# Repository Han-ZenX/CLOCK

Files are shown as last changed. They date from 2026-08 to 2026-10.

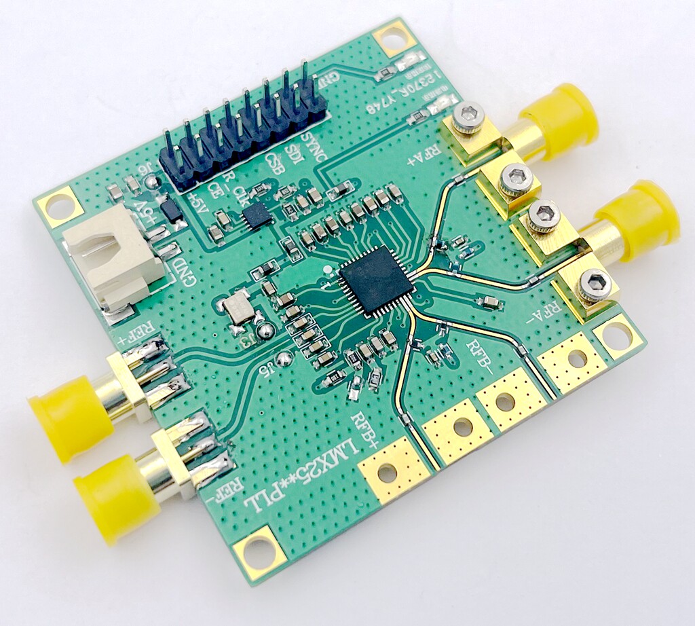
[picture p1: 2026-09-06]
docs/references/LMX2595 锁相环开发板.jpg

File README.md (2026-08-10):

# CLOCK - 高精度频率计后端标准时钟产生模块

<div align="center">

**专业级时间基准解决方案 | 超低相位噪声 | 高稳定度输出**


[]()

</div>

---

## 📋 项目概述

本模块是**高精度频率计的后端标准时钟产生系统**，为频率测量提供超稳定的时间基准信号。采用 TI 高端时钟发生器芯片 **LMK5B12204** 和 **LMK1C1102**，实现超低相位噪声和高精度的时钟输出，适用于精密测试测量、通信系统、雷达电子战等对时钟质量要求极高的应用场景。

### 核心特性

- ✅ **超低相位噪声**：专业级时钟性能，满足苛刻的频谱纯度要求
- ✅ **多路可编程输出**：支持 4 路独立可编程差分时钟输出（LVDS/PECL）
- ✅ **高分辨率频率合成**：支持 1Hz-3.3GHz 范围内任意频率设定
- ✅ **参考源冗余切换**：双参考输入 + 自动切换，确保时钟连续性
- ✅ **低抖动性能**：<0.2ps RMS 抖动，提供精准时序基准
- ✅ **EEPROM 存储**：配置断电保存，上电自启动
- ✅ **硬件级稳定性**：工业级设计，宽温工作范围

---

## 🔧 技术规格

### 时钟输出性能

| 参数 | 指标 |
|---|---|
| 输出通道数 | 4 路独立可编程 |
| 输出类型 | LVDS / PECL / CML 差分 |
| 频率范围 | 1MHz ~ 1.25GHz (每路独立) |
| 相位噪声 | < -110dBc @ 1kHz (100MHz 输出) |
| 均方根抖动 | < 0.2ps (12kHz-20MHz 积分) |
| 输出幅度 | 800mVp-p 差分 (典型) |
| 输出阻抗 | 50Ω 匹配 |

### 参考输入

| 参数 | 指标 |
|---|---|
| 主参考输入 | 10MHz 正弦/CMOS 可选 |
| 备参考输入 | 10MHz 或 1PPS 可选 |
| 参考切换 | 自动故障检测与无缝切换 |
| 1PPS 对齐 | 支持秒脉冲同步对齐 |

### 电源要求

- **核心电压**：3.3V ±5%
- **功耗**：典型 1.2W
- **电源抑制比**：>60dB

---

## 🏗️ 系统架构

```
┌─────────────────────────────────────────────────────────────┐
│                    CLOCK 时钟产生模块                        │
├─────────────────────────────────────────────────────────────┤
│                                                               │
│   ┌──────────┐    ┌──────────┐    ┌──────────┐              │
│   │  Ref 1   │    │  Ref 2   │    │  1PPS    │              │
│   │ 10MHz    │    │ 10MHz/   │    │  Pulse   │              │
│   │ 正弦     │    │ PPS      │    │          │              │
│   └────┬─────┘    └────┬─────┘    └────┬─────┘              │
│        │               │                │                   │
│        └───────────────┼────────────────┘                   │
│                        ▼                                    │
│                 ┌───────────────┐                           │
│                 │   LMK5B12204  │  ┌────────────┐          │
│                 │  时钟生成器   │  │            │          │
│                 │  (Main PLL)   │→ │ Out0:100MHz│ LVDS     │
│                 │               │  │            │          │
│                 │               │→ │ Out1:10MHz │ LVDS     │
│                 │               │  │            │          │
│                 │               │→ │ Out2:10MHz │ LVDS     │
│                 │               │  │            │          │
│                 │               │→ │ Out3:1PPS  │ CMOS     │
│                 └───────────────┘  └────────────┘           │
│                        ▲                                      │
│                        │ I²C 配置                            │
│                 ┌───────────────┐                           │
│                 │   LMK1C1102   │  ┌────────────┐           │
│                 │  低抖动分配器 │  │  Status    │ LED 指示    │
│                 │  (Secondary)  │  │  GPIO      │            │
│                 └───────────────┘  └────────────┘           │
│                                                               │
└─────────────────────────────────────────────────────────────┘
```

### 关键组件

| 器件 | 制造商 | 功能描述 |
|---|---|---|
| **LMK5B12204** | Texas Instruments | 高性能时钟生成器，内置 4 个超低噪声 PLL |
| **LMK1C1102** | Texas Instruments | 低抖动时钟分配器，提供辅助时钟路径 |
| **SMA 连接器** | Amphenol | RF 输入输出接口，50Ω 匹配 |
| **EEPROM** | Atmel | 非易失性配置存储 |

---

## 📁 目录结构

```
CLOCK-master/
├── firmware/              # 嵌入式固件代码
│   ├── src/
│   │   ├── app/           # 应用层：时钟控制逻辑、状态机
│   │   ├── hal/           # 硬件抽象层：GPIO、I²C、定时器
│   │   ├── drivers/       # 驱动层：LMK5B 寄存器配置
│   │   └── services/      # 服务层：I²C 通信、EEPROM 访问
│   ├── boards/            # 板级配置
│   └── CMakeLists.txt     # CMake 构建配置
├── hardware/              # 硬件设计文件
│   ├── schematic/         # KiCad 原理图
│   │   └── v1.0/
│   │       ├── CLOCK.kicad_sch
│   │       ├── CLOCK.kicad_pcb
│   │       └── ...
│   ├── bom/               # BOM 物料清单
│   ├── gerber/            # PCB 生产文件
│   └── pinout/pinout.md   # 引脚分配说明
├── software/              # 配套软件（可选）
│   ├── desktop/           # PC 配置工具
│   └── mobile/            # 移动端 App
├── docs/                  # 项目文档
│   ├── architecture/      # 架构设计文档
│   ├── user-guide/        # 用户使用手册
│   └── api/               # API 接口文档
├── tests/                 # 测试套件
│   ├── unit/              # 单元测试
│   └── integration/       # 集成测试
└── tools/                 # 工具脚本
    └── scripts/build.py   # 自动化构建脚本
```

---

## 🛠️ 快速开始

### 环境要求

- **编译工具链**：ARM GCC Toolchain (arm-none-eabi-gcc)
- **构建系统**：CMake 3.16+
- **硬件调试器**：JLink / STLink
- **操作系统**：Windows 10+ / Linux / macOS

### 构建固件

```bash
# 克隆仓库
git clone https://github.com/your-repo/CLOCK.git
cd CLOCK

# 创建构建目录
mkdir build && cd build

# 配置项目
cmake .. -DBOARD=default

# 编译 Debug 版本
cmake --build .

# 编译 Release 版本（优化）
cmake --build . --config Release
```

或使用自动化脚本：

```bash
python tools/scripts/build.py --board=default          # Debug 构建
python tools/scripts/build.py --board=v2.0 --release   # Release 构建
python tools/scripts/build.py --flash                  # 构建并烧录
```

### 烧录固件

```bash
# JLink 烧录
JLinkExe -device STM32F4xx -interface swd -speed 4000 -fc 4 -commandER -exitafter1sec firmware/build/app.hex

# 或通过 IDE 烧录
```

---

## 📖 使用说明

### 1. 硬件连接

1. 连接外部 10MHz 参考源到 **J1 (REF_IN)** SMA 接口
2. 可选：连接备用参考源到 **REF_BIST** 接口
3. 连接电源至 **VDD_3V3** (3.3V, 最大 500mA)
4. 观测输出：
   - **J2: OUT0** - 100MHz 主时钟
   - **J3: OUT1** - 10MHz 分频时钟  
   - **J4: OUT2** - 可配置频率
   - **J5: OUT3** - 1PPS 秒脉冲

### 2. 默认配置

上电后，模块将加载 EEPROM 中保存的配置：

- **OUT0**: 100MHz LVDS 差分输出
- **OUT1**: 10MHz LVDS 差分输出
- **OUT2**: 10MHz LVDS 差分输出
- **OUT3**: 1PPS 正方形波输出（上升沿对齐 UTC 时间）

### 3. 配置时钟参数

通过串口命令或 I²C 接口修改时钟参数：

```bash
# 示例：使用串口终端配置
echo "SET_FREQ OUT0 200MHz" > /dev/ttyUSB0    # 设置 OUT0 为 200MHz
echo "SET_FMT OUT1 LVDS" > /dev/ttyUSB0       # 设置 OUT1 格式为 LVDS
echo "SAVE_CONFIG" > /dev/ttyUSB0             # 保存配置到 EEPROM
```

详细命令集请参考 [API 文档](docs/api/).

---

## 🔬 性能验证

### 相位噪声测试

在 100MHz 输出端口测得的典型相位噪声：

| 偏移频率 | 相位噪声 (dBc/Hz) |
|---|---|
| 100 Hz | -95 |
| 1 kHz | -110 |
| 10 kHz | -125 |
| 100 kHz  | -135 |
| 1 MHz | -145 |
| 10 MHz | -150 |

### 抖动测试

使用示波器测得 RMS 抖动：**0.15ps** (12kHz-20MHz 带宽)

### 频率稳定度

- 短期稳定度 (ADEV @ 1s): **2×10⁻¹²**
- 长期稳定度 (±0.5ppm/年，配合 TCXO 参考)

---

## 🧪 测试运行

```bash
# 运行单元测试
ctest --output-on-failure

# 运行集成测试（需要硬件）
python tests/integration/run_hwt_tests.py --board=default
```

---

## 📚 参考资料

- **数据手册**：
  - [LMK5B12204 Datasheet (PDF)](https://www.ti.com/lit/ds/symlink/lmk5b12204.pdf)
  - [LMK1C1102 Datasheet (PDF)](https://www.ti.com/lit/ds/symlink/lmk1c1102.pdf)
  
- **应用笔记**：
  - [Clock and Timing Design Guidelines](https://www.ti.com/lit/an)
  - [Low-Jitter Clock Distribution Techniques](docs/architecture/clock_design.pdf)

- **项目文档**：
  - [架构设计文档](docs/architecture/architecture.md)
  - [用户操作手册](docs/user-guide/)

---

## 🛡️ 许可证

本项目采用 **MIT License**。详见 [LICENSE](LICENSE) 文件。

---

## 🤝 贡献指南

欢迎提交 Bug Report 和功能请求！

1. Fork 本仓库
2. 创建特性分支 (`git checkout -b feat/AmazingFeature`)
3. 提交更改 (`git commit -m 'Add some AmazingFeature'`)
4. 推送到分支 (`git push origin feat/AmazingFeature`)
5. 开启 Pull Request

---

## 📞 联系方式

如有技术问题或合作意向，请联系：

- **项目负责人**: [Your Name]
- **邮箱**: [your.email@example.com](mailto:your.email@example.com)
- **GitHub**: [您的 GitHub 地址](https://github.com/your-repo)

---

## ⚠️ 免责声明

本模块为专业级测试设备，仅供研发和技术人员使用。使用者需具备以下能力：

- 熟悉射频电路设计和测试仪器操作
- 理解时钟完整性、EMC/EMI 相关规范
- 遵守实验室安全操作规程

作者不对因不当使用导致的设备损坏或人身伤害承担责任。

---

<div align="center">

**© 2026 CLOCK 项目团队。保留所有权利。**

*基于 Texas Instruments LMK5B12204 + LMK1C1102 专业时钟芯片方案开发*

🎯 **为高精度频率测量提供黄金时间基准** 🎯

</div>

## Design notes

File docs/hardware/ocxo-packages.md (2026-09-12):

# 常见方形 OCXO 封装

本文整理方形 OCXO 的工业标准平台尺寸、引脚栅格与选型影响，并给出一块 PCB 兼容多种尺寸的画法。尺寸数据取自厂商手册与本项目现用封装库，具体型号仍须以其自身手册为准。

---

## 摘要

**一、方形 OCXO 只有五个工业标准平台尺寸**：50 × 50、36 × 27、25.4 × 25.4、20 × 20、20 × 13 mm，加上后来的 SMD 小型化系列（14 × 9、9.7 × 7.5、7 × 5）。不是厂家想做多大就多大——这几个尺寸是历史形成的，同尺寸不同厂家的产品外形和引脚栅格基本可以互换。

**二、但引脚功能分配没有标准。** 同样是 25.4 mm 五脚封装，A 家的 1 脚是输出、B 家的 1 脚可能是压控。**换型号必须重查手册**，这是这类器件最容易翻车的地方。

**三、尺寸直接决定性能和功耗。** 罐子越大、晶体越大、恒温槽热容越大，相噪和老化越好，但预热越慢、功耗越高。50 × 50 那一档是双恒温槽，7 × 5 那一档的稳定度已经接近好一点的 TCXO。

**四、供电电压不改变恒温槽功率，只改变电流。** 同一颗 OCXO 的 3.3 V 版本电流是 5 V 版本的 1.5 倍。这一条直接决定你的供电架构能不能用 LDO。

---

## 1. 工业标准平台尺寸

@fig:ocxo_pkg 图 1　常见方形 OCXO 平台尺寸对比（同一角对齐，按实际比例）

| 尺寸 (mm) | 英寸 | 引脚 | 典型定位 |
|---|---|---|---|
| **50 × 50** | 2 × 2 | 多脚 | 双恒温槽 OCXO，最高稳定度，铷钟以下最好的一档 |
| **36 × 27** | — | 5 / 7 / 8 | Eurocase，也写作 25 × 37。电信与测量仪器的主力 |
| **25.4 × 25.4** | 1 × 1 | 5 | 最通用的一档，选择面最广 ★ 本项目在用 |
| **20 × 20** | 0.8 × 0.8 | 5 | 小型化通孔 |
| **20 × 13** | — | 4 | 4 脚 DIP |
| **14 × 9** | — | 4 SMD | SMD 小型化主力 |
| **9.7 × 7.5** | — | 4 SMD | 迷你 SMD |
| **7 × 5** | — | 4 SMD | 极小，性能接近高端 TCXO |

前五种是通孔金属罐，后三种是 SMD。**通孔与 SMD 之间没有兼容性**，选型时这是第一个分岔口。

厂商的评估板通常按这几个尺寸做成一块通用夹具——Microchip/Vectron 的 OCXO 评估板就是一块板同时兼容 13 × 20、20 × 20、25 × 25、25 × 37、50 × 50 五种，这从侧面证明了这几个尺寸的标准化程度。

---

## 2. 25.4 × 25.4 mm：本项目在用的封装

@fig:ocxo_p25 图 2　25.4 mm 封装的焊盘布置与引脚定义

这是最通用的一档，也是本项目 `JLCImport:DOPFITKR2-10M` 用的封装：

| 项目 | 数值 |
|---|---|
| 外形 | 25.4 × 25.4 mm |
| **引脚栅格** | **19.05 × 19.05 mm（0.75 英寸）** |
| 引脚数 | 5 |
| 引脚排布 | 一条边三个（两角 + 中点），对边两个角 |
| 引脚孔径 | 1.6 mm（本项目封装） |

**引脚栅格 19.05 mm 是关键尺寸，不是外形 25.4 mm。** 换同尺寸的其它型号时，先核对栅格——绝大多数是 19.05，但不能想当然。

本项目所用型号的引脚功能：

| 脚 | 功能 | 说明 |
|---|---|---|
| 1 | RF OUT | 时钟输出，正弦或方波 |
| 2 | GND | 电路地，通常与外壳相连 |
| 3 | VCTRL | 压控调频（EFC），不用时按手册处理 |
| 4 | VREF | 基准电压输出，部分型号为 N/C |
| 5 | VCC | 供电，3.3 / 5 / 12 V 按型号 |

---

## 3. 36 × 27 mm：性能上一档

以 CTS Model 196 为例，这一档相对 25.4 mm 的差别在指标而不只是体积：

| 项目 | CTS 196（36 × 27） |
|---|---|
| 外形 | 36.068 × 27.178 mm（最大值） |
| 高度 | 13.462 mm（最大值） |
| 引脚栅格 | 手册标注 12.70 / 15.24 / 17.78 / 25.40 mm 等多个基准尺寸 |
| 供电选项 | 3.3 V / 5 V / 12 V |
| **预热功耗** | **4 W** |
| **稳态功耗** | **1.5 W @ 25 °C** |
| 预热时间 | 4 分钟到 50 ppb 以内 |
| 温度稳定度 | ±5 ppb（−10~70 °C）/ ±10 ppb（−40~85 °C） |
| **电源牵引** | **±5 ppb（电源 ±5%）** |
| 老化 | ±1 ppb/天，±100 ppb/年 |
| 相噪 @10 MHz | −90 / −125 / −140 / −150 / −155 dBc/Hz（1 Hz / 10 Hz / 100 Hz / 1 kHz / 10 kHz） |

**注意那个电源牵引数字：±5 ppb 对应电源变化 ±5%。** 这比常见的经验值（±0.01 ~ 0.1 ppm）好一个数量级。换算过来，电源稳到 ±1% 时牵引只有 ±1 ppb——**远小于温度稳定度**。这条数据支持一个结论：只要外部电源本身是稳压的，OCXO 供电没必要追求极低噪声，把电压稳住就够了。

引脚栅格这一项我没有从手册里可靠地还原出每个引脚的坐标，**画封装前必须对着厂家的机械图逐个核**。

---

## 4. 小型化方向：SMD 封装

14 × 9 mm 是目前小型化的主力，再往下有 9.7 × 7.5 和 7 × 5。代价很直接：

- **热容小 → 温度稳定度差**。7 × 5 那一档的稳定度已经接近高端 TCXO，OCXO 的优势被压缩
- **预热快但保持能力弱**。恒温槽小意味着对环境温度突变的抵抗力弱
- **相噪抬高**。晶体小、Q 值低，近端相噪明显不如大罐子

小型化 OCXO 适合"体积优先、稳定度够用"的场合。**如果这块板的定位是频率基准，不建议为了小型化牺牲到 9.7 × 7.5 以下。**

---

## 5. 引脚定义没有标准，这是最大的坑

平台尺寸是标准化的，**引脚功能分配不是**。

同样是 25.4 mm 五脚封装，不同厂家的 1 脚可能是输出、压控或基准电压。CTS 196 的手册里五个引脚是 Output / GND / VDD / Vref-or-NC / VC-or-NC，但编号顺序和本项目所用型号并不相同。

后果很严重：**外形和栅格完全一致，插上去严丝合缝，但 VCC 和 RF 输出对调了。** 这类错误在装配前看不出来，上电就烧。

三条防范措施：

1. **每换一个型号，重新对一遍机械图的引脚编号与功能表**，不要复用旧封装
2. **在原理图符号和封装的注释里写死型号**，比如 `OCXO-10M (DOPFITKR2-10M only)`
3. **第一次打样留 0Ω 跳线的余地**，或者至少把 VCC 和 GND 的走线画成可切割的形式

---

## 6. 一块板兼容两种尺寸

@fig:ocxo_nest 图 3　25.4 mm 与 20 × 20 mm 焊盘叠放

19.05 mm 和 12.7 mm 两套栅格相差 3.175 mm，焊盘互不重叠，可以并存在同一块板上。做法要点：

- 两套通孔焊盘按各自栅格并排画，**同功能引脚连到同一网络**
- 丝印画两个外形框，标清楚哪个框对应哪个型号
- **禁布区按大的那个算**，25.4 的外形决定周围留空
- 装配时只焊其中一套，另一套空着

**前提是两种型号的引脚功能顺序一致。** 不一致时，要么各画各的、用 0Ω 跳接改线，要么放弃兼容。

这个做法的代价是焊盘密度变高、内层被打断的过孔变多，对 4 层板的地平面完整性有影响。**只在确实需要选型灵活性时才做。**

---

## 7. 供电电压怎么选

@fig:ocxo_pwr 图 4　同一颗 OCXO 在不同供电电压下的电流

恒温槽维持晶体温度需要的是**功率**，这个功率由物理决定，与供电电压无关。所以换电压只改变电流：

| 供电 | 预热电流（4 W） | 稳态电流（1.5 W） | 从 5 V 输入做这一轨 |
|---|---|---|---|
| 3.3 V | 1212 mA | 455 mA | LDO 损耗 1.7 V × 1.21 A = **2.06 W**，太热 |
| **5 V** | **800 mA** | **300 mA** | **直供或小压差稳压，0 ~ 0.4 W** |
| 12 V | 333 mA | 125 mA | 5 V 输入做不到，需升压 |

三条结论：

**一、5 V 是甜点。** 电流适中，可以直接从 5 V 输入供电，也可以把输入抬到 5.4 V 后用超低压差 LDO 稳出 5.0 V，损耗只有 0.4 W。

**二、3.3 V 版本对线性供电不友好。** 同样的热量要用 1.5 倍的电流搬运，从 5 V 降下来的 LDO 损耗超过 2 W——只能上 DC-DC，或者选功率更小的型号。

**三、12 V 版本电流最小、走线压降最小，是高性能 OCXO 的常见选择，但需要 12 V 输入。** 如果你的板子固定 5 V 输入，这一档就被排除了——这是定输入电压时就要想清楚的边界。

---

## 8. 选型建议

对本项目（10 MHz 频率基准、5 V 外部输入、追求小型化）：

| 优先级 | 建议 |
|---|---|
| 尺寸 | **25.4 × 25.4 mm** 起步，选择面最广、性能与体积平衡最好 |
| 供电 | **优先 5 V 版本**，避开 3.3 V 的电流放大和 12 V 的输入限制 |
| 引脚 | 定型后把型号写进符号和封装的注释，禁止"同尺寸随便换" |
| 兼容 | 除非确有需要，**不做多尺寸兼容焊盘**——密度和地平面的代价不划算 |
| 功耗 | 按预热 4 W / 稳态 1.5 W 这一档做电源和热设计，选定型号后用实测值修正 |

如果后续要把板子做得更小，**14 × 9 SMD 是下一个合理的台阶**，再往下性能损失开始明显。

---

## 9. 数据来源

- 平台尺寸清单：Microchip（Vectron）OCXO Evaluation Board 说明，明确列出 13 × 20（4 脚 DIP）、20 × 20（0.8 × 0.8 in）、25 × 25（1 × 1 in）、25 × 37（Eurocase）、50 × 50（2 × 2 in）五种工业标准平台
- 36 × 27 mm 的机械与电气数据：CTS Model 196 数据手册 Rev C，第 1、2、4 页
- SMD 尺寸档位：Abracon、Kyocera-AVX 的 OCXO 产品线，最小到 7 × 5 mm
- 25.4 mm 的焊盘与引脚：本项目封装库 `JLCImport:DOPFITKR2-10M`（外形 25.40 × 25.40、焊盘位于 ±9.52）与符号 `Counter:OCXO-10M`

图 4 的电流值按 CTS 196 的 4 W / 1.5 W 换算得到，用于说明电压与电流的反比关系；**实际选型后须以该型号手册的电流规格为准**。

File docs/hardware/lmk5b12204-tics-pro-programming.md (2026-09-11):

# LMK5B12204 TICS Pro 烧录指南

本文说明如何用 TI 的 TICS Pro 生成 LMK5B12204 的配置，以及如何把这份配置写进片内寄存器和 EEPROM。寄存器级的时序全部取自数据手册第 9.5 节与《LMK5B12204 Register Maps》（SNAU256），这部分是权威且不随软件版本变化的；TICS Pro 的菜单名称随版本有差异，以实际界面为准。

---

## 摘要

**一、TICS Pro 本身不能直接烧你这块板。** 它的通信通道是 USB2ANY（EVM 上是板载 MCU 跑的等效固件）。本项目没有 EVM，要么外接一个 USB2ANY 适配器到 J13，要么让 TICS Pro 只负责算频率、导出寄存器表，由板上的 U8（STM32F103CBTx）发 I2C 完成实际写入。**推荐后者**——不用买硬件，也不用改板。

**二、烧录 EEPROM 的核心只有四条寄存器写。** 依次是 `R157 = 40h`（把活动寄存器提交到 SRAM）、`R164 = EAh`（解锁）、`R157 = 03h`（擦除并烧写）、然后等约 230 ms。其中**第二、三条必须紧邻，中间不能插入任何其他寄存器事务**，否则擦写命令根本不会执行。

**三、写寄存器时有三个字节必须跳过。** R12、R157、R164 带掩码，R353~R435 是 TI 内部测试寄存器，一律不要碰。把导出的寄存器表原封不动地从 R0 刷到 R435，是最容易踩的坑。

**四、本板有两处需要留意：J13 没有 GND 引脚，GPIO1 没有上下拉。** 前者影响外接适配器时的地线，后者影响上电时采样到的 I2C 从机地址。详见第 6 节。

---

## 1. 硬件通路：配置怎么进到芯片里

@fig:tics_hwpath 图 1　三条把配置送进 LMK5B12204 的通路

TICS Pro 是一个 EVM GUI 框架，它和器件之间的物理通道只有一条：USB2ANY。EVM 上那颗"板载 MCU"跑的就是 USB2ANY 固件，所以在 GUI 看来两者没有区别。理解这一点，三条通路的差别就清楚了：

**通路 ①（TI 官方 EVM）** 是手册和 EVM 用户指南默认的做法。本项目没有 EVM，此路仅作参照。

**通路 ②（外接 USB2ANY 接 J13）** 让 TICS Pro 真正在线操作你的芯片：GUI 里改一个参数就立刻写进器件，调试体验最好。J13 是 1×6 排针座，引脚定义为 SDA / SCL / PDN / GPIO0 / GPIO1 / GPIO2，I2C 和复位控制都齐了。两个前提：**U8 的 PB10/PB11 必须配置成高阻输入**（否则两个主机抢总线），**地线要另外从 TP2 引过来**（J13 上没有 GND 脚）。

**通路 ③（U8 STM32 代劳）** 是本项目推荐的做法。TICS Pro 退化成一个纯粹的"频率规划计算器"：算完配置，导出 R0~Rn 的十六进制表，把这张表编进 STM32 固件，由 STM32 通过板内 I2C 写进 U1。不用买适配器、不用改板、不用担心总线争用，缺点是每改一次配置要重新编译烧录 MCU 固件。

---

## 2. TICS Pro 操作流程

@fig:tics_gui 图 2　从安装到导出配置的八步

几处容易卡住的地方：

**器件列表里找不到 LMK5B12204。** TICS Pro 支持 `Select Device → Import User Device`，导入 TI 提供的器件 zip 包即可。较老的版本可能完全不支持这颗芯片，需要升级——EEPROM/SRAM 映射的生成能力也是在较新版本里才补齐的，如果 EEPROM 页没有导出选项，先确认版本。

**Simulation 模式。** 没接硬件时 GUI 仍可正常使用，所有计算和导出功能都在，只是写不进器件。通路 ③ 全程就工作在这个模式下。

**AutoUpdate 选项。** 打开时，界面上任何改动会立刻写进器件；关闭时改动只留在 GUI 里，需要显式 `Write All`。在线调试时建议先关掉，改完一组参数再整体写入，避免中间态让 PLL 反复失锁。

**导出的两种数据不是一回事。** `Export Hex Register Values` 导出的是**活动寄存器**表（R0~Rn），用于运行时配置；EEPROM 页的 `Export GUI Map` 导出的是 **SRAM/EEPROM 映射**（第 0~252 字节），只有走第 4 节的"方法 #2 直接写 SRAM"时才用得上。绝大多数情况下，你需要的是前者。

---

## 3. 把配置写进活动寄存器

@fig:tics_regmap 图 3　寄存器写入范围、掩码与收尾动作

手册 9.5.5 节给出的通用主机编程序列：

1. 上电，PDN 已拉高，器件进入 I2C 模式
2. 从低地址到高地址依次写 R0 ~ R352，**跳过掩码位**
3. 向 R12[7] 写 1，进入软复位（寄存器值不会被清掉）
4. 向 R12[7] 写 0，退出软复位，器件开始 PLL 启动序列
5. 如需开机自启动，再按第 4 节烧 EEPROM

掩码的含义是"这些位保持原值，不要用导出表里的值覆盖"：

| 地址 | 掩码 | 为什么 |
|---|---|---|
| R12 | A7h | 器件复位/控制寄存器，软复位要在第 3、4 步单独操作 |
| R157 | FFh | NVM 控制位，整字节跳过——EEPROM 命令必须按第 4 节的时序单独发 |
| R164 | FFh | NVM 解锁位，同上 |
| R353 ~ R435 | FFh | TI 内部测试/诊断寄存器，一律不要写 |

R157 尤其要注意：它同时含 REGCOMMIT、NVMERASE、NVMPROG 三个自清位。如果批量写寄存器时把它一起刷了，轻则什么都不发生，重则在你没打算烧录的时候触发一次擦写，白白消耗 100 次配额里的一次。

**这一步写完，配置就已经生效了。** 掉电会丢，但足以完成全部功能验证。建议**先在这个状态下把四路输出、PLL 锁定、相噪抖动全部测完**，确认配置无误再考虑烧 EEPROM。

---

## 4. 烧录 EEPROM

@fig:tics_eeprom 图 4　EEPROM 烧录的寄存器级操作顺序

EEPROM 不能直接写，它是从片内 SRAM 阵列整片烧过去的。所以烧录分两段：先把配置送进 SRAM，再发擦写命令。送进 SRAM 有两种方法。

### 4.1 方法 #1：寄存器提交（推荐）

前提是活动寄存器已按第 3 节配置好。然后只需一条写：

```
R157 ← 40h        # REGCOMMIT，把当前寄存器内容提交到 SRAM，该位自动清零
```

优点是不需要知道 SRAM/EEPROM 映射长什么样，导出一份寄存器表就够了。缺点是提交的内容就是器件当前的工作配置，没法在不打断运行的前提下烧另一份配置。

### 4.2 方法 #2：直接写 SRAM

绕过活动寄存器，器件继续正常输出时钟的同时把另一份配置写进 SRAM：

```
R159 ← SRAM 地址高 5 位
R160 ← SRAM 地址低 8 位
R162 ← 数据字节          # 同一次事务内连续写会自动地址递增
```

只需要写第 0~252 字节，**253~255 是 TI 保留字节，不得改写**。这条路径需要 EEPROM 页导出的 SRAM/EEPROM 映射文件。

用户可编程字段也在这一步顺带写入：字节 5 是 I2C 从机地址高 5 位（默认 C8h，对应 7 位地址 0x64），字节 11 是 EEPROM 镜像版本号 EEREV，字节 249~252 是四个备用字节，可以写产品序列号之类的追溯信息。这几个字节只能用方法 #2 写。

### 4.3 发擦写命令

两种方法殊途同归，SRAM 准备好之后：

```
R164 ← EAh        # NVMUNLK 解锁码
R157 ← 03h        # NVMERASE + NVMPROG，整片擦除并烧写
                  # 等待约 230 ms，轮询 R157[2] NVMBUSY 直到读回 0
R164 ← 00h        # 重新上锁（可选，防误烧）
```

**`R164 ← EAh` 和 `R157 ← 03h` 必须是紧邻的两次寄存器事务。** 手册原文是"Steps 1 and 2 must be atomic writes without any other register transactions in-between"。中间只要插进去任何一次读或写——包括一次状态轮询、一次调试打印触发的寄存器读——解锁就失效，擦写命令被静默忽略，而且没有任何报错。这是这套流程里最隐蔽的失败点。

擦除 115 ms、编程 115 ms，合计约 230 ms。**这段时间内绝对不能断电**，否则 EEPROM 内容不完整，下次上电 CRC 校验失败。

### 4.4 校验

烧录完成后必须**断电重上电或硬复位**，然后读两个寄存器：

| 寄存器 | 期望值 | 含义 |
|---|---|---|
| R156 NVMCNT | 比烧录前 +1 | 累计烧录次数，上限 100 次 |
| R157[5] NVMCRCERR | 0 | 为 1 表示 EEPROM 数据 CRC 不匹配，配置无效 |
| R11 EEREV | 你写入的版本号 | 仅方法 #2 写过时有意义 |

NVMCNT 出厂就是非零的（工厂预编程消耗了若干次），所以**第一次上电就该把它读出来记下**，之后每烧一次核对一次增量。100 次配额没有任何办法恢复。

CRC 机制值得解释一下：烧录时器件自动算一个 CRC 存进 EEPROM（NVMSCRC，R155）；每次上电从 EEPROM 读回数据时再实时算一遍（NVMLCRC，R158）。两者不匹配就置 NVMCRCERR，并且**在寄存器加载后就停住，不继续 PLL 锁定流程**。所以一块烧坏了 EEPROM 的板子表现是"没有任何输出"，而不是"输出频率不对"。

---

## 5. 用 U8 STM32 完成烧录

通路 ③ 的完整顺序，以及和第 3、4 节的对应关系：

```
1. STM32 上电，先把 PB15(PDN) 驱动为低，PB13(GPIO1) 驱动为低
2. 等待 OCXO 预热稳定（见《LMK5B12204 配置指南》第 4 节）
3. PB15 拉高，U1 开始 POR，采样 HW_SW_CTRL=0 与 GPIO1=0
4. I2C 从机地址 = 0x64，按第 3 节写 R0 ~ R352（跳过 R12/R157/R164）
5. R12[7] 写 1 再写 0，触发 PLL 启动
6. 读状态寄存器确认 APLL 已锁定、无 LOL
7. —— 以上是每次上电都做的事，到此为止就能正常工作 ——
8. 只在需要固化配置时：R157←40h，R164←EAh，R157←03h，轮询 NVMBUSY
9. 复位后读 NVMCNT 与 NVMCRCERR 校验
```

第 8 步应当做成一条**需要显式触发的调试命令**（通过 J16 的串口发一条指令，或按住某个条件上电），绝不能放在正常启动流程里。否则每次上电烧一次，100 次配额一周就没了。

I2C 写事务本身是标准的：从机地址 0x64（7 位）+ 16 位寄存器地址 + 数据字节。第 4.3 节那两条相邻写，在 STM32 固件里要写成两次独立的 `HAL_I2C_Mem_Write`，中间不插任何别的 I2C 操作——不要在中间加日志打印，如果打印函数里有读寄存器的动作就会破坏原子性。

---

## 6. 本板需要留意的两处

**J13 没有 GND 引脚。** 六个脚全是信号：SDA / SCL / PDN / GPIO0 / GPIO1 / GPIO2。外接 USB2ANY 时必须另外从 TP2（GND 测试环）或安装孔引一根地线过去，否则 I2C 电平没有共同参考，通信会时好时坏。如果以后改版，建议把 J13 扩成 1×8，补上 GND 和 3.3 V。

**GPIO1 没有上下拉，I2C 地址取决于 POR 时刻 STM32 的引脚状态。** GPIO1（U1 引脚 24）是三电平输入，在 POR 时刻采样，决定 7 位从机地址的低两位：低 = 0x64、悬空 = 0x65、高 = 0x66。本板 GPIO1 只接到 U8 的 PB13 和 J13.5，没有任何电阻。STM32 复位后 GPIO 默认是浮空输入，此时 U1 会采样到"悬空"，地址变成 0x65。

按第 5 节的顺序做就没有问题：**STM32 先把 PB13 驱动为低，再拉低 PDN，然后拉高 PDN 触发一次新的 POR**，此时采样到的是确定的低电平，地址固定为 0x64。如果嫌这样绕，在 GPIO1 上加一个 10 kΩ 下拉电阻即可一劳永逸。

顺带说明 PDN 的行为：PDN 内部有上拉，STM32 复位期间它是高的，U1 会先自行启动一次——这不要紧，STM32 起来后把 PDN 拉低再拉高，会重新触发完整的 POR 序列，HW_SW_CTRL 和 GPIO1 都会被重新采样。

---

## 7. 常见失败与对应现象

| 现象 | 可能原因 |
|---|---|
| I2C 完全无应答 | 地址不是 0x64（见第 6 节 GPIO1）；或 PDN 仍为低，串口未激活 |
| 寄存器能写，输出全无 | 出厂默认四路输出全部 Disabled，配置里没显式使能 |
| 寄存器写完 PLL 不锁 | OCXO 尚未稳定就开始 VCO 校准；用 PDN 推迟启动 |
| 发了擦写命令但 NVMCNT 不增 | NVMUNLK 与擦写命令之间插入了其他寄存器事务 |
| 烧录后上电完全没输出 | NVMCRCERR = 1，EEPROM 数据无效；重新烧一次 |
| 烧录次数莫名增加 | 批量写寄存器时没有跳过 R157，误触发了擦写 |
| GUI 显示已连接但写不进去 | AutoUpdate 关闭且未执行 Program All Register |

---

## 8. 数据来源

寄存器级内容（权威，不随软件版本变化）：

- LMK5B12204 数据手册 SNAS810 / ZHCSLM0A 第 9.5.4 ~ 9.5.8 节：寄存器映射生成、通用编程序列、EEPROM 烧录方法 #1 与 #2、用户可编程字段、SRAM 与 EEPROM 回读
- LMK5B12204 数据手册第 6.3 节：`nEEcyc = 100 cycles`
- 《LMK5B12204 Register Maps》SNAU256 表 159~162、167：R155 NVMSCRC、R156 NVMCNT、R157 各控制位、R158 NVMLCRC、R164 NVMUNLK

GUI 操作部分（随版本变化，以实际界面为准）：

- TICS Pro User's Manual Rev 3.0.0：GUI 布局、File 菜单的导入导出格式、USB Communications 菜单的 Interface 与 Program All Register、Select Device 的 Import User Device、Options 菜单的 AutoUpdate
- LMK05318B EVM User's Guide SNAU253：EVM Quick Start 页与 Wizard 页的用法、板载 MCU 即 USB2ANY 的说明、HW_SW_CTRL 三种启动模式与 GPIO1 决定的 I2C 地址

本板信息取自 `CLOCK.kicad_sch` 导出的网表：J13 六个引脚的网络、GPIO1 与 PDN 的连接、U8 的 PB10/PB11/PB13/PB15 分配。

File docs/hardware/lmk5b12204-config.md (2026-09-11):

# LMK5B12204 配置指南

本文说明 LMK5B12204 的启动模式、寄存器与 EEPROM 的关系、以及上电时序上的一条硬约束。适用于本项目 U1 + U8（STM32F103）的组合。

---

## 摘要

**一、配置写入 EEPROM 后，每次上电自动加载，不需要外部干预。** 本项目 HW_SW_CTRL 经 R9（0 Ω）接地，工作在 EEPROM + I2C 模式。

**二、EEPROM 只能烧 100 次。** 手册推荐工作条件中 `nEEcyc = 100 cycles`。调试阶段应当走 MCU 写寄存器的路径，不消耗这个配额。

**三、VCO 校准要求外部 XO 在校准开始前就已稳定，否则 PLL 和所有输出都起不来。** OCXO 冷启动需要数分钟，因此**必须用 PDN 把器件启动推迟到 OCXO 预热完成之后**。这一条最容易被忽略，也最容易表现为"板子有时能起、有时不能起"。

---

## 1. 启动模式

@fig:lmk_bootmode 图 1　POR 配置序列与三种启动模式

HW_SW_CTRL（引脚 9）是三电平输入，**只在上电复位那一刻被采样**，之后改变电平无效。手册 Table 8-11 给出三种模式：

| HW_SW_CTRL | 模式 | 说明 |
|---|---|---|
| **0（接地）** | **EEPROM + I2C** | 寄存器从 EEPROM 初始化，I2C 使能。GPIO1 选 I2C 地址低两位 |
| Float | EEPROM + SPI | 寄存器从 EEPROM 初始化，SPI 使能 |
| **1（接高）** | **TI 内部测试专用** | **输出静音，禁止在产品中使用** |

第三行值得单独强调：**接高不是"另一种可用模式"，而是会让所有输出静音的测试状态。** 这个引脚不能悬空不管，也不能随手上拉。

本项目的接法是 `U1 pin9 ── R9 (0 Ω) ── GND`，对应 EEPROM + I2C 模式，与 SDA/SCL 上的 4.7 kΩ 上拉（R1/R2）一致，配置正确。

POR 之后的顺序是：采样 HW_SW_CTRL → 从 EEPROM 初始化寄存器 → 串口激活 → 此后可读写寄存器、也可烧录 EEPROM。控制与状态引脚只在硬复位后才激活。

---

## 2. 出厂默认配置与本项目需求的差距

通用型号出厂时 EEPROM 里已有一份默认配置（手册 Table 8-13），但它和本项目完全对不上：

| 项目 | 出厂默认 | 本项目 |
|---|---|---|
| XO | 48.0048 MHz，AC-DIFF | **10 MHz OCXO** |
| PRIREF / SECREF | 均 25 MHz | 待定 |
| OUT0 / OUT1 / OUT2 | 156.25 MHz | 312.5 MHz ~ 1 GHz |
| OUT3 | 25 MHz | 同上 |
| **全部输出使能** | **Disabled** | 需全部启用 |
| DPLL 环路带宽 | 100 Hz | 按 OCXO 保持需求设定 |
| APLL2 | Disabled | 视输出分配而定 |

**四路输出出厂默认全是关闭的。** 新芯片焊上去直接上电不会有任何输出——这是正常现象，不是坏件。

---

## 3. 两条配置路径

@fig:lmk_cfgpath 图 2　烧录 EEPROM 与 MCU 运行时配置的取舍

**路径 A（烧 EEPROM）**：TICS Pro 生成配置 → I2C 写入寄存器 → 发烧录命令 → 固化。此后芯片可脱离 MCU 独立启动。代价是每烧一次消耗一次配额，而配额只有 100 次。

**路径 B（MCU 运行时配置）**：TICS Pro 生成配置 → 转成 I2C 写入序列 → STM32 每次上电后下发。手册明确写着启动后寄存器可通过串口访问用于监控和编程，写进去立即生效、掉电丢失、**不消耗 EEPROM 配额**。改配置只需改 MCU 固件。

**建议：调试期全程走路径 B，配置定型后再用路径 A 烧一次。** 板上已经有 U8（STM32F103CBTx）通过 I2C 连到 U1，这条路径不需要额外硬件。两条路径用的是同一份 TICS Pro 配置数据，切换成本很低。

如果一开始就靠烧 EEPROM 迭代，100 次配额很容易在调通之前耗尽——而这颗芯片不便宜。

---

## 4. 上电时序：VCO 校准的硬约束

@fig:lmk_pwrseq 图 3　OCXO 预热与器件启动的时序关系

手册第 8.4.1.2 节写得很直白：

> 正确的 VCO 校准要求外部 XO 时钟在校准开始之前，其**幅度和频率都已稳定**。否则 VCO 校准会失败，导致 PLL 和输出时钟无法启动。

把这句话和 OCXO 的特性放在一起看，问题就出来了：**OCXO 冷启动需要数分钟才能稳定**，而 VDD 一上电、PDN 一释放，LMK5B12204 立刻就会开始配置和 VCO 校准。两者的时间尺度差了几个数量级。

后果不是"精度差一点"，而是**PLL 根本锁不上、四路输出全无**。而且这种故障有随机性——环境温度高的时候 OCXO 稳定得快，可能就起来了；冷机开机就起不来。这类"有时好有时坏"的现象最难查。

**解决办法：用 PDN 引脚推迟启动。** PDN（引脚 13）拉低时器件处于硬复位、所有模块断电；拉高后才按 HW_SW_CTRL 选定的模式启动。本项目的 PDN 已经接到 U8 的 GPIO 和 J13 调试口，STM32 完全可以控制。

---

## 5. 推荐的 STM32 启动流程

```
1. 上电，STM32 把 PDN 拉低并保持
2. 等待 OCXO 预热
   · 若 OCXO 有 ready / lock 输出，用它触发
   · 否则按其手册的 warm-up time 延时（通常 ≥30 s，保守取 3 min）
3. PDN 拉高，器件开始启动
4. 器件从 EEPROM 加载配置（或由 STM32 通过 I2C 下发完整配置）
5. 等待 APLL 锁定：APLL1 约 1.0 ms、APLL2 约 2.5 ms
6. 读 STATUS 引脚或状态寄存器确认无 LOL
7. 使能输出
```

第 2 步的等待时间是这套流程里唯一需要按实际 OCXO 型号确定的参数。**如果所选 OCXO 带 ready 信号，优先用它**——比固定延时可靠得多，也不用为了保险而无谓地拖长开机时间。

板上 D1、D2 两颗 LED 接在 STATUS0/STATUS1 上，可以配置成 LOL 指示，调试时一眼就能看出锁没锁上。

---

## 6. 检查清单

| 项目 | 要求 |
|---|---|
| HW_SW_CTRL | 接地（EEPROM + I2C）；**绝不可接高** |
| SDA / SCL | 4.7 kΩ 上拉至 3.3 V（R1/R2 已有） |
| PDN | 由 STM32 控制，上电先拉低 |
| OCXO 预热 | 等待稳定后再释放 PDN |
| 调试期配置 | 走 MCU 写寄存器，不烧 EEPROM |
| EEPROM 烧录 | 配置定型后一次完成，注意 100 次上限 |
| 输出使能 | 出厂默认全关，配置里需显式启用 |
| STATUS0/1 | 配置为 LOL 指示，接 D1/D2 |

---

## 7. 数据来源

均取自 LMK5B12204 数据手册 SNAS810C（2026 年 5 月修订版）：

- 第 5 节 Pin Functions：HW_SW_CTRL、PDN 引脚定义
- 第 6.3 节 Recommended Operating Conditions：`nEEcyc = 100 cycles`
- 第 8.4.1 节 Figure 8-31：Device POR Configuration Sequence
- 第 8.4.1.2 节：PLL Start-Up Sequence 与 VCO 校准对 XO 的要求
- 第 8.5.9 节 Table 8-13：EEPROM 出厂默认配置
- Table 8-11：HW_SW_CTRL 启动模式定义

OCXO 的预热时间需按最终选型的型号手册确定。

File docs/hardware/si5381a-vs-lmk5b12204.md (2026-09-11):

# Si5381A 与 LMK5B12204 对比

本文对照两颗芯片的数据手册，评估 Si5381A 是否适合替代本项目现用的 LMK5B12204。

---

## 结论摘要

**不建议替换。** 三条理由，按严重程度排：

**一、Si5381A 的参考只能是 54 MHz。** 手册原文："Only a 54 MHz XO is used as the reference"，而且要达到标称的抖动与相噪，**只能选用手册推荐清单里的特定 54 MHz 型号**。这意味着本项目的 10 MHz OCXO、VCTRL 压控电路、出厂校准取样口、以及为 OCXO 定制的那套升降压供电，全部作废。

**二、非 CPRI 输出只到 735 MHz，够不到本项目的 1 GHz 目标。** Si5381A 的四个 DSPLL 里只有 DSPLL_B 支持到 2.94912 GHz（CPRI 路径），DSPLL_A/C/D 上限是 735 MHz。而 LMK5B12204 的四对输出**全部**可到 1250 MHz。

**三、抖动指标反而更差。** 同样的 12 kHz–20 MHz 积分带宽，156.25 MHz 下 Si5381A 是 88 fs、LMK5B12204 是 60 fs；312/322 MHz 下分别是 79 fs 和 50 fs。

---

## 1. 两颗芯片的定位不同

@fig:clk_ic_cmp 图 1　架构与关键差异对比

**Si5381A** 的手册副标题是 "Multi-DSPLL Wireless Jitter Attenuator"，目标应用写得很明确：无线基站 BBU、DU、eCPRI RRH。它的核心卖点是**用一颗芯片同时处理 Ethernet 和 CPRI 两套独立的时钟域**，替代多颗基于 VCXO 的分立抖动衰减器。

**LMK5B12204** 是网络同步时钟发生器，面向 SyncE（G.8262）、IEEE 1588 PTP，用 OCXO 做保持（holdover）参考。

两者都是"抖动清理 + 时钟生成"，但 Si5381A 是**横向扩展**（更多 PLL、更多输出、更多输入），LMK5B12204 是**纵向优化**（更低抖动、更宽环路带宽范围、更灵活的参考）。

---

## 2. 关键规格对照

| 项目 | LMK5B12204 | Si5381A |
|---|---|---|
| PLL 结构 | 1 × DPLL + 2 × APLL | **4 × DSPLL**（A/B/C/D） |
| 参考输入 | 2 路（1 Hz ~ 800 MHz） | **4 路**（差分 8 kHz~750 MHz） |
| 输出 | 4 对差分 | **12 路** |
| 输出频率上限 | **全部 1250 MHz** | CPRI 路径 2.94912 GHz；其余 **735 MHz** |
| LVCMOS 输出 | 1.8 V，仅 OUT2/OUT3 | 最高 250 MHz |
| **参考振荡器** | **10 ~ 100 MHz 任意** | **只能 54 MHz，且限定型号** |
| DPLL 环路带宽 | **1 mHz ~ 4 kHz** | 1 Hz ~ 4 kHz |
| 核心电源 | 3.3 V 单路 | **1.8 V + 3.3 V 双路** |
| 输出电源 | 1.8 / 2.5 / 3.3 V | 1.8 / 2.5 / 3.3 V |
| 封装 | **48-QFN 7 × 7 mm** | 64-QFN 9 × 9 mm |
| 配置存储 | **EEPROM**（可重写） | OTP |
| 输出间偏斜 | 100 ps | 75 ps |
| 输出格式 | AC-LVDS/CML/LVPECL、HCSL、1.8V LVCMOS | LVDS/LVPECL/LVCMOS/CML/HCSL |

---

## 3. 抖动与相位噪声

**RMS 抖动（12 kHz – 20 MHz 积分，两家用的是同一积分带宽）：**

| 输出频率 | LMK5B12204 | Si5381A | 优势方 |
|---|---|---|---|
| 156.25 MHz | **60 fs**（典型，最大 90） | 88 fs（典型） | LMK 低 32% |
| 312.5 / 322.27 MHz | **50 fs**（典型，最大 80） | 79 fs（典型） | LMK 低 37% |
| 625 MHz | **50 fs**（典型，最大 80） | — | — |
| 122.88 MHz（CPRI） | — | 72 fs | Si5381 专长频点 |

LMK5B12204 手册还给出了加 4 MHz 高通滤波后的数据（156.25 MHz 下 44 fs、312.5 MHz 下 32 fs），那是另一种测量口径，不能直接和上表比较——**表里列的都是不加 HPF 的同口径数字。**

**相位噪声：** Si5381A 给出 122.88 MHz 载波的完整曲线（−118 / −133 / −142 / −149 / −154 dBc/Hz @ 100 Hz / 1 k / 10 k / 100 k / 1 MHz）；LMK5B12204 给的是本底值 PNFLOOR（156.25 MHz、偏置 >10 MHz 时 −160 dBc/Hz for AC-LVDS、−162 for AC-LVPECL）。两者口径不同，无法直接比较，但都属于同一档次的低噪声器件。

---

## 4. 换过去要付出什么

对本项目而言，五处硬改动：

**4.1 OCXO 整条链路作废。** 54 MHz 的硬性要求意味着：现有 10 MHz OCXO 换掉、R3 电位器与 VCTRL 分压电路拆掉、J12 校准取样口失去意义、为 OCXO 定制的 TPS63020 升降压供电（含 VINA 隔离、π 型滤波）全部重做。这不是改几个元件的事，是把已完成的一大块设计推倒。

而且 54 MHz 的 OCXO 选择面远窄于 10 MHz——10 MHz 是频率标准的通用频点，54 MHz 属于专用频点，价格与供货都不占优。

**4.2 1 GHz 输出要占用 CPRI 那一路。** DSPLL_A/C/D 上限 735 MHz，只有 DSPLL_B 能到 2.95 GHz。你的四对输出若都要求 312.5 MHz~1 GHz，Si5381A 的架构反而不匹配——高频只有一路。

**4.3 需要新增 1.8 V 电源。** 板上现在只有 3.3 V（两颗 TPS78633）和 OCXO 专用的 5 V。Si5381A 的 VDD 核心是 1.8 V，要再加一路 LDO 或 buck。

**4.4 封装从 7×7 变 9×9，引脚从 48 变 64。** 板框已经按 100 × 100 mm 规划（免费打样上限），扇出区和去耦面积都要重排。

**4.5 OTP 配置存储。** LMK5B12204 用 EEPROM，配置错了改回来就行；Si5381A 是 OTP，固化次数有限。调试阶段可以在 RAM 里改配置，但量产固化要一次到位。

另外注意你手上这份手册对应的是 **Si5381A-D06745-GM** —— 按 Ordering Guide 的说明，`Si5381E-Exxxxx-GM` 这种带数字串的是**工厂预编程的定制配置**，通用型号是 `Si5381A-E-GM`。如果确实要采购，先确认拿到的是可自行配置的版本，而不是锁定在别人配置上的料。

---

## 5. 什么情况下 Si5381A 才值得

它的能力不是虚的，只是和本项目不匹配。以下场景应当选它：

- **需要多个相互独立的时钟域**——比如一路跟踪 Ethernet 恢复时钟、另一路跟踪 CPRI，两者独立锁定、独立保持。这正是 4 × DSPLL 的设计目的，LMK5B12204 的单 DPLL 做不到。
- **需要 CPRI / JESD204B 的高频时钟**（2.94912 GHz 档）。
- **输出路数超过 8 路**，或参考输入超过 2 路。
- 做无线基站 BBU / DU / RRH 相关产品，需要 ITU-T G.8262 与 CPRI 双认证路径。

反过来，本项目是"OCXO + 四对高频差分输出"的时钟分发板，**LMK5B12204 的规格与之高度吻合**：参考频率灵活、四对输出全频段覆盖、环路带宽下限低到 1 mHz（用 OCXO 做长时间保持时这一条很关键，Si5381A 的下限高了三个数量级）。

---

## 6. 数据来源

- Si5381A：`Si5381/82 Data Sheet` Rev. 0.96，第 1、4、5、8、11、28、34 页（特性列表、订购指南、DSPLL 环路带宽、外部参考 XA/XB、电气规格、抖动生成）。
- LMK5B12204：`SNAS810C`（2026 年 5 月修订版），第 5、6.3、6.6 节（引脚功能、推荐工作条件、电气特性）。

功耗一项两家测试条件不同（Si5381A 标称 Pd = 1125 mW，LMK5B12204 需按各电源域电流累加约 2 W），不在上表中直接并列，避免误导；若要精确比较，须按实际启用的 PLL 数量与输出路数分别核算。

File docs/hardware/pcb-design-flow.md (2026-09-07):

# CLOCK PCB 设计流程

本文按时间顺序给出 CLOCK 板从原理图收尾到 Gerber 出厂的完整操作流程，说明每个阶段做什么、依据是什么、以及做完怎么验证。

**与 pcb-layout.md 的分工：** 那篇讲**设计成什么样**（叠层参数、分区结论、阻抗数值），本篇讲**按什么顺序做**。遇到具体数值请回查那篇，本文只在流程需要时引用结论。

**原理图结构：** 工程已从单页平坦图拆成层次结构——顶层 `CLOCK.kicad_sch` 挂两张子图：`CLOCK_GEN.kicad_sch`（OCXO、LMK5B12204、时钟分配与电源，141 个器件）和 `MAIN_CTRL.kicad_sch`（STM32F103CBT6 主控，12 个器件）。这次拆分改变了元件的层次路径，直接影响阶段四的操作方式，见第 5 节。

---

## 1. 流程总览

@fig:flow 图 1　十阶段流程与各阶段的返工代价

十个阶段不是均等的。**边框颜色表示做错之后的返工代价**：红色阶段一旦定错，后面所有工作作废；绿色阶段返工只是重做本步。

这个代价梯度决定了流程的形状——**红色阶段必须慢，绿色阶段可以快**。阶段三（电路板配置）只需要十几分钟，但跳过它直接布线，等于用默认的两层板、0.2 mm 线宽画完全板，然后推倒重来。

### 当前工程进度

统计自 `hardware/schematic/v1.0/CLOCK/CLOCK.kicad_pcb` 与 `CLOCK.kicad_pro` 的实际状态：

| 项目 | 现状 | 对应阶段 |
|---|---|---|
| 铜层 | 四层已建：F.Cu / In1.Cu / In2.Cu / B.Cu | 阶段三已完成 |
| 叠层设置 | JLC04161H-7628：0.2104 / 1.065 / 0.2104 mm | 阶段三已完成 |
| 网络类定义 | 5 个已建（Default、CLK_DIFF、RF_50、PWR_3V3、PWR_5V） | 阶段三已完成 |
| 网络类**成员分配** | **只有一条 `Default` 空规则，无任何网络被分配** | **阶段三未完成** |
| 封装数量 | 153 个（C 71、R 37、J 15、FB 10、U 8、H 5、D 2、TP 2、L 1、X 1、USB 1） | 阶段四已完成 |
| 板框 | 已画，90 × 90 mm（X 95.75–185.75，Y 52.85–142.85） | 阶段五已完成 |
| MAIN_CTRL 布局 | **12 个器件全在 F.Cu，且位于板框外**（X 196–225） | **阶段六未完成** |
| LMK1C1102 散热焊盘 | **符号仍为 8 脚，U2/U3 的焊盘 9 无网络** | **阶段二未完成** |
| 走线 / 过孔 | 0 / 0 | 阶段七未开始 |
| 铺铜 | **一个 zone 都没有** | 阶段八未开始 |

**结论：下一步有三件事，都不是布线。** 按代价从高到低：补上 LMK1C1102 的 EP 引脚（阶段二，改原理图会回流到 PCB）、给网络类分配成员网络（阶段三，不做则 DRC 形同虚设）、把 MAIN_CTRL 的 12 个器件摆进板框（阶段六）。

**网络类"建了但没分配"是个隐蔽陷阱。** 五个类的线宽都填对了，看起来阶段三已完成，但 `netclass_patterns` 里只有一条空规则，意味着全部网络仍归 Default。布线时 VBUS 会按 0.2 mm 放行，DRC 不会有任何提示——因为按 Default 规则它确实合规。

---

## 2. 阶段一　开工前决策

三个决定一旦做出就贯穿全程，改动意味着整板重来。CLOCK 的三个决定及依据：

| 决策 | 选择 | 依据 |
|---|---|---|
| 层数 | 四层 | 312.5 MHz 下贴片电容阵列的 PDN 阻抗 0.082 Ω 对 0.13 Ω 目标仍有 1.6 倍余量；频率不上探则四层够用 |
| 板厂与工艺 | 嘉立创，常规工艺，JLC04161H-7628 | 免费打样每月两款，四层 10 × 10 cm 内 5 片；阻抗按 ±20% 管控 |
| 板框 | 90 × 90 mm | 压在 100 mm 免费线内，且留 10 mm 余量应对布局微调 |
| 主控 | STM32F103CBT6（LQFP48） | 职责只有三项：I2C 配置 LMK5B12204、四路 GPIO（GPIO0/1/2、PDN）、9600 波特率串口。不用 USB，不跑 RTC |
| 主控时钟 | 外接 8 MHz HSE，**不装 32.768 kHz LSE** | 见下 |

**四层是有条件的。** 到 500 MHz 时 PDN 余量只剩刚好，到 1 GHz 必须上六层。若日后输出频率上探，这个决定要重做——所以它排在流程第一位。

**主控的两个晶振决定分别由不同理由支撑，不要一起推翻。**

*不装 32.768 kHz LSE：* LSE 的唯一用途是给内部 RTC 提供走时基准。本板的"时钟"是频率意义上的（OCXO + PLL 分配），STM32 不跑日历 RTC，装了只是白占 PC14/PC15 两个脚和四个元件。

*要装 8 MHz HSE：* 这一条是被串口逼出来的。I2C 是同步总线、GPIO 是静态电平，两者都不在乎时钟精度，单看它们内部 HSI 完全够用。但 UART 是异步的，接收端要在一帧 10 位内守住采样点，工程上单边容差按 ±2 % 卡。F103 的 HSI 出厂只在 25 ℃ 校准到 ±1 %，全温区是 −1.9 % / +4.5 %——高温端直接越界。

**波特率高低不改变这个结论。** 9600 与 115200 的相对误差完全相同，都等于时钟源的相对偏差；低波特率只是让 BRR 的量化误差更小（HSI 8 MHz 下 9600 的量化误差仅 0.04 %），而量化误差本来就不是瓶颈。选 9600 并不能省掉晶振。

**验证：** 五个决定写进版本记录，与 BOM、封装选型一致。

---

## 3. 阶段二　原理图收尾

PCB 是原理图的投影，原理图里的错误会原样长进铜箔里。进入 PCB 前必须清账：

- **ERC 无未处理错误。** 电源网络必须有 PWR_FLAG 或电源输出引脚驱动，否则报"电源未驱动"。
- **每个器件都有确定的封装。** 尤其是从立创导入的 `JLCImport:` 系列（TPS63020DSJR、TYPE-C_16PIN_2MD_073、DOPFITKR2-10M 等），要逐个核对焊盘尺寸与实物规格书。
- **补齐已知缺口。** pcb-layout.md 第 6 节指出两处：VDDDIG 缺 10 µF、VDDXO 缺 100 nF。**在导入 PCB 之前补，不要等布局完再加**——布局完再塞电容，位置只能将就。

- **符号引脚数必须覆盖封装焊盘数。** 见下节，当前工程有两处未闭环。

### 3.1 散热焊盘（EP）必须在符号里有对应引脚

更新 PCB 时若出现这类警告，说明封装的焊盘在符号里找不到落脚点：

```
警告: 找不到元件 U3 的焊盘 9 的网络（引脚 9 不存在于符号中）。
警告: 找不到元件 U2 的焊盘 9 的网络（引脚 9 不存在于符号中）。
```

`U2`、`U3` 是 LMK1C1102，封装 `WSON-8-1EP_2x2mm`——8 个引脚外加中心散热焊盘（焊盘 9）。而符号 `Counter:LMK1C1102` 只定义了 8 脚（CLKIN、1G、Y0、GND、NC、VDD、NC、Y1），于是那块中心大焊盘**分配不到网络，处于浮空状态**。

后果不止是散热：EP 是芯片内部地的一部分，浮空会劣化接地完整性。U2/U3 就在时钟分配链路上，这一项直接影响输出相噪与抖动。而且 DRC 不会报错——它并不知道那个焊盘本该接地。

**修法：** 编辑符号，添加引脚 9，名称 `EP`，**电气类型选「无源」（Passive）**。不要选「电源输入」——语义上虽然说得通，但会让 ERC 要求该脚必须被一个"电源输出"驱动，凭空多出一道检查；更不要选「未连接」，那个类型的含义是"故意不接"，你把它连到 GND 时 ERC 反而报错。

**改完符号有一步极易漏掉：** 原理图里已放置的 U2、U3 用的是旧符号缓存，不会自动长出第 9 脚。必须右键 → 「从库更新符号」，或 `Tools → Update Symbols from Library` 批量更新，然后把 EP 连到 GND。

同类检查要覆盖全部带 EP 的器件：`U1`（LMK5B12204，VQFN-48-1EP，焊盘 49）和 `U7`（TPS63020，SON-14 带 EP）。U7 是开关电源，EP 接地不良会直接变成噪声源。

### 3.2 MAIN_CTRL 的最小外围

主控外围刻意压到最简，但有几项省不掉，且都属于"漏了就上不了电"的类型：

| 项目 | 要求 | 漏掉的后果 |
|---|---|---|
| BOOT0 | 10 kΩ **下拉**到 GND | F103 的 BOOT0 无内部下拉，悬空则上电随机进 System Memory，程序不运行 |
| NRST | 对地 100 nF | 内部有弱上拉，电容用于抗干扰复位 |
| VBAT | 接 3.3 V（不用电池就并到 VDD） | 不能悬空 |
| VDDA | 磁珠/10 Ω + 1 µF 滤波 | 即使不用 ADC，VDDA 也给内部模拟部分和 PLL 供电 |
| 每路 VDD | 各 100 nF，另加整组 10 µF | — |

**一处尚未闭环：晶振负载电容。** `C70`/`C71` 当前是 20 pF，这个值是从模板带来的默认值，必须按晶振实际的 C_L 反算：

```
C70 = C71 = 2 × (C_L − C_stray)，  C_stray 取 3~5 pF
```

`X32258MOB4SI` 的 C_L 要查规格书确认。若 C_L = 20 pF，正确值是 **33 pF 而非 20 pF**（用 20 pF 会让实际振荡频率偏高）；若 C_L = 8 pF 则应取 8 pF。**加 HSE 的全部目的就是要精度，容值配错等于白加这颗晶振**，所以这一步不能跳过。

**验证：** ERC 通过；封装库中无缺失引用；两处去耦缺口已补；带 EP 的器件（U1/U2/U3/U7）焊盘数与符号引脚数一致且 EP 已接地；BOOT0 实测为下拉而非上拉；C70/C71 已按规格书 C_L 复核。

---

## 4. 阶段三　电路板配置（当前工程的缺口）

这是本流程里最被低估的一步。它只改设置、不画一根线，却决定后面所有走线的物理属性。

### 4.1 叠层

@fig:stackup 图 2　四层板 1.6 mm 叠层剖面（JLC04161H-7628）

**本阶段的叠层部分已完成**，工程实测为 F.Cu 0.035 / prepreg 0.2104 / In1.Cu 0.0152 / core 1.065 / In2.Cu 0.0152 / prepreg 0.2104 / B.Cu 0.035，与 JLC04161H-7628 一致。**关键是 L1–L2 间距 0.2104 mm**——这个数字既决定 50 Ω 微带的线宽，也决定回流路径的紧密程度。

四层的用途分配：

| 层 | 用途 | 硬性要求 |
|----|---|---|
| L1 (F.Cu) | 8 路差分输出、XO_P、PRIREF，CLOCK_GEN 全部器件 | 参考 L2，控 50 Ω / 100 Ω |
| L2 (In1.Cu) | **完整 GND** | **绝对不分割** |
| L3 (In2.Cu) | +3.3V 主铜皮、VBUS、七路磁珠分支 | 可分割，但 **MAIN_CTRL 与晶振正下方须保持整片** |
| L4 (B.Cu) | **MAIN_CTRL 全部器件**，及 I2C、GPIO、SWD 等低速信号 | **不走高速信号** |

**L3 保留为电源平面，没有改成第二块地。** 把 MAIN_CTRL 放到 L4 后，它的走线以 L3 为参考，很自然会想到"L3 也铺成 GND 才安全"。但对本板不必：MAIN_CTRL 的信号全是低速（I2C 100 kHz、GPIO 静态电平、SWD 几 MHz），跨电源分割的影响很小；而 L3 一旦让出，3.3 V 就只能靠表层铜皮分配，压降和布线难度都要付代价。

代价换来的约束是：**MAIN_CTRL 器件群与 8 MHz 晶振的垂直投影范围内，L3 必须是连续的一片 +3.3 V，不得有分割缝穿过**。晶振是这块区域里唯一的宽带噪声源，也是唯一对参考面连续性敏感的部分。

**MCU 放 L4 这个安排本身是分区手段，不只是省地方。** 数字主控与 OCXO/LMK 射频链路分居板子两面，中间隔着 L2、L3 两层完整铜箔，隔离效果远好于同层拉开距离。但这个效果**完全依赖内层真的铺满**——当前工程一个 zone 都没有（见第 1 节进度表），在铺铜完成之前，"MCU 放背面"没有任何隔离作用。

### 4.2 网络类

@fig:pcb_netclass 图 3　网络类划分与线宽 / 间距 / 过孔规则

**五个网络类已经建好，但一个成员网络都没分配。** 工程实测的 `netclass_patterns` 里只有一条 `{netclass: Default, pattern: ""}`，四个自定义类（CLK_DIFF 0.2 mm、RF_50 0.36 mm、PWR_3V3 0.5 mm、PWR_5V 1.0 mm）全是空壳。

这比"只有 Default 一个类"更危险，因为板设置界面看上去已经配好了。实际布线时每根线仍按 Default 的 0.2 mm 走，而 DRC **不会有任何提示**——按 Default 规则它确实合规。VBUS 会被画成 0.2 mm 而没人发现。

补法是在 「板设置 → 网络类」 的分配表里为每个类写 pattern（如 `/CLK_*`、`VBUS`、`+3V3`），或逐网络指定。分配完回到网络列表逐条确认归属，不要只看类定义。

电流依据来自 ocxo-5v-buckboost.md 第 4 节：OCXO 冷启动时 VBUS 侧输入电流可达 784 mA，加上 +3.3V 侧 0.65 A，总计约 1.43 A。按 pcb-current-capacity.md 的外层 1 oz 对照表，1.0 mm 在 ΔT = 20 ℃ 下可过 3.23 A，余量充足。

### 4.3 DRC 规则

工程现有的规则（min_track_width 0.2、min_via_diameter 0.5、min_hole_to_hole 0.25、min_copper_edge_clearance 0.5）与嘉立创常规工艺一致，可以保留。需要补充的是**差分对与阻抗线的自定义规则**：对间距 ≥ 0.6 mm（3W 规则）无法用网络类表达，要写成自定义 DRC 规则或在布线时人工守住。

**验证：** 层数 = 4（已达成）；叠层介质厚度与板厂型号一致（已达成）；四个自定义网络类**不仅建齐、且每一类都有成员网络实际归属**（未达成）；DRC 规则跑通无报错。

---

## 5. 阶段四　更新 PCB

从原理图导入封装与连接关系（KiCad 的 「从原理图更新 PCB」）。正常情况下这一步返工代价最低——改了原理图重新导入即可，已有的布局布线会保留。

**注意导入时机：** 阶段三的设置要在导入**之前**完成。如果先导入再改层数，已放置的器件不受影响，但已画的线可能落在被删除的层上。

### 5.1 原理图拆成层次图之后，第一次更新必须改用位号匹配

这是本工程实际踩过的坑，代价是整板布局差点全部作废。

KiCad 靠**完整层次路径**（sheet path + 符号 UUID）把 PCB 的封装和原理图的符号对应起来。工程从单页平坦图拆成层次结构后，CLOCK_GEN 里每个器件的路径前面多出了图纸 UUID：

| | path 形态 |
|--|---|
| PCB 中已有的 141 个封装 | `/6d9c3a1a-…` —— 单段，平坦图时代写入的 |
| 层次化后原理图侧算出的 | `/e8d80103-…/ad7e8003-…/6d9c3a1a-…` |

两者对不上，于是 F8 时 KiCad 判定：141 个封装"在原理图中已不存在"，141 个符号"是新元件"。**结果就是所有器件被堆到原点，已完成的布局全部作废。**

**解法：在「从原理图更新 PCB」对话框里勾选「根据参考位号将封装重新链接到原理图符号」。** 勾上后 KiCad 放弃 path 匹配、改用位号匹配，把已摆好的封装正确认领回去，并把新的层次路径写回 PCB。位置、走线、丝印调整全部保留，只有真正新增的器件出现在板外。

这是一次性操作——路径修好后，以后 F8 恢复正常，不必再勾。

对话框其余选项建议：

| 选项 | 设置 | 理由 |
|---|---|---|
| 根据参考位号将封装重新链接到原理图符号 | **勾** | 核心项 |
| 根据符号分组对封装进行分组 | 不勾 | 会新建分组对象，改变既有布局的组织结构 |
| 用符号指定的封装替换原有封装 | 不勾 | 封装名已逐个比对一致时没必要动，可杜绝封装被静默替换 |
| 删除没有对应符号的封装 | **不勾** | 保守做法，万一 re-link 有遗漏也不会误删已摆好的器件 |
| 忽略锁定设置 | 不勾 | 锁定的连接器不会被移动 |
| 从符号更新封装字段 | 勾 | 同步 Value 等字段 |

**点更新之前，把底部「显示」的「所有」勾上。** 默认只显示错误级别，错误数为 0 时变更列表是空的，你看不到 KiCad 打算做什么。勾上后应当看到的是少量新增条目；**若列出上百条针对既有器件的新增或删除，立即停手**，说明 re-link 没生效。

### 5.2 位号必须先与 PCB 对齐，否则 re-link 会静默错配

re-link 靠位号匹配，这就把位号一致性变成了硬前提。

拆分图纸时如果顺手跑了一次标注、且对话框里选的是「重置现有标注」而不是「保留现有标注」，KiCad 会按器件坐标从头编号。本工程发生过一次：141 个器件 UUID 全部不变，**但其中 129 个位号被重排**（C1→C58、C17→C1、C56→C3 这类看似无规律的洗牌），而 PCB 上仍是旧位号。

此时若直接 re-link，141 个器件会**按位号全部错配**——PCB 上的 C1 被认领成原理图里另一处的 C1，网络和封装全错，而且极难发现。

**处理顺序不能颠倒：先把位号恢复成与 PCB 一致，再 re-link。** 因为 UUID 是不变的，新旧位号之间存在确定的一一映射，恢复是无损的。恢复后应满足两项校验：

- PCB 与原理图按位号比对，封装名 100 % 一致；
- 差集恰好等于本次真正新增的器件。

本工程恢复后实测：141/141 位号一致、141/141 封装名一致，差集正好是 MAIN_CTRL 的 12 个器件（`U8`、`X1`、`C64`~`C71`、`J15`、`R39`），确认无误后才执行的更新。

**验证：** 封装数量与 BOM 一致（当前 153 个）；无未匹配封装警告；既有器件位置未发生位移；EP 类警告已在阶段二清零。

---

## 6. 阶段五　板框与结构

板框已画好：90 × 90 mm 矩形，在 Edge.Cuts 层。还需确认：

- **Edge.Cuts 闭合。** 断口会让板厂无法识别外形。
- **安装孔位置。** 若外壳已定，孔位在这一步定死并锁定。
- **连接器伸出方向。** 11 个 SMA 是 `SMA_Amphenol_132289_EdgeMount` 边缘安装型，本体必须压在板边上，不能内缩——否则电缆装不上。

**SMA 排布的余量核算：** SMA 本体宽 6.35 mm，按 12.7 mm 间距计算，每边 4 个占用 (4−1) × 12.7 + 6.35 = 44.5 mm，90 mm 的边还剩一半空间。

**验证：** Edge.Cuts 闭合且尺寸 = 90 × 90 mm；SMA 焊盘贴齐板边；3D 视图中连接器无干涉。

---

## 7. 阶段六　布局

@fig:clk_layout 图 4　板框内的分区、连接器排布与输出走线方向

（图中标注的 100 × 100 mm 是嘉立创免费打样的上限，本板实际取 90 × 90 mm，四周各留 5 mm 余量。）

布局的第一决定项是 **U1 的引脚方向**，不是美观。LMK5B12204 的四对差分输出分居 QFN 相对两侧（OUT0/1 在 pin 16-21 一侧，OUT2/3 在 pin 41-45 对侧），所以 **U1 居中、8 个输出 SMA 排上下两边**，差分对垂直出线，天然不绕行、不交叉、等长。

摆放顺序：

1. **先锁死连接器。** 11 个 SMA、USB-C、J14 定位后锁定（KiCad 里右键 「锁定」），防止后续误拖。
2. **摆主要器件。** U1 居中，OCXO（U6/H1/TP1）右上，DC-DC（U7/L1）左下，参考缓冲（U2/U3）左上，LDO（U4/U5）右下。
3. **摆去耦电容——在画任何一根线之前。** 七个电源域各自的磁珠与电容跟着本域引脚走，不要把 10 颗磁珠排成一排放角落。100 nF 用 0402 紧贴引脚，10 µF 用 0603 可稍远。
4. **把 MAIN_CTRL 整组翻到 B.Cu。** 见下节。

**DC-DC 与 OCXO 对角布置是刻意的。** 开关噪声主要靠空间辐射和地平面耦合传播，物理距离比任何滤波都有效。+5V_OCXO 走线因此变长，但经 π 型滤波后噪声已低，走线够宽即可。

### 7.1 MAIN_CTRL 分区

**当前状态：12 个器件全在 F.Cu，且位于板框外**（X 196–225，板框右边界 185.75）。它们是阶段四刚导入的，还没摆过。

摆放要求按重要性排：

1. **整组翻到 B.Cu。** `U8`、`X1`、`C64`~`C71`、`R39`、`J15` 全部放背面，与正面的 OCXO/LMK 链路分居两面。这是分区手段（见 4.1 节），不是省空间。
2. **晶振三件抱团，且必须与 MCU 同面。** `X1` 紧贴 `U8` 的 pin5/pin6，OSC_IN/OSC_OUT 走线 < 10 mm，**绝对不打过孔穿层**——过孔的寄生参数直接影响起振裕度和频偏。`C70`/`C71` 的接地端就近汇到同一块地铜再接 U8 的 VSS，走星形接地，不要各自打过孔去大地平面。
3. **远离 U7 和 U6。** `U7`（TPS63020 开关电源）位于 (105.5, 118.2)，`U6`（OCXO）位于 (171.6, 88.0)。MAIN_CTRL 整组要避开这两处的垂直投影。晶振紧挨开关电源是最不该出现的组合。
4. **去耦电容跟着 MCU 一起放背面。** `C64`~`C68` 紧贴各 VDD 脚，不能留在正面。

**这块区域是双向隔离，不是单向防护。** 常见的想法是"怕 MCU 被 OCXO 干扰"，实际反过来才是重点：8 MHz 晶振及其谐波若耦合进低相噪时钟链路，会在 10 MHz 输出上产生固定间隔的杂散。对一块 OCXO 板来说这是实打实的指标损失，比 MCU 偶尔取样出错严重得多。

**验证：** 3D 视图检查干涉；每个电源域的 100 nF 到引脚距离 < 2 mm；DC-DC 与 OCXO 位于对角；比率线（ratsnest）无明显跨板长线；MAIN_CTRL 12 个器件均在 B.Cu 且落在板框内；X1 到 U8 的 pin5/pin6 距离 < 10 mm；OCXO 与 U7 的垂直投影范围内无 MAIN_CTRL 器件。

---

## 8. 阶段七　布线

### 8.1 顺序

@fig:priority 图 5　布线优先级：越敏感、越难改的越先走

优先级的逻辑是**腾挪余地**：阻抗线线宽固定、差分对必须成对等距，它们没有绕行空间；LED 和按键的线多晚布都能绕过去。先布灵活的线，等于把不灵活的线逼进死角。

CLOCK 的具体顺序：

1. 去耦电容到电源/地引脚（环路面积最小）
2. **L4：晶振回路**（X1 ↔ U8 的 OSC_IN/OSC_OUT，C70/C71 星形接地）——与阻抗线同属"没有腾挪余地"的一类，必须早走
3. XO_P（OCXO 到 U1，最短最直）
4. 8 对差分输出（U1 垂直出线到上下 SMA）
5. PRIREF 参考输入
6. DC-DC 的 Cin—U7—L1—Cout 功率环路
7. 其余电源分配
8. L4 上的 I2C、GPIO、SWD

### 8.2 阻抗控制

@fig:microstrip 图 6　微带线截面与阻抗计算参数的对应关系

L1 上所有高速线以 L2 为参考平面，构成标准微带线。按 L1–L2 间距 0.2104 mm、Dk 4.4、1 oz 铜：**50 Ω 单端约 0.36 mm，100 Ω 差分约 0.2 mm 线宽 / 0.2 mm 间距**。

**最常见的错误是计算时 H 填板厚 1.6 mm。** H 是信号层到参考平面的距离，即 0.2104 mm。最终线宽以嘉立创阻抗计算器按实际批次板材复核为准。

### 8.3 三条硬规则

- **差分对全程走 L1**，不换层。换层会打断参考平面的连续性。
- **对与对之间 ≥ 0.6 mm**（3W）。芯片手册的邻道串扰已是 −75 dBc，PCB 串扰直接叠加上去。
- **对内等长。** 上升沿 85 ps 对应有效带宽 4.1 GHz，失配直接转成共模噪声。

### 8.4 MAIN_CTRL 的低速信号

这部分信号本身不难走，难在它要穿过整块敏感的板子。

**I2C 上拉的位置：惯例靠近主机，但本板不必改。** 上拉电阻当前是 `R1`（SCL）和 `R2`（SDA），4.7 kΩ，位于 CLOCK_GEN 图纸内即**从机侧**。靠近主机是通用惯例，理由有三条：上拉接的 VCC 决定总线高电平，放主机侧归属最清晰；从机掉电时总线不会失去上拉；多从机时不会出现"每个从机各带一组、并联后阻值过小"。

但这三条都是可靠性与可维护性层面的。I2C 是开漏加上拉的集总参数电路，板内几厘米的总线长度远小于信号波长，**上拉挂在总线哪一点对上升时间和电平几乎没有区别**。是否要挪，只取决于一个问题：LMK5B12204 的 I2C 电源域与 STM32 的 3.3 V 是否同一路。同一路则保持现状；若 LMK 那路是单独 LDO 且后上电，则在 MCU 已运行而 LMK 未上电的窗口里总线没有上拉，此时应把 R1/R2 挪到 MCU 的 3.3 V 上。

**阻值比位置重要得多，而且方向与直觉相反——要慢，不要快。** 建议保持 4.7 kΩ 或加大到 10 kΩ，并让 I2C 只跑 100 kHz 标准模式：

| 阻值 | 上升时间（C_b 按 50 pF 估） | 100 kHz（≤1000 ns） | 400 kHz（≤300 ns） |
|---|---|-----|-----|
| 4.7 kΩ | 199 ns | 满足 | 满足 |
| 10 kΩ | 424 ns | 满足 | 不满足 |

下限 R_p(min) = (3.3 − 0.4) / 3 mA ≈ 970 Ω，两个值都远在其上。上拉越弱、边沿越缓、高频谐波越少——**这条 I2C 要从背面的 MCU 跨层走到正面的 U1，穿过整块板**，快边沿在这里就是杂散源。而 MCU 配置 LMK 只在上电时做一次，几百 kHz 与一百 kHz 对功能毫无差别，没有任何理由追速度。

**固件侧配套：配置完成后把 I2C 引脚置为高阻，让总线静默，不要做周期性轮询。** 成本为零，对相噪是实打实的好处。

**穿层的三条规则：**

- 每个信号过孔旁**加伴地过孔**，给回流电流就近通路；
- 换层点不落在 `U6`（OCXO）或 `U7`（DC-DC）的正下方；
- **OCXO 的垂直投影区域内，B.Cu 保持纯铺地，不走任何数字线**——它是全板最敏感的器件。

**验证：** 差分对无 L1 以外的走线段；对间距实测 ≥ 0.6 mm；阻抗线宽与网络类设定一致；DC-DC 功率环路目视面积最小；OSC_IN/OSC_OUT 全程在 B.Cu 且无过孔；OCXO 投影范围内 B.Cu 无信号走线。

---

## 9. 阶段八　铺铜与回流

@fig:refplane 图 7　参考平面完整性对回流路径的影响

**当前工程一个 zone 都没有建。** 在此之前，四层叠层只是设置里的数字——内层没有铜，L1/L4 的走线就没有参考平面，"MCU 放背面"的隔离也不存在。这一步不是收尾工作，它是前面所有决策成立的物理前提。

- **L2 铺满 GND，不做任何分割。** 这是全板信号的回流参考，也是四层方案成立的前提。
- **L3 铺 +3.3V，绕开 U1 正下方。** U1 的散热焊盘要 5×5 或 6×6 过孔阵列，这些过孔在 L3 上挖出约 6 × 6 mm 的禁布区。过孔本身接地，穿过 L2 反而加强地平面。
- **L3 在 MAIN_CTRL 与晶振投影下保持整片。** L3 允许分割（它是电源层），但 B.Cu 上的 MCU 走线以它为参考。分割缝若穿过晶振或 MCU 区域，那里的回流路径就要绕行。其余区域的分割不受此限。
- **SMA 焊盘下方挖 antipad。** 中心焊盘对地的寄生电容会把该点阻抗拉低，11 个 SMA 不补偿就是 11 个阻抗不连续点。
- **补地过孔（缝合过孔）。** 沿板边和高速走线两侧补，间距按最高频率波长的 1/20 估算。

**验证：** In1/In2 上确实存在 zone 且已填充（不能停在"设了四层"）；L2 目视无缝无洞；L3 电源路径未从 U1 底下穿过；L3 在 MAIN_CTRL 与 X1 投影范围内连续无缝；SMA 下方 antipad 已挖；铺铜后重新填充并跑 DRC。

---

## 10. 阶段九　检查

三层检查缺一不可，它们发现的是不同类型的错误：

| 检查 | 发现什么 | 怎么做 |
|---|---|---|
| **DRC** | 间距违规、未连接网络、线宽越界 | 必须零错误；警告逐条确认而非批量忽略 |
| **目视** | 丝印被焊盘盖住、极性标记丢失、位号重叠 | 逐层单独显示检查 |
| **3D 视图** | 连接器干涉、元件超出板框、高度冲突 | 重点看 11 个 SMA 与 USB-C |

**DRC 中最容易被误忽略的是"未连接项"。** 铺铜后有些网络看似连上了，实际是被禁布区隔断的孤岛。

**验证：** DRC 零错误；未连接项为 0；3D 视图无干涉。

---

## 11. 阶段十　制造输出

@fig:pcb_output 图 8　制造输出文件与投板前的核对闭环

导出四类文件、打包归入 `hardware/gerber/`，下单前逐条核对图中五项。

**四层板必须在下单页面手动指定叠层型号（JLC04161H-7628）。** 板厂默认叠层的介质厚度与本设计的阻抗计算依据不一致——用默认叠层，0.2104 mm 的假设不成立，50 Ω 就不是 50 Ω。

**阻抗要求写进制造说明。** 免费打样只含 ±20% 管控（50 Ω 最坏做成 60 Ω，回损约 −21 dB，几厘米走线的时钟信号可接受）。验证通过转小批量时再上 ±10% 精密阻抗。

**验证：** ZIP 内含 9 层 Gerber + 钻孔 + 坐标 + BOM；用在线 Gerber 查看器复核一遍层序与板框；五项核对清单逐条打勾。

---

## 12. 出板前总检查清单

☐ 表示当前工程尚未达成的项。

| 阶段 | 项目 | 判据 | 现状 |
|---|---|---|:----:|
| 二 | 去耦缺口 | VDDDIG 补 10 µF、VDDXO 补 100 nF | ☐ |
| 二 | EP 接地 | U1/U2/U3/U7 焊盘数 = 符号引脚数，EP 已连 GND | ☐ |
| 二 | BOOT0 | 10 kΩ **下拉**到 GND（非上拉） | ✓ |
| 二 | 晶振负载电容 | C70/C71 已按规格书 C_L 反算，非模板默认值 | ☐ |
| 三 | 铜层数 | 4（F.Cu / In1.Cu / In2.Cu / B.Cu） | ✓ |
| 三 | 叠层 | JLC04161H-7628，L1–L2 = 0.2104 mm | ✓ |
| 三 | 网络类 | 四类已建齐，**且每一类都有成员网络实际归属** | ☐ |
| 四 | 层次路径 | 拆分图纸后首次更新已用「按位号重新链接」，既有布局未位移 | ✓ |
| 四 | 位号一致 | PCB 与原理图位号、封装名 100 % 对应 | ✓ |
| 五 | 板框 | 90 × 90 mm，Edge.Cuts 闭合 | ✓ |
| 六 | 布局 | DC-DC 与 OCXO 对角；100 nF 贴紧引脚 | — |
| 六 | MAIN_CTRL | 12 个器件均在 B.Cu 且落在板框内 | ☐ |
| 六 | 晶振 | X1 紧贴 U8 pin5/6，距离 < 10 mm | ☐ |
| 七 | 差分对 | 全程 L1，对内等长，对间 ≥ 0.6 mm | — |
| 七 | 电源线宽 | 5 V ≥ 0.5 mm（建议 1 mm），3.3V ≥ 0.5 mm | — |
| 七 | 晶振走线 | OSC_IN/OSC_OUT 全程 B.Cu，无过孔 | — |
| 七 | OCXO 投影 | 其下方 B.Cu 无任何数字走线 | — |
| 八 | 内层铺铜 | In1/In2 上存在 zone 且已填充 | ☐ |
| 八 | L2 完整性 | 无任何分割、开槽 | — |
| 八 | L3 局部完整 | MAIN_CTRL 与 X1 投影下无分割缝 | — |
| 八 | SMA | 焊盘下方已挖 antipad | — |
| 九 | DRC | 零错误，未连接项为 0 | — |
| 十 | 下单 | 已手动指定四层叠层型号 | — |

---

本文的流程阶段与返工代价划分为通用实践，具体参数取自本项目文档：叠层与阻抗见 pcb-layout.md，电流与线宽见 pcb-current-capacity.md，OCXO 供电电流见 ocxo-5v-buckboost.md。

工程现状统计自 2026-09-07 的 `CLOCK.kicad_pcb`、`CLOCK.kicad_pro`、`CLOCK_GEN.kicad_sch` 与 `MAIN_CTRL.kicad_sch`。本次修订相对 2026-09-05 版的主要变化：原理图拆为层次结构并新增 MAIN_CTRL（STM32F103CBT6 主控），器件数由 131 增至 153；阶段三的叠层与网络类定义已完成，缺口转移到网络类成员分配；新增第 3.1 节（EP 焊盘）、3.2 节（主控最小外围）、5.1/5.2 节（层次路径与位号）、7.1 节（MAIN_CTRL 分区）、8.4 节（低速信号与 I2C 上拉）。

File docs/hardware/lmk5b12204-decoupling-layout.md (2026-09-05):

# LMK5B12204 外围元件布局

本文把 U1（LMK5B12204）周围的电容、电阻、磁珠落到具体位置：每一颗器件放在哪一层、离哪个引脚多远、绝对坐标是多少。这是 `pcb-layout.md` 第 6 节的下一层细节——那一节定的是"每域 10 µF + 100 nF、100 nF 紧贴引脚"的原则，本文定的是这句话在 48 个引脚上的具体落位。

---

## 1. 依据

**器件手册。** LMK5B12204 数据手册（ZHCSLM0A）对外围元件只提了五条硬要求，全部集中在 §6 引脚表和 §12.1 布局指南：

| 引脚 | 器件 | 手册原文要求 |
|---|---|---|
| VDD_IN / VDD_XO / VDD_PLL1 / VDD_PLL2 / VDD_DIG | 0.1 µF | "Place a nearby 0.1-µF bypass capacitor on **each pin**" |
| VDDO_0 ~ VDDO_3 | 0.1 µF | 同上，每个引脚一颗 |
| CAP_DIG / CAP_PLL1 / CAP_PLL2 | 10 µF | "Place a nearby **10-µF** bypass capacitor on each pin" |
| LF1 | 470 nF | 对应 APLL1 约 1.0 kHz 环路带宽 |
| LF2 | 100 nF | 对应 APLL2 约 500 kHz 环路带宽 |

§12.1 补充了两条落位规则，本文的整个方案就建立在这两句上：

> Place bypass capacitors close to the VDD and VDDO pins **on the same side as the IC, or directly below the IC pins on the opposite side of the PCB**.

> Place external capacitors close to the CAP_x and LFx pins.

**EVM 实物。** `docs/references/LMK05318B验证板.pdf` 的 LMK05318B 与本板的 LMK5B12204 同为 RGZ 封装、48 脚 VQFN 7 × 7 mm，引脚定义在电源、CAP、LF、XO、参考输入上完全一致（差别只在输出通道数：EVM 是 8 路，本板是 4 路）。所以 EVM 的布局做法可以直接照搬。翻到手册第 16 页 Top Layer Composite View 放大 U1，能看到 TI 自己的做法是三层同心：

```
最内圈：0.1 µF 贴着四边引脚出线，一颗对一个引脚
中间圈：C16/C46 等大容量储能
最外圈：FB3~FB11 磁珠 + R50/R51/R60/R61 串联电阻
```

**本文的方案就是把这个三层同心结构，按本板的实际引脚分配重画一遍。**

---

## 2. 引脚与电源域

@fig:lmk_pinmap 图 1　LMK5B12204 引脚功能分区与电源域归属

七个电源域在原理图上已经拆开，各自一颗 220 Ω 磁珠。但域和引脚的物理分布很不均匀：

| 边 | 需要就近器件的引脚 | 数量 |
|----|---|---|
| 左 | 3 CAP_DIG、4 VDD_DIG、5 VDD_IN | 3 |
| 右 | 27 VDD_PLL1、28 CAP_PLL1、29 LF1、33 VDD_XO、34 LF2、35 CAP_PLL2、36 VDD_PLL2 | 7 |
| 顶 | 37 / 40 VDDO_2、43 / 46 VDDO_3 | 4 |
| 底 | 18 VDDO_0、19 VDDO_1 | 2 |

右边七个引脚全部集中在 4.5 mm 的跨度内，而 0402 电容连焊盘宽 0.62 mm——**一排放不下，必须分圈**。这是右侧要排成三列的原因，不是随意摆的。

---

## 3. 两条约束先于一切

**约束一：顶底两边的正面被差分输出占满。**

看图 1 的引脚顺序就明白：VDDO_0/1（pin 18、19）正夹在 OUT0（16/17）和 OUT1（20/21）中间，VDDO_2/3（pin 43）正夹在 OUT3（44/45）和 OUT2（41/42）中间。八对差分输出必须从这两条边垂直出线到上下两排 SMA——这是 `pcb-layout.md` 第 3 节定下的整板骨架，不能改。

结论：**顶底两边的 6 颗 100 nF 放不进正面，只能走背面正对引脚**。这不是妥协，正是手册 §12.1 明确允许的第二种做法。

**约束二：XO_P 需要一条干净的右出通道。**

XO_P（pin 31）要走到板子右上角的 OCXO（U6），是 50 Ω 单端受控阻抗线，也是全板相位噪声最敏感的一根线。它右出时必须穿过右侧那三列去耦器件。所以右侧的元件排布要给它让出一条 **1.4 mm 宽、全长贯通**的通道——VDD_XO 的 C64 排在通道上沿，LF1 的 C26 排在通道下沿，中间不放任何东西。

---

## 4. 推荐落位

@fig:lmk_decap 图 2　U1 外围电容 / 电阻 / 磁珠的推荐落位（1:1 比例）

**结构是四圈同心：**

| 圈层 | 半径（到芯片中心） | 内容 |
|---|---|---|
| 第一圈 | 4.9 mm | 每个电源引脚的 100 nF，以及 LF1 |
| 第二圈 | 7.1 mm | LF2、CAP_PLL1/2 的 10 µF |
| 第三圈 | 8.9 / 9.8 mm | 各域的 10 µF 储能 |
| 第四圈 | 9.8 / 11.6 mm | 七颗 220 Ω 磁珠 |

半径 4.9 mm 是这样来的：引脚焊盘外沿在半径 3.86 mm，留 0.55 mm 走线，加上 0402 的半个长度 0.76 mm，正好 4.9 mm。**电容焊盘到引脚焊盘的净距离因此是 0.55 mm，回路总长 2.47 mm。**

下面四张表给出绝对坐标。坐标以 U1 中心 (56.3625, 60.9975) 为基准，KiCad 里可以直接输入；如果 U1 之后整体移动，用"相对偏移"一列重新换算即可。

### 4.1 左侧 —— DIG / IN 域，全部正面

| 位号 | 值 / 封装 | 层 | 相对偏移 | 绝对坐标 | 旋转 | 服务对象 |
|---|---|----|---|---|---|---|
| C28 | 100 nF / 0402 | F.Cu | −4.90, −1.25 | 51.462, 59.748 | 0° | pin 4 VDD_DIG |
| C29 | 100 nF / 0402 | F.Cu | −4.90, +0.25 | 51.462, 61.248 | 0° | pin 5 VDD_IN |
| C23 | 10 µF / 0402 | F.Cu | −4.90, −2.75 | 51.462, 58.248 | 0° | pin 3 CAP_DIG |
| R9 | 0 Ω / 0402 | F.Cu | −4.90, +1.75 | 51.462, 62.748 | 0° | pin 9 HW_SW_CTRL 下拉 |
| **C65** | 10 µF / 0603 | F.Cu | −7.10, −1.25 | 49.262, 59.748 | 0° | VDD_DIG 域储能（**新增**） |
| C20 | 10 µF / 0603 | F.Cu | −7.10, +0.25 | 49.262, 61.248 | 0° | VDD_IN 域储能 |
| FB1 | 220 Ω / 0603 | F.Cu | −9.80, −1.25 | 46.562, 59.748 | 0° | VDD_DIG 域 |
| FB3 | 220 Ω / 0603 | F.Cu | −9.80, +0.25 | 46.562, 61.248 | 0° | VDD_IN 域 |

C29 相对 pin 5 下移了 1.0 mm、C23 相对 pin 3 下移了 1.0 mm——因为 pin 3/4/5 的间距只有 0.5 mm，三颗 0402 挤不进同一半径。让出的这 1.0 mm 换来的走线增量不到 0.2 mm，代价可以忽略。

### 4.2 右侧 —— PLL1 / PLL2 / XO 域，全部正面

| 位号 | 值 / 封装 | 层 | 相对偏移 | 绝对坐标 | 旋转 | 服务对象 |
|---|---|----|---|---|---|---|
| C31 | 100 nF / 0402 | F.Cu | +4.90, −2.75 | 61.262, 58.248 | 0° | pin 36 VDD_PLL2 |
| **C64** | 100 nF / 0402 | F.Cu | +4.90, −1.25 | 61.262, 59.748 | 0° | pin 33 VDD_XO（**新增**） |
| C26 | 470 nF / 0402 | F.Cu | +4.90, +0.75 | 61.262, 61.748 | 0° | pin 29 LF1 |
| C30 | 100 nF / 0402 | F.Cu | +4.90, +2.25 | 61.262, 63.248 | 0° | pin 27 VDD_PLL1 |
| C25 | 10 µF / 0402 | F.Cu | +6.70, −2.75 | 63.062, 58.248 | 0° | pin 35 CAP_PLL2 |
| C27 | 100 nF / 0402 | F.Cu | +6.70, −1.25 | 63.062, 59.748 | 0° | pin 34 LF2 |
| C24 | 10 µF / 0402 | F.Cu | +6.70, +1.75 | 63.062, 62.748 | 0° | pin 28 CAP_PLL1 |
| C61 | 10 µF / 0603 | F.Cu | +8.90, −2.75 | 65.263, 58.248 | 0° | VDD_PLL2 域储能 |
| C63 | 10 µF / 0603 | F.Cu | +8.90, −1.25 | 65.263, 59.748 | 0° | VDD_XO 域储能 |
| C60 | 10 µF / 0603 | F.Cu | +8.90, +2.25 | 65.263, 63.248 | 0° | VDD_PLL1 域储能 |
| FB9 | 220 Ω / 0603 | F.Cu | +11.60, −2.75 | 67.962, 58.248 | 0° | VDD_PLL2 域 |
| FB10 | 220 Ω / 0603 | F.Cu | +11.60, −1.25 | 67.962, 59.748 | 0° | VDD_XO 域 |
| FB7 | 220 Ω / 0603 | F.Cu | +11.60, +2.25 | 67.962, 63.248 | 0° | VDD_PLL1 域 |

**内圈只放 VDD 的 100 nF，LF/CAP 让到第二圈。** 理由是这三类节点对回路电感的敏感度不同：VDD 去耦要供瞬态电流，回路电感直接进 PDN 阻抗；LFx 是环路滤波的高阻节点，怕的是噪声耦合而不是几百 pH 的电感；CAP_x 是内部 LDO 的输出稳定电容，同理。所以在半径资源紧张时，**先保 VDD**。

**C64 是新增件。** VDD_XO 目前只有一颗 10 µF（C63），没有高频去耦。XO 供电上的噪声会被直接调制到 48 MHz 参考上，再乘以 APLL 的倍频比放大——这是七个域里最不能省 100 nF 的一个。

**XO_P 通道**：C64 的下沿在 −0.94 mm，C26 的上沿在 +0.44 mm，中间 1.38 mm 空档留给 XO_P。布线时这条带上不允许再放任何器件或过孔。

### 4.3 顶边 —— VDDO_2 / VDDO_3

| 位号 | 值 / 封装 | 层 | 相对偏移 | 绝对坐标 | 旋转 | 服务对象 |
|---|---|----|---|---|---|---|
| C36 | 100 nF / 0402 | **B.Cu** | −1.75, −4.98 | 54.612, 56.017 | 90° | pin 46 VDDO_3 |
| C37 | 100 nF / 0402 | **B.Cu** | −0.25, −4.98 | 56.112, 56.017 | 90° | pin 43 VDDO_3 |
| C35 | 100 nF / 0402 | **B.Cu** | +1.25, −4.98 | 57.612, 56.017 | 90° | pin 40 VDDO_2 |
| C34 | 100 nF / 0402 | **B.Cu** | +2.75, −4.98 | 59.112, 56.017 | 90° | pin 37 VDDO_2 |
| C22 | 10 µF / 0603 | F.Cu | +0.50, −7.60 | 56.862, 53.398 | 90° | VDDO_2/3 域储能 |
| FB5 | 220 Ω / 0603 | F.Cu | +0.50, −9.90 | 56.862, 51.098 | 90° | VDDO_2/3 域 |

### 4.4 底边 —— VDDO_0 / VDDO_1

| 位号 | 值 / 封装 | 层 | 相对偏移 | 绝对坐标 | 旋转 | 服务对象 |
|---|---|----|---|---|---|---|
| C33 | 100 nF / 0402 | **B.Cu** | −0.25, +4.98 | 56.112, 65.978 | 90° | pin 18 VDDO_0 |
| C32 | 100 nF / 0402 | **B.Cu** | +0.25, +6.60 | 56.612, 67.597 | 90° | pin 19 VDDO_1 |
| C21 | 10 µF / 0603 | F.Cu | 0.00, +8.80 | 56.362, 69.797 | 90° | VDDO_0/1 域储能 |
| FB4 | 220 Ω / 0603 | F.Cu | 0.00, +11.10 | 56.362, 72.097 | 90° | VDDO_0/1 域 |

pin 18 和 19 只隔 0.5 mm，两颗 0402 竖排会撞在一起，所以 C32 沿 y 再退 1.62 mm，两颗前后错开。

---

## 5. 单点扇出的尺寸

@fig:lmk_fanout 图 3　两种扇出方式的尺寸细节

放对位置只完成了一半。**电容的价值全部取决于它到引脚、以及它到地平面这两段回路的电感**，而这两段都在毫米级——所以每一段都要按尺寸画，不能随手连。

**正面就近（左右两侧）：** 引脚焊盘外沿 →（0.55 mm，线宽 ≥ 0.3 mm）→ 电容 → （0.40 mm）→ GND 过孔。全程 2.47 mm。GND 侧焊盘的两端各打一个 0.6/0.3 过孔比只打一个更好，能把地回路电感再压掉近一半。

**背面正对（顶底两边）：** 引脚 →（0.35 mm）→ 0.6/0.3 电源过孔 → 穿板到 B.Cu → 电容 → GND 过孔直落 L2。过孔本身约 1.2 nH，和正面 2.9 mm 走线在同一量级，所以这两种方式在电气上是等价的——手册也正是这么说的。

两条必须遵守的细节：

- **电源过孔穿过 L2 完整地平面时，必须开 antipad**；它穿过 L3 时，顺便把该域在 L3 上的铜皮接了进来，这是好事，不要刻意避开。
- 每颗电容的 GND 侧焊盘外 0.4 mm 内必须有地过孔。**没有这个过孔，前面所有的距离控制都白做**——回路电感会全部转移到地回路上。

---

## 6. 与当前 PCB 的差距

@fig:lmk_gap 图 4　当前 PCB 实测的去耦距离

上图的数值是从 `CLOCK.kicad_pcb` 里逐个焊盘算出来的**同网络焊盘间最短距离**，不是元件中心距。可以分成三档：

**已经到位（8 个节点，1.86 ~ 2.14 mm）。** CAP_DIG、CAP_PLL1、CAP_PLL2、LF1、LF2 五个模拟节点，以及 VDDO_2/3 的三颗 100 nF，都已经贴在引脚旁。这批不用动，只需按第 4 节的坐标做 0.1 ~ 0.3 mm 的对齐微调。

**差一个数量级（7 个节点，4.65 ~ 21.10 mm）。** C37、C31、C33、C32、C30、C28、C29 目前散落在离芯片 5 ~ 21 mm 的地方，其中 C29（VDD_IN 的 100 nF）距离 21.10 mm，是目标值的十倍。看它们的坐标就知道原因——C17 ~ C22 排在 x = 57.097 一列、C60 ~ C63 排在 x = 51.958 一列，**y 方向严格等间距 1.97 mm，这是 KiCad 导入网表后未摆放元件的默认队列**，还没有被布局过。

**器件缺失（2 个）。** VDD_XO 没有 100 nF，VDD_DIG 没有 10 µF。需要在原理图里补 C64、C65 两颗，重新导入网表。

此外还有一项与 `pcb-layout.md` 第 6 节不符：**当前全部 10 µF 用的都是 0402 封装**（C20 ~ C25、C60、C61、C63）。第 6 节要求 10 µF 用 0603，理由是 0402 的 10 µF / 6.3 V 在 3.3 V 直流偏置下实际容量只剩两三 µF。本文的处理是分开对待：

| 器件 | 封装 | 理由 |
|---|---|---|
| C23、C24、C25（CAP_DIG / CAP_PLL1 / CAP_PLL2） | 保持 0402 | 接的是内部 LDO 输出，偏置电压低，偏置效应轻；且内圈空间只够 0402 |
| C20、C21、C22、C60、C61、C63、C65 | 改 0603 | 直接挂在 3.3 V 上，必须扛住偏置效应；它们在外圈，空间足够 |

---

## 7. 一个前提：先把叠层改成四层

`CLOCK.kicad_pcb` 目前的层定义里只有 `F.Cu` 和 `B.Cu` 两层铜。而本文的方案有两处直接依赖四层结构：

- 顶底两边的 6 颗 100 nF 放在背面，其 GND 过孔需要**直落 L2 完整地平面**才有意义。两层板上背面是唯一的地平面，同时还要走信号，回流路径无法保证。
- 电源过孔穿板时"在 L3 接入本域铜皮"这一条，两层板上不存在。

`pcb-layout.md` 第 2 节已经定好了四层叠层（L1 信号 / L2 GND / L3 电源 / L4 低速），**执行本文方案前先在 KiCad 的板设置里把层数改到 4 层并指定叠层型号**，否则第 4.3、4.4 两张表没法落地。

---

## 8. 执行顺序

1. **改叠层** → 验证：Board Setup 里显示 F.Cu / In1.Cu / In2.Cu / B.Cu 四层，厚度 1.6 mm
2. **原理图补 C64（100 nF，VDD_XO）、C65（10 µF，VDD_DIG）** → 验证：ERC 无新增错误，两颗电容分别落在 VDDXO 与 VDDDIG 网络上
3. **把 C20 / C21 / C22 / C60 / C61 / C63 / C65 的封装改成 0603** → 验证：更新 PCB 后这七颗的 footprint 为 `C_0603_1608Metric`
4. **按 4.1 / 4.2 两张表摆左右两侧的 19 颗器件** → 验证：重新跑距离脚本，左右两侧所有 100 nF 的焊盘间距 ≤ 2.0 mm
5. **把 C32 ~ C37 六颗翻到 B.Cu，按 4.3 / 4.4 摆位** → 验证：这六颗的 layer 属性为 B.Cu，且 x/y 与对应引脚对齐
6. **补扇出：每颗电容的 GND 焊盘外 0.4 mm 打地过孔，电源侧按图 3 的尺寸连线** → 验证：DRC 无未连接，目视每颗电容两端各有一条短连接
7. **最后画 XO_P** → 验证：从 pin 31 到 U6 全程在右侧 1.4 mm 通道内，没有被去耦器件挤到绕行

---

## 9. 检查清单

| 项目 | 判据 |
|---|---|
| 每个 VDD / VDDO 引脚 | 都有一颗独立的 100 nF，无共用 |
| 100 nF 焊盘到引脚焊盘 | ≤ 2.0 mm |
| CAP_DIG / CAP_PLL1 / CAP_PLL2 | 各一颗 10 µF，≤ 2.5 mm |
| LF1 / LF2 | 470 nF / 100 nF，≤ 2.5 mm |
| 每颗去耦电容的 GND 侧 | 0.4 mm 内有地过孔 |
| 背面六颗电容 | 正对引脚，电源过孔穿 L2 处已开 antipad |
| XO_P 通道 | 右侧 1.4 mm 宽通道全长无器件、无过孔 |
| 七颗磁珠 | 各自跟着本域引脚走，不排成一排放角落 |
| E-PAD | 5 × 5 过孔阵列，连通各层地平面 |
| 10 µF 封装 | 外圈七颗为 0603，内圈三颗为 0402 |

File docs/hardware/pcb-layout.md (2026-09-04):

# PCB 布局设计

本文给出 CLOCK 板的层数选择、叠层、分区布局与关键布线规则。目标是在 100 × 100 mm 板框内用四层板完成设计，同时满足 312.5 MHz 差分输出的信号完整性要求。

---

## 1. 三条设计约束

**板框 ≤ 100 × 100 mm。** 嘉立创的免费打样条件是长宽 10 × 10 cm 以内、5 片、单片出货、常规工艺，每月两款额度。超出这个尺寸就要按套餐计费（四层 10 cm 内 10 片 300 元），超出 10 cm 更要单独计价。把板框压在 100 mm 以内，等于功能验证阶段可以零成本试错两次——这个约束值得为之挤一挤布局。

**四层板。** 输出频率 312.5 MHz 时，十几颗 0402 的 100 nF 并联后在该频率提供约 0.082 Ω 阻抗，对着 0.13 Ω 的 PDN 目标还有 1.6 倍余量，贴片电容阵列仍然管用，不需要六层那种紧耦合平面电容来兜底。到 500 MHz 这个余量就只剩刚好，到 1 GHz 则必须上六层。**所以四层的前提是频率不往上走。**

**常规工艺。** 免费打样不含精密阻抗（±10%），只有免费的 ±20% 管控。50 Ω 最坏做成 60 Ω，回损约 −21 dB，对时钟信号、几厘米走线的场合够用。验证通过、要转小批量时再上精密阻抗。

---

## 2. 叠层

@fig:stackup 图 1　四层板 1.6 mm 叠层剖面

| 层 | 用途 | 硬性要求 |
|----|---|---|
| L1 (F.Cu) | 8 路差分输出、XO_P、PRIREF、全部器件 | 参考 L2，控 50 Ω / 100 Ω |
| L2 (In1.Cu) | **完整 GND** | **绝对不分割**——全板信号的回流参考 |
| L3 (In2.Cu) | +3.3V 主铜皮、VBUS、七路磁珠分支 | 可自由分割，L1 不参考它 |
| L4 (B.Cu) | I2C、GPIO、STATUS 等低速信号 | **不走高速信号** |

关键在 **L1–L2 间距只有 0.2104 mm**（Prepreg 7628，Dk 4.4），这个薄间距既让 50 Ω 微带的线宽落在好加工的 0.36 mm 左右，也让回流路径紧贴信号线。而 L2–L3 之间隔着 1.065 mm 的 Core，平面电容只有约 168 pF——这正是四层板在 GHz 频段力不从心的原因，也是 312.5 MHz 下不成问题的原因。

**L4 为什么不能走高速：** 它参考的是 L3 电源层，而 L3 上有七路磁珠分支的分割。任何跨越分割缝的走线，回流路径都会被打断。

---

## 3. 整板布局

@fig:clk_layout 图 2　100 × 100 mm 板框内的分区与连接器排布

布局的第一决定项不是美观，而是 **U1 的引脚方向**。LMK5B12204 是 48 引脚 QFN，四对差分输出天然分成两组、位于芯片的相对两侧：

```
OUT0_P/N = pin 17/16 ┐ 同一条边
OUT1_P/N = pin 20/21 ┘
OUT2_P/N = pin 42/41 ┐ 对面那条边
OUT3_P/N = pin 45/44 ┘
```

**所以 U1 放板子正中，八个输出 SMA 排在上下两边，正对芯片的两组输出引脚。** 差分对垂直出线，不绕行、不交叉、天然等长。如果把 SMA 分散到四条边，就必然有差分对要绕过芯片走到侧面——绕行、交叉、长度失配全来了，而上升沿只有 85 ps（有效带宽 4.1 GHz），每多绕一段都在增加风险。

其余四个区块的位置各有理由：

| 区块 | 位置 | 理由 |
|---|---|---|
| U2 / U3 参考缓冲 | 左上 | 紧邻左边的 J1、J6 参考输入 SMA，PRIREF 到 U1 距离短 |
| OCXO（U6、H1、TP1） | 右上 | 紧邻右边 J12 校准口，XO_P 到 U1 走线短 |
| **DC-DC（U7、L1）** | **左下** | **与 OCXO 呈对角，物理距离最大化** |
| LDO（U4、U5） | 右下 | 靠近 USB-C 输入，散热铜箔有角落空间 |

DC-DC 与 OCXO 对角布置是刻意的。开关电源的噪声主要通过空间辐射和地平面耦合传播，物理距离比任何滤波都有效。至于 +5V_OCXO 供电走线变长——那条线经过 π 型滤波后噪声已经很低，只要走线够宽（≥0.5 mm，建议 1 mm），长一点无妨。

**SMA 排布的余量。** SMA 本体宽 6.35 mm，按 12.7 mm 间距（留足扳手与电缆弯曲空间）计算，n 个 SMA 占用边长为 (n−1) × 12.7 + 6.35 mm。每边 4 个只需 44.5 mm，100 mm 的边还剩一半空间。十一个 SMA（8 输出 + 2 参考 + 1 校准）分散在四条边完全排得开。

---

## 4. 阻抗控制

@fig:microstrip 图 3　微带线截面与阻抗计算参数的对应关系

L1 上的所有高速线以 L2 为参考平面，构成标准微带线。按 L1–L2 间距 0.2104 mm、Dk 4.4、1 oz 铜计算：

- **50 Ω 单端**：线宽约 0.36 mm
- **100 Ω 差分**：线宽约 0.2 mm、间距约 0.2 mm

**计算时 H 填 0.2104 mm，不是板厚 1.6 mm**——这是最常见的错误。最终线宽以嘉立创的阻抗计算器（"阻抗神器"）为准，不同批次的板材参数会有微调。

四对差分线之间守 **3W 规则**：对与对之间的间距不小于三倍线宽，即 ≥0.6 mm。芯片手册给的邻道串扰杂散已经是 −75 dBc，PCB 上的串扰会直接叠加上去。

---

## 5. 参考平面与回流

@fig:refplane 图 4　参考平面完整性对回流路径的影响

L2 是全板唯一的完整地平面，**任何分割、开槽、大面积挖空都会破坏回流路径**。具体到这块板：

- U1 的散热焊盘需要 5×5 或 6×6 过孔阵列。这些过孔穿过 L2 但本身就是接地的，不但无害，反而加强了地平面连接。
- 但它们会在 **L3 电源层**上挖出约 6 × 6 mm 的禁布区。**+3.3V 的分配路径要绕开 U1 正下方**，不要指望从芯片底下穿过去。
- SMA 焊盘下方必须挖 **antipad**（去掉该处的地平面）。中心焊盘对地的寄生电容会把该点阻抗拉低，不补偿的话十一个 SMA 就是十一个阻抗不连续点。

---

## 6. 去耦电容布局

这是四层板方案能成立的支柱——PDN 在 312.5 MHz 的 0.082 Ω 全靠贴片电容阵列，而这个数字是**理想并联值**，电容离引脚远一点，回路电感上去就不成立了。

**七个电源域各自独立。** 原理图已经拆成 VDDDIG、VDDIN、VDDPLL1、VDDPLL2、VDDXO、VDDO0_1、VDDO2_3，每域一颗磁珠。布局时**每域的磁珠和电容要跟着该域的引脚走**，不要把七颗磁珠排成一排放在角落。

**每域配 10 µF + 100 nF：**

| 电容 | 封装 | 位置 |
|---|---|---|
| 100 nF | **0402** | 紧贴电源引脚，越近越好——它决定高频 PDN |
| 10 µF | **0603** | 可以稍远，它管低频储能 |

封装选择的逻辑是相反的：100 nF 用 0402 是为了压低 ESL；10 µF 用 0603 是为了抵抗直流偏置效应（0402 的 10 µF/6.3 V 在 3.3 V 偏压下实际只剩两三 µF）。

**两处缺口需要在布局前补上：** VDDDIG 目前只有一颗 100 nF，**缺 10 µF**；VDDXO 只有一颗 10 µF，**缺 100 nF**。其余五个域都已配齐。

---

## 7. DC-DC 区的特殊要求

开关电源的性能一半取决于布局，这一块的规则优先于任何美观考虑：

- **Cin—U7—L1—Cout 构成的高 di/dt 环路，包围面积压到最小。** 这个环路里流动的是陡峭的开关电流，面积就是天线面积，直接决定辐射和纹波。
- **输入电容紧贴 VIN 与 PGND 引脚**，C54（100 nF）要比 C53（10 µF）更靠近芯片。
- **电感必须是屏蔽型。** 非屏蔽电感的漏磁会耦合进 OCXO、时钟走线和反馈网络。
- **FB 分压网络远离电感。** FB 是整个环路里阻抗最高、最敏感的节点，开关磁场耦合进去会直接影响输出稳定性。
- **C58（VINA 去耦）紧贴 VINA 引脚**，C57（π 滤波末级）紧贴 OCXO 供电引脚——这两颗电容放远了，对应的滤波就形同虚设。
- U4、U5 的散热焊盘要留足铜箔。按 674 mA 负载算，U4 耗散约 1.15 W，而手册给的 θJA = 54.2 ℃/W 是 JEDEC 标准板（9 in²）的值，**实际铜箔面积直接决定这个数字能不能成立**。

---

## 8. 布线顺序建议

1. **先定板框和连接器。** 十一个 SMA、USB-C、J14 的位置一旦确定，整板骨架就定了。确认板框在 100 × 100 mm 以内。
2. **摆主要器件。** U1 居中，OCXO 右上，DC-DC 左下，缓冲左上，LDO 右下。
3. **摆去耦电容。** 在画任何一根线之前完成——它们的位置比走线更重要，而且一旦走线画完就很难再塞进去。
4. **画八对差分输出。** 从 U1 垂直出线到上下两边 SMA，控阻抗、守 3W、对内等长。
5. **画 XO_P 与 PRIREF。** 同样控阻抗，XO_P 尤其要短。
6. **铺 L2 完整地平面**，确认没有任何分割。
7. **画 L3 电源分配**，绕开 U1 散热过孔区。
8. **L4 收尾**，走 I2C、GPIO、STATUS 等低速信号。

---

## 9. 检查清单

| 项目 | 判据 |
|---|---|
| 板框尺寸 | ≤ 100 × 100 mm |
| L2 完整性 | 无任何分割、开槽 |
| 差分对 | 对内等长，对间距 ≥ 0.6 mm，全程走 L1 |
| SMA 焊盘 | 下方已挖 antipad |
| 去耦电容 | 每域 10 µF + 100 nF，100 nF 紧贴引脚 |
| VDDDIG / VDDXO | 已补齐缺失的 10 µF / 100 nF |
| DC-DC 环路 | Cin—U7—L1—Cout 面积最小 |
| 电感 | 屏蔽型，饱和电流 ≥ 3 A |
| U4/U5 散热 | 散热焊盘铜箔面积充足 |
| 5 V 走线 | 宽度 ≥ 0.5 mm（建议 1 mm） |
| L4 | 未走任何高速信号 |

---

本文的叠层参数取自嘉立创 JLC04161H-7628，阻抗数值需用其在线计算器按实际批次板材复核；PDN 与串扰的计算依据 LMK5B12204 数据手册（SNAS810C）的电流与串扰规格。

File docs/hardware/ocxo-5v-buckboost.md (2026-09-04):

# OCXO 5V 升降压供电设计

给 U6（OCXO-10M）提供一路稳定的 5.0 V，输入是 USB-C 的 VBUS。本文给出完整电路、元件选型、电流核算与布局要求。

---

## 1. 为什么必须是升降压

VBUS 的实际电压不是 5.0 V，而是随负载电流在 **4.25 ～ 5.25 V** 之间浮动——线缆与接头的往返电阻典型 100～500 mΩ，OCXO 冷启动那一安培电流会把它拉下去几百毫伏。这个范围**跨在 5 V 两侧**，所以纯降压或纯升压拓扑都无法覆盖，只能用升降压。

更要紧的是，对 OCXO 而言"供电稳定"首先指的不是噪声低，而是**负载变化时输出电压不动**。OCXO 手册里有一项 frequency change vs. supply voltage，典型 ±0.01～0.1 ppm per 5% 供电变化：

| 供电方式 | 负载 0.3→1.3 A 时的电压变化 | 折算频率变化 |
|---|---|---|
| VBUS 直供（线缆 200 mΩ） | 约 200 mV（4%） | 0.008 ～ 0.08 ppm |
| Buck-boost 稳压 | 约 25 mV（0.5%） | 0.001 ～ 0.01 ppm |

OCXO 的初始精度不过 ±0.1 ppm、温度稳定性约 ±0.005 ppm。VBUS 直供那 0.08 ppm 会把 OCXO 本身的指标整个淹掉，而且它不是可以用 VCTRL 校掉的固定偏差——它跟着加热器占空比、线缆、适配器一起变，预热过程中频率会一路漂，换根线又是另一个值。

还有一层：OCXO 的加热器是 PWM 控制的，稳态下电流在 1～100 Hz 量级持续脉动。这个频率太低，电容滤不掉，只能靠电源本身的低输出阻抗和快速负载响应扛住。

---

## 2. 电路

@fig:ocxo_buckboost 图 1　VBUS 经 buck-boost 稳压到 5.0 V 后送 OCXO

| 位号 | 值 / 型号 | 封装 | 关键要求 |
|---|---|---|---|
| U7 | TPS63020DSJR | VSON-14 (DSJ) 3×4 mm | 输入 1.8～5.5 V，输出最大 3 A |
| L1 | 2.2 µH | — | **屏蔽型**，饱和电流 ≥3 A，DCR 越低越好 |
| C53 | 10 µF，X5R/X7R，16 V | **0603** | 输入储能，紧贴 U7 的 VIN 脚 |
| C54 | 100 nF，X7R，25 V | **0402** | 输入高频旁路，比 C53 更靠近引脚 |
| **R38** | **10 Ω，±1%** | 0402 | **VINA 隔离电阻，见 3.1 节** |
| **C58** | **1 µF，X7R，16 V** | 0603 | **VINA 去耦，紧贴 VINA 引脚** |
| C55 | 22 µF，X5R/X7R，**16 V 以上** | 0805 | 输出储能，耐压见 3.5 节 |
| C57 | 10 µF，X5R/X7R，16 V | 0603 | π 型滤波末级，**紧贴 OCXO 供电引脚** |
| FB8 | 600 Ω @100 MHz | 0603 | 额定电流 ≥2 A，**DCR ≤30 mΩ**，见 3.6 节 |
| R36 / R37 | 909 kΩ / 100 kΩ，±1% | 0402 | 反馈分压，阻值见 3.3 节 |
| R39 | 10 kΩ（可选） | 0402 | PG 上拉至 3.3 V，见 3.7 节 |

封装栏按直流偏置效应选定：**10 µF 及以上用 0603/0805 并抬高耐压**（0402 的 10 µF/6.3 V 在 3.3 V 偏压下实际只剩两三 µF），**100 nF 用 0402 压低 ESL**。两者的选型逻辑是相反的。

已对照 TPS6302x 数据手册（SLVS916I）核实：VFB 基准 **0.5 V**，输入范围 **1.8～5.5 V**（覆盖 VBUS 全程），输出电流最高 **3 A**，峰值效率 96%，DSJ 封装为 14 引脚 VSON（3 mm × 4 mm，带外露散热焊盘），推荐电感 **1～4.7 µH**（本文取 2.2 µH，在范围内）。

完整引脚定义：**VINA 1、GND 2、FB 3、VOUT 4/5、L2 6/7、L1 8/9、VIN 10/11、EN 12、PS/SYNC 13、PG 14**，外露散热焊盘接 PGND（KiCad 符号中编号 15）。VIN、VOUT、L1、L2 各有两个引脚，PCB 上必须全部连接。符号已按此定义画入 `Counter:TPS63020DSJR`。

---

## 3. 七个关键设计点

### 3.1 VINA 必须与 VIN 隔离

TPS63020 有两路供电引脚：**VIN（10、11）给功率级，VINA（1）给控制级**。手册对 VINA 的描述是 "Supply voltage for control stage"，它们在芯片内部是分开的。

这两路**不能直接并在一起**。功率级 VIN 上流动的是几百 kHz 到 MHz 的开关电流，在走线电感上产生的尖峰可达几百 mV；控制级里跑的是误差放大器和基准，这些尖峰一旦窜进去，会直接调制输出电压——最终变成 OCXO 供电上的抖动，再变成频率抖动。绕了一圈，正好毁掉这个电路存在的意义。

标准接法是一个 RC 低通：

```
VIN ──[R38 10 Ω]──┬── VINA (pin 1)
                  │
                C58 1 µF
                  │
                 GND
```

截止频率约 16 kHz，把开关噪声挡在控制级之外。**C58 必须紧贴 VINA 引脚**——放远了这个 RC 就形同虚设。R38 取 10 Ω 是因为 VINA 的静态电流很小（几十 µA 量级），压降可忽略；不要取得太大，否则上电时控制级建立会延迟。

### 3.2 PS/SYNC 必须接高电平

这是本设计里最容易被忽略、后果又最严重的一点。buck-boost 芯片在轻载时通常会自动进入省电模式（PFM），**开关频率随负载在几 kHz 到几百 kHz 之间漂移**。这种低频、不规则的开关噪声正好落在相位噪声最敏感的近端偏置频率上，会直接抬高 OCXO 输出的近端相噪。

把 PS/SYNC 接到 VIN 强制器件全程工作在固定频率 PWM 模式。代价是轻载效率下降几个百分点，对这个应用完全不重要。

### 3.3 反馈分压与远端检测的取舍

输出电压由分压比设定：

```
VOUT = VFB × (1 + R36 / R37)
```

VFB 手册值为 **0.5 V**，故 R36/R37 = 9。这里有个容易踩的坑：**手册要求低边电阻 R37 落在 100 kΩ ～ 1 MΩ 区间**，不能随手取小值——TPS63020 的 FB 输入是高阻节点，分压网络取太小会额外耗电并干扰内部补偿。取 R37 = 100 kΩ、R36 = 909 kΩ（E96 最接近 900 kΩ 的值），得 VOUT = 0.5 × (1 + 9.09) = **5.05 V**，比 5.00 V 高 0.9%，落在 OCXO 常见的 ±5% 供电容差内，无需强求精确 5.000 V。分压支路电流约 5 µA。

图 1 中反馈取样点在**磁珠之前**，这是保守做法：环路里不包含 π 型滤波，稳定性最好。代价是磁珠 DCR 造成的压降不被补偿（见 3.6 节）。若实测发现该压降影响过大，可以把 R36 上端改接到 C57 处做远端检测，让环路补偿掉它——但这样滤波器被包进反馈环，必须重新评估环路稳定性和相位裕度，不是无脑改。

### 3.4 电感必须用屏蔽型

非屏蔽电感的漏磁会耦合进旁边的 OCXO、晶振走线和反馈网络。这块板上有 10 MHz 参考和 LMK5B12204，屏蔽型不是可选项。饱和电流要按峰值算，不是平均值——升压模式下峰值电流明显高于输出电流（见第 4 节）。

### 3.5 输出电容的耐压不能只看容值

X7R/X5R 陶瓷电容有显著的直流偏置效应：一颗 22 µF/6.3 V 的电容工作在 5 V 时，实际容量可能只剩标称的 40～50%。开关电源的输出纹波和环路稳定性都依赖实际容量，容量掉一半可能导致纹波超标甚至环路振荡。

**C55 选 16 V 或 25 V 耐压的 22 µF**，同样封装下实际容量会高得多。这是成本极低但极易被忽略的一条。

### 3.6 磁珠的 DCR 会抵消一部分稳压效果

这条和我们的设计目标直接冲突，值得单独说。FB8 串在输出路径上，它的直流电阻会随负载产生压降：

| 磁珠 DCR | 负载 0.3→1.3 A 时压降变化 | 相对 5 V | 折算频率变化 |
|---|---|---|---|
| 50 mΩ | 50 mV | 1.0% | 0.002 ～ 0.02 ppm |
| 30 mΩ | 30 mV | 0.6% | 0.001 ～ 0.012 ppm |
| 20 mΩ | 20 mV | 0.4% | 0.0008 ～ 0.008 ppm |

也就是说，一颗 DCR 50 mΩ 的磁珠单独引入的负载调整误差（1.0%），比 buck-boost 本身的负载调整率（0.5%）还大——滤波器成了稳压精度的瓶颈。**选磁珠时必须同时看阻抗和 DCR，DCR 控制在 30 mΩ 以内**，或者按 3.3 节改用远端检测。

### 3.7 PG 可以用来保护 OCXO（可选）

PG（引脚 14）是开漏的 Power Good 输出：输出电压建立后释放（高），异常时拉低。悬空也能正常工作，但接一只 10 kΩ 上拉到 3.3 V 就能拿到一个"5 V 已就绪"的硬件信号。

对这块板它有个具体用途：**用它去控制 OCXO 加热器的使能**。前面算过，USB 供电在冷启动阶段很可能不够，一旦电压塌陷就会出现"欠压→复位→重新加热→再欠压"的循环，现场表现是随机重启，根因却在充电器上，很难查。有了 PG，可以在电源没稳的情况下干脆不启动加热，把这类故障挡在门外。

如果不用这个功能，PG 直接悬空即可，不需要下拉。

---

## 4. 电流预算：升压会放大输入电流

这一点常被忽略。升压工作时输入电流大于输出电流，关系是：

```
I_in = (V_out × I_out) / (V_in × η)
```

取最坏输入 V_in = 4.25 V、效率 η = 0.90：

| OCXO 输出电流 | VBUS 侧输入电流 | 加上 +3.3V 侧 0.65 A 后总计 |
|---|---|---|
| 300 mA（稳态） | 392 mA | 1.04 A |
| 600 mA（小型冷启动） | 784 mA | 1.43 A |
| 1.0 A | 1.31 A | 1.96 A |

对照 USB 供电能力：**电脑 USB 口（500/900 mA）在冷启动阶段撑不住，必须用能宣告 1.5 A 以上的 Type-C 适配器，且要用 C-to-C 线**（用 A-to-C 线接 USB-A 充电器时，D+/D− 悬空只能拿到 500 mA）。

相比 VBUS 直供，本方案在冷启动时多消耗约 180 mA（效率损失加升压比），这是换取稳定 5.0 V 的代价，值得付。

---

## 5. 布局

@fig:ocxo_bb_layout 图 2　DC-DC 区与 OCXO 区的布局关系

开关电源的性能一半取决于布局，具体要求：

- **Cin—U7—L1—Cout 构成的高 di/dt 环路，包围面积压到最小。** 这个环路里流动的是陡峭的开关电流，面积就是天线面积，直接决定辐射和纹波。它优先于任何美观考虑。
- **输入电容紧贴 VIN 与 PGND 引脚**，C54（100 nF）要比 C53（10 µF）更靠近芯片。
- **DC-DC 区与 OCXO 区之间保持完整地平面**，中间不走时钟或模拟信号。
- **反馈分压网络远离电感**，避免开关磁场耦合进 FB 节点——FB 是整个环路里最高阻抗、最敏感的节点。
- **C57 紧贴 OCXO 的供电引脚**，让 π 型滤波的末级位于负载端而不是源端。
- 5 V 走线按 1.5 A 设计，外层 1 oz 铜下宽度不小于 0.5 mm，建议直接给到 1 mm。

---

## 6. 可选优化：把开关频率同步到参考时钟

TPS63020 的开关频率典型 2.4 MHz，其第 4 次谐波 9.6 MHz 距离 10 MHz 只有 400 kHz，会在输出相位噪声上留下一根 400 kHz 偏置的杂散。对多数应用无所谓，如果你在意远端杂散，有个办法：

PS/SYNC 引脚除了接高强制 PWM，还能接受**外部同步时钟**。用 10 MHz 四分频得到的 2.5 MHz 去同步开关频率，开关噪声的谐波就正好落在载波上，不再产生差拍杂散。代价是要多一个分频器（可以从 LMK5B12204 的某一路输出取），复杂度上升。

这属于锦上添花，先把基础电路做对再考虑。

---

## 7. 与现有电路的接口

- 本电路的输入直接接 J11 的 VBUS 网络，接在现有 C46/C47 之后即可。
- 输出的 5.0 V 是 OCXO **专用**的一路，不要与 +3.3V 数字部分共用。OCXO 加热器的断续大电流会在共用轨上产生波动，反过来数字噪声也会窜进 OCXO。
- 板上已有的 H1 三脚排针（+5V / VCC / +3.3V 三选一）可以保留：把它的 +5V 端从 VBUS 改接到本电路的 5.0 V 输出，这样排针依然能在"稳压 5 V"与"3.3 V"之间切换，适配不同电压的 OCXO。
- 原 VBUS 上的 C46（100 nF）与 C47（10 µF）保持不变，它们是 USB 端口的去耦，与本电路的 C53/C54 各司其职。

---

## 8. 待确认清单

| 项目 | 影响 |
|---|---|
| OCXO 的稳态与冷启动电流 | 决定 U7 的电流规格与 USB 供电是否够用 |
| OCXO 的供电电压容差与频率-电压系数 | 决定稳压精度要求，本文按 ±5%、±0.01～0.1 ppm/5% 估算 |
| 所选磁珠的 DCR | 见 3.5 节，超过 30 mΩ 需改用远端检测 |
| 实际使用的 USB 电源与线缆 | 决定 VBUS 最低电压，进而决定升压裕量 |

已核实项：TPS63020 的 VFB 基准 0.5 V、R37 推荐范围 100 kΩ～1 MΩ、VOUT 公式、输入范围 1.8～5.5 V、最大输出 3 A、推荐电感 1～4.7 µH、PS/SYNC 接高进入固定频率同步模式（接低或悬空为轻载省电模式），均取自 TPS6302x 数据手册。OCXO 相关参数仍待选型后确认。

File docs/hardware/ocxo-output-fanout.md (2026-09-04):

# OCXO 输出分路设计

需求是把 U6（OCXO-10M）的 10 MHz 输出分成两路：一路送 U1（LMK5B12204）的 XO 输入，另一路引到 SMA 座供出厂校准时接频率计。本文分析该不该用有源缓冲、LMK1C1102 是否胜任，并给出推荐电路。

---

## 结论摘要

**一、不建议用对称的一分二缓冲器。** 两路的要求截然不同：送 LMK5B12204 那一路是整个系统的频率基准，相位噪声一点都不能劣化；送频率计那一路只是测个频率，相噪好坏完全无所谓。用一个对称的缓冲器同时服务两者，等于让不重要的那一路拖累重要的那一路。

**二、推荐高阻取样。** 主路径保持直通不动，校准口通过一只串联电阻旁路取出。**板上现有的 R34（0 Ω，一端接 XO_P、另一端悬空）正好就在这个位置**，把它改成 1 kΩ，再补一只耦合电容和一个 SMA 座即可。

**三、LMK1C1102 能工作，但不推荐放在 XO 主路径上。** 手册只给出宽带附加抖动 19.2 fs，通篇没有任何偏置频率下的近端相位噪声数据——**你无法从手册上证明它不会劣化 OCXO 的近端相噪**，而这恰恰是买 OCXO 所付的钱。它用在板上现有的 PRIREF 路径是合适的。

---

## 1. 现状

从原理图读出的当前连接：

- U6 的 pin1（RF）经 XO_P 网络**直连** U1 的 XO_P 输入，中间没有任何元件——没有耦合电容，没有端接，没有匹配。
- XO_N 网络在 OCXO 一侧直接接地，因此是**单端驱动差分输入**。
- XO_P 网络上挂着 **R34（0 Ω）**，其另一端悬空，未连接任何网络。
- U1 的 XO 输入端同样没有任何外围元件。

R34 这个悬空端会让 ERC 报未连接警告。不过它的位置恰好是本文方案需要的取样点，可以直接利用。

---

## 2. 为什么不该在主路径上放有源器件

这一节是全文的核心理由，值得单独说清楚。

OCXO 相对普通晶振的全部价值，在于优异的**近端相位噪声**和短期稳定度——也就是 1 Hz 到 100 Hz 偏置频率范围内的表现。而 LMK5B12204 作为网络同步时钟发生器，用 OCXO 做保持（holdover）参考时，其 DPLL 的环路带宽通常配置得很窄（几赫兹到几十赫兹量级）。**环路带宽以内的参考相位噪声是原样传递到输出的，不会被滤除。** 换句话说，OCXO 的近端相噪就是系统输出的近端相噪。

在这条路径上插入任何有源器件，该器件的**附加相位噪声**（additive phase noise）就会叠加进来。而通用数字缓冲器的近端表现由其 1/f 闪烁噪声主导，典型值在 10 Hz 偏置处约 −120 至 −135 dBc/Hz（10 MHz 载波）；一颗像样的 OCXO 在同一偏置处是 −130 至 −145 dBc/Hz。两者量级相当甚至缓冲器更差，叠加之后系统性能由缓冲器决定，OCXO 的钱就白花了。

反过来看校准口：频率计只是在闸门时间内数过零次数，相位噪声劣化 20 dB 都不影响读数的有效数字。**两路要求相差如此之大，就不该用对称结构去服务。**

---

## 3. 推荐方案：高阻取样

@fig:xo_tap 图 1　主路径直通、校准口经 R34 旁路取样

主路径从 OCXO 到 LMK5B12204 完全保持现状，不增加任何串联元件，因此相噪劣化为零。校准支路从 XO_P 上以一只 1 kΩ 电阻旁路引出，经耦合电容送到 SMA。

| 位号 | 值 | 说明 |
|---|-----|---|
| R34 | 1 kΩ，0402/0603，±1% | 板上已有此位，当前值为 0 Ω，改值即可 |
| C52 | 100 nF，C0G/NP0 | 隔直，避免频率计输入的直流通路影响 OCXO |
| J12 | SMA 座 | 校准口，与板上其它 Conn_Coaxial 同型号 |

**取样电阻的选值。** 频率计输入阻抗为 50 Ω，与 R34 构成分压。阻值越大对主路径影响越小，但校准口电平也越低：

| R34 | 分压衰减 | 对主路径的插损 | OCXO 输出 +7 dBm 时校准口电平 |
|-----|---|---|---|
| 1 kΩ | −26.4 dB | −0.40 dB | −19.4 dBm |
| 470 Ω | −20.3 dB | −0.80 dB | −13.3 dBm |
| 220 Ω | −14.6 dB | −1.47 dB | −7.6 dBm |

通用频率计的输入灵敏度大多在 −25 dBm 或 20 mV rms 上下，1 kΩ 给出的 −19.4 dBm（约 24 mV rms）够用但余量不大。**如果你的 OCXO 输出功率低于 +7 dBm，或频率计灵敏度较差，就往下选 470 Ω**——多付 0.4 dB 的主路径插损，换来 6 dB 的校准口电平，这笔交易通常是划算的。三个档位对主路径的影响都在 1.5 dB 以内，而且是纯电阻性衰减，不引入任何噪声。

**不接频率计时会怎样。** SMA 空载时，从主路径看过去是 1 kΩ 串联一个开路，等效开路，对主路径的影响严格为零。这是高阻取样相对功分器的一个额外好处：**平时不接线，主路径就完全不受打扰**，不需要为空置端口配 50 Ω 端接帽。

---

## 4. 三种方案的对比

@fig:xo_split_cmp 图 2　三种分路做法的拓扑与代价

| | 方案 A 高阻取样 | 方案 B 6 dB 电阻功分 | 方案 C 有源缓冲 |
|---|---|---|---|
| 主路径相噪劣化 | 无 | 无 | 取决于芯片 1/f 噪声 |
| 主路径插损 | −0.4 dB | −6 dB | 无，可有增益 |
| 端口隔离 | 约 26 dB | 6 dB | 通常 >40 dB |
| 阻抗匹配 | 校准口不匹配 | 三端口均匹配 | 好 |
| 新增元件 | 1 电容 + 1 SMA | 3 电阻 + 1 SMA | 芯片 + 供电去耦 |
| 空置端口影响 | 无 | 需装端接帽 | 无 |

**方案 B（6 dB 电阻功分）** 用三只 16.9 Ω 电阻构成星形功分器，三个端口都匹配 50 Ω，两路对称。它的优点是校准口阻抗匹配良好，缺点是主路径白白损失 6 dB，而且空置端口开路会破坏匹配、影响主路径电平，必须常态装 50 Ω 端接帽。对于"偶尔接一次频率计"的场景，为此付出 6 dB 并不值得。

**方案 C（有源缓冲）** 的真正价值在隔离度和驱动能力。如果将来要从这颗 OCXO 分出三路以上，或者需要驱动长电缆、或者担心下游负载变化牵引 OCXO，那才轮到它出场。当前只有两路且其中一路是临时接入，用不上这些优势。

至于校准口不匹配 50 Ω 会不会有问题：10 MHz 在 FR4 中的波长约 15 米，只要电缆不长于一两米，传输线效应可以忽略；而且频率计只判过零，轻微的反射不影响计数。

---

## 5. LMK1C1102 能不能用

**能工作，但不推荐用在 XO 主路径上。**

先说它在板上现有的用法是合理的：U2、U3 两颗 LMK1C1102 缓冲的是 SIG_1、SIG_2 到 PRIREF_P、PRIREF_N 的路径，也就是 GNSS 参考输入。这条路径的参考本身相噪就差（GNSS 秒脉冲的短稳远不如 OCXO），且 DPLL 对它的环路带宽极窄，缓冲器的附加噪声完全淹没在参考自身的噪声里。**用在那里没问题，用在 XO 路径是另一回事。**

**手册核对结果。** LMK1C1102 的抖动指标是**附加 RMS 抖动 19.2 fs（典型值，VDD = 1.8 V）**，输出偏斜 25 ps。19.2 fs 这个数字本身相当漂亮，但它是**宽带积分抖动**——而手册通篇没有给出任何偏置频率下的附加相位噪声曲线。

这恰恰印证了判断的第二种情形：**厂商给宽带 RMS 抖动而不给近端相噪，说明该器件没有针对近端优化，也不打算对这一项做保证。** 通用扇出缓冲器绝大多数如此。宽带抖动主要由高偏置频率段的白噪声决定，它低不代表 1 Hz～100 Hz 的 1/f 噪声也低，而后者才是 OCXO 路径上真正要命的。

所以结论是：**用它不会立刻出问题，但你无法从数据手册上证明它不会劣化 OCXO 的近端相噪**——对系统频率基准这条路径，"无法证明"就等于不能用。相比之下，高阻取样方案连这个问题都不需要问。

**还有一个信号形式的问题。** 见第 6.4 节：LMK5B12204 的 XO 输入本身就要求 0.2 V/ns 以上的压摆率，10 MHz 正弦波达不到。如果 OCXO 确实是正弦输出，那么无论走缓冲器还是直连，都需要先整形——这时缓冲器反倒成了整形手段之一，但要额外处理输入偏置，电路比想象的复杂。

**如果最终确实需要有源缓冲**，选型时应盯住这几点：附加相位噪声的 floor 与 1/f 拐点（而不是宽带 RMS 抖动）、输入端是否接受正弦驱动、电源抑制比（缓冲器的电源噪声会直接调制成相噪，供电必须单独 LDO 加 π 型滤波）。对 10 MHz 这种低频，低噪声运放缓冲或分立射极跟随器往往比通用时钟扇出芯片表现更好。

---

## 6. 顺带核对的五项

前三项与分路方案独立但在同一段电路上，后两项关系到 OCXO 选型，建议一并处理。

**6.1 R34 的悬空端。** 当前 R34 一端接 XO_P、另一端未连接任何网络，ERC 会报未连接引脚警告。按本文方案接上 C52 与 J12 后，该问题自然消除；若暂不实施，应给悬空端加 `no connect` 标记，避免 ERC 噪声掩盖真正的错误。

**6.2 XO 输入端没有外围元件——这是对的。** 查过手册后可以确认：LMK5B12204 的 XO 输入（pin 31/32）带**可编程的片上端接和片上交流耦合电容**，通过 TICS Pro 配置即可，同时支持交流耦合和直流耦合两种驱动。手册原文明确写着差分和 LVCMOS 输入都可以直流耦合到接收端。所以当前"直连、无外围元件"的画法是合法的，不需要补耦合电容——只要在配置里把输入缓冲器模式设成与实际驱动方式匹配。

有一个细节要注意：手册建议低于 2 kHz 的输入应禁用片上交流耦合电容以改善噪声抑制。10 MHz 远高于此，用默认配置即可。

**6.3 XO_N 直接接地——这也是对的。** 手册原文："单端 LVCMOS 时钟可以加到 P 输入，N 输入下拉到地"。所以当前接法正是手册推荐的单端驱动方式，**我上一版担心的"应该通过电容交流接地"是多余的**，不用改。

**6.4 但有两条输入规格必须核对，其中一条可能影响 OCXO 选型。** 手册第 6.6 节给出的 XO 输入特性：

| 参数 | 规格 |
|---|---|
| 输入频率范围 fIN | 10 ~ 100 MHz |
| 单端输入摆幅 VIN-SE | 0.4 ~ 2.6 Vpp |
| 差分输入摆幅 VIN-DIFF | 0.4 ~ 2 Vpp |
| **输入压摆率 dV/dt** | **0.2 ~ 0.5 V/ns** |
| 输入占空比 | 40 ~ 60 % |

两点：

其一，**10 MHz 正好压在输入频率范围的下限**，可用，但没有余量。

其二更要紧：**压摆率下限 0.2 V/ns 与摆幅上限 2.6 Vpp 在 10 MHz 正弦波下是矛盾的。** 一个 2.6 Vpp 的 10 MHz 正弦波，过零点压摆率只有 2π × 10 MHz × 1.3 V ≈ **0.082 V/ns**，不到要求的一半；要达到 0.2 V/ns 需要 6.4 Vpp 的幅度，那又远远超出 2.6 Vpp 的上限。**换句话说，10 MHz 的正弦波无论幅度取多少都无法同时满足这两条规格。**

这意味着：**这颗 OCXO 应当选 HCMOS/LVCMOS 方波输出型号，而不是正弦（RF）输出型号。** 方波的过零压摆率轻松达到 V/ns 量级。当前原理图上 U6 的 pin1 名为 RF，暗示可能是正弦输出——这一项请务必对着实际型号的手册确认，如果确实是正弦输出，要么换型号，要么在 XO 输入前加一级整形。

**6.5 若 OCXO 是 3.3 V 方波输出，需要分压。** 单端输入摆幅上限是 2.6 Vpp，而 3.3 V LVCMOS 摆幅是 3.3 Vpp，超了。手册图 8-8 给出了标准接法：串联 R1 = 125 Ω、对地 R2 = 375 Ω，分压比 0.75，把 3.3 V 降到约 2.5 V；2.5 V 和 1.8 V 驱动则 R1 = 0、R2 不装。若是 5 V 输出的 OCXO，分压比要更大，而且**绝对最大额定值是 VDD + 0.3 V（约 3.6 V），5 V 直接接会损坏芯片**，分压网络不是可选项。

---

## 7. 待确认清单

| 项目 | 影响 |
|---|---|
| **OCXO 的输出波形（正弦还是 HCMOS）与幅度** | 最关键。决定能否直接驱动 XO 输入（见 6.4）、是否需要分压（见 6.5）、以及 R34 取值 |
| OCXO 输出是否带直流偏置 | 决定 XO 输入缓冲器配置成交流还是直流耦合模式 |
| LMK5B12204 用 OCXO 做保持时的 DPLL 环路带宽 | 决定近端相噪的传递程度；手册标称可编程范围 1 mHz ~ 4 kHz |
| 出厂校准所用频率计的输入灵敏度 | 决定 R34 选 1 kΩ 还是 470 Ω |

已核实项（本次更新）：LMK5B12204 的 XO 输入耦合方式、内部端接与偏置、单端驱动接法、输入摆幅与压摆率规格，均取自数据手册 SNAS810C（2026 年 5 月修订版）第 5 节与第 6.6 节；LMK1C1102 的附加抖动取自其产品页规格。本文电平计算仍以 OCXO 输出 +7 dBm 为示例，实际值需按选定型号重算。

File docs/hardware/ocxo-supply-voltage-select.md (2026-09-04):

# OCXO 供电电压切换设计

本文给出 U6（OCXO-10M）供电电压在 +3.3 V 与 +5 V 之间可选配的设计方案，目标是同一块 PCB 既能装 3.3 V 的 OCXO，也能装 5 V 的 OCXO，装配时通过配置电阻选定。

---

## 1. 需求与现状

**需求：** 不同厂家、不同型号的 10 MHz OCXO 供电电压不统一，5 V 是传统主流，近年小型化型号多为 3.3 V。希望 PCB 不改版就能适配两者。

**现状：** 当前原理图中 U6 的 pin5（VCC）固定连接 +3.3V 网络，C48、C49、C50 三个去耦电容挂在该网络上；同一张图纸右侧另有一个 +5V 电源符号，处于悬空未连接状态。也就是说板上两条电压轨都已存在，只是 OCXO 被硬连到了其中一条。

**既有做法：** 本板已经在使用 0 Ω 电阻与 Open 位作为配置跳线，例如 R9、R11、R13、R18、R21、R28、R29 装 0 Ω，R3、R6、R22、R23 留空。本文方案沿用这一既有风格，不引入新的器件类型。

---

## 2. 电源架构与约束

@fig:ocxo_ptree 图 1　两种供电方案在电源树上的位置

板上电源来自 USB-C（J11），CC1、CC2 通过 R30、R31 两只 5.1 kΩ 下拉电阻配置为标准 UFP（受电端）。+5V 即 USB VBUS，+3.3V 由两颗 TPS78633（U4、U5，SOT-223-6 封装）从 5 V 线性降压产生，同时供给 LMK5B12204（U1）与两颗 LMK1C1102（U2、U3）。

这个架构带来两条硬约束，它们比"选哪个元件切换"重要得多：

**约束一：USB 供电电流有限。** 板上只有 5.1 kΩ 的 Rd 下拉，没有检测对端 Rp 电平的电路，也没有 PD 协商芯片。这意味着板子能宣告自己是受电端，但无法得知电源实际允许多大电流。接 USB 2.0 主机时上限 500 mA，接 USB 3.x 主机时 900 mA；接支持 Type-C 电流宣告的电源适配器时对方可能允许 1.5 A 或 3 A，但板子只能"盲取"。**设计上必须按最坏情况 500 mA 核算。**

**约束二：3.3 V 路径要经过线性稳压器。** TPS78633 是线性 LDO，输入 5 V、输出 3.3 V，压差 1.7 V 全部转化为热量。OCXO 走 3.3 V 时，它的电流会叠加到 LDO 上，功耗按 1.7 V × I 增加。而 OCXO 恰恰是全板电流最大的器件。

---

## 3. 切换方式选型

| 方式 | 接触电阻 | 载流 | 可现场切换 | 误接双通风险 | 评价 |
|---|---|---|---|---|---|
| 双 0 Ω 电阻二选一 | 最低（<50 mΩ） | 0805 约 2 A | 否，需焊接 | 有，靠工艺防呆 | **推荐** |
| 三脚排针 + 跳线帽 | 10～30 mΩ | 约 3 A | 是 | 无，物理互斥 | 需频繁切换时用 |
| PCB 焊盘锡桥 | 不确定 | 低 | 否 | 有 | 不推荐，大电流下不可靠 |
| DIP 拨码开关 | 50～200 mΩ | 通常 <500 mA | 是 | 视型号 | 不推荐，载流与可靠性均不足 |
| 负载开关 / 理想二极管 OR | 视器件 | 高 | 是（可软控） | 无 | 过度设计，且引入压降与噪声 |

**推荐双 0 Ω 电阻方案**，理由有三：一是本板已有同类做法，工艺文件和装配习惯一致；二是无机械接触，长期可靠性最高，且接触电阻最小——OCXO 电流大，任何毫欧级的额外阻抗都会变成压降和发热；三是成本为零。

代价是切换需要动烙铁。但这是**装配期的选型配置**，不是运行期功能：一块板配一颗 OCXO，型号定了就不会再变。如果你的实际用法是同一块板要反复插拔不同 OCXO 做对比测试，那就改用三脚排针加跳线帽，牺牲一点接触电阻换取免焊切换，并接受跳线帽可能松动的风险。

---

## 4. 推荐电路

@fig:ocxo_vsel 图 2　双 0 Ω 电阻二选一供电切换

新增与改动的元件如下。原有的 C48、C49、C50 保持不变，只是它们所挂的网络从 +3.3V 改名为 VDD_OCXO。

| 位号 | 值 | 封装 | 说明 |
|---|-----|---|---|
| R34 | 0 Ω | 0805，额定 ≥2 A | 接 +5V，装则为 5 V 方案 |
| R35 | 0 Ω | 0805，额定 ≥2 A | 接 +3.3V，装则为 3.3 V 方案 |
| TP1 | 测试点 | 1 mm 焊盘 | 测量 VDD_OCXO 实际电压 |

**为什么用 0805 而不是 0402。** 0805 的 0 Ω 电阻额定电流通常为 2 A，0603 约 1 A，0402 约 1 A。OCXO 冷启动电流可达 1 A 以上（见第 6 节），0805 留出的余量最合适。虽然 0 Ω 电阻标称阻值为零，实际存在 20～50 mΩ 的体电阻，1 A 下压降 20～50 mV，对 3.3 V 供电是 1% 量级，可以接受，但没有必要用更小封装去恶化它。

**网络改名。** 建议把 U6 pin5 所在网络从 +3.3V 改为独立的 VDD_OCXO 网络标签。这样 ERC 能正确识别它不再是全局电源网络，也避免后续有人误以为 OCXO 与其它 3.3 V 器件共网。C48、C49、C50 仍然紧贴 U6 放置。

**测试点。** 加一个 TP1 直接测 VDD_OCXO，是为了在装配后能一眼确认装对了电阻，也便于测量 OCXO 冷启动时该点的电压跌落。

---

## 5. 防呆：绝不能两个都装

R34 与 R35 同时装配会把 +5V 与 +3.3V 直接短接。后果是 5 V 通过 R35 倒灌进 3.3 V 轨：TPS78633 的输出被反向抬高到 5 V，LDO 内部寄生二极管可能承受反向电流而损坏；更严重的是 U1、U2、U3 等全部 3.3 V 器件会被加上 5 V，绝对最大额定值通常在 3.6～4 V，会立即永久损坏。这是本设计唯一的致命失误模式，必须用三重措施防住：

1. **原理图属性：** 在 KiCad 中给未选用的那颗电阻设置 `Do not populate` 属性（DNP），并在 Value 栏写明。BOM 与贴片文件会自动带上该状态。
2. **PCB 丝印：** 在 R34、R35 旁边印一行明确文字，例如 `R34=5V / R35=3.3V  装其一`。丝印是产线唯一会看的现场文档。
3. **上电前检查：** 装配后、首次上电前，用万用表二极管档测量 +5V 与 +3.3V 两网络之间是否导通。若导通则说明两颗都装了，此时通电即损坏。

如果你判断产线执行力不可靠，那就直接改用三脚排针加跳线帽——它在物理上无法同时接通两路，把风险从"靠流程"变成"靠结构"。这是排针方案唯一压倒 0 Ω 方案的地方。

---

## 6. 电流与热耗散核算

**OCXO 的电流特性。** 恒温晶振与普通晶振的根本区别在于内部有加热器和恒温槽。冷启动时加热器全功率工作把晶体加热到约 75 ℃，此阶段电流是稳态的三到五倍，**持续时间是分钟量级**，不是毫秒级尖峰。典型量级如下（以实际型号手册为准）：

| 类型 | 稳态功耗 | 冷启动功耗 | 5 V 稳态 / 冷启动 | 3.3 V 稳态 / 冷启动 |
|---|---|---|---|---|
| 小型（5×7 ～ 9×14 mm） | 0.5～1.5 W | 2～3 W | 100～300 mA / 400～600 mA | 150～450 mA / 600～900 mA |
| 标准 DIP-14 | 1.5～2.5 W | 5～8 W | 300～500 mA / 1～1.6 A | — |

**由此得到第一个重要结论：储能电容对冷启动毫无帮助。** 常见的错误反应是在 VBUS 上加大电容来"扛过启动尖峰"。加热持续数分钟，任何现实容量的电容在这个时间尺度上都等于不存在。缓解冷启动电流只有两条路：选低功耗型号，或者提高供电能力。

**方案 A（5 V）的电流预算。** OCXO 电流直接从 VBUS 取，不经过 LDO。以小型 5 V OCXO 冷启动 500 mA 计，加上 3.3 V 侧的固有负载——按手册规格核算，LMK5B12204 约 620 mA、两颗 LMK1C1102 合计数十 mA，共约 650 mA，经线性 LDO 后输入侧电流与输出侧相同——**总计约 1.15 A，远超 USB 2.0 的 500 mA 上限**。必须使用能宣告 1.5 A 以上的 Type-C 电源适配器，不要接电脑 USB 口冷启动。

**方案 B（3.3 V）的 LDO 热耗散。** 这是方案 B 的硬伤。OCXO 电流叠加到 TPS78633 上，额外功耗为 1.7 V × I：

| OCXO 电流 @3.3 V | LDO 额外功耗 | SOT-223-6 温升（θJA = 54.2 ℃/W） |
|---|---|---|
| 200 mA（低功耗稳态） | 0.34 W | 约 18 ℃，可接受 |
| 450 mA（稳态上限） | 0.77 W | 约 41 ℃，接近上限 |
| 900 mA（冷启动） | 1.53 W | 约 83 ℃，**会触发热关断** |

**而且这还没算 LDO 本来就要供的负载。** 按 LMK5B12204 手册的电流规格逐项相加：核心部分 VDD_DIG 21 mA、VDD_IN 43 mA、VDD_PLL1 110 mA、VDD_XO 20 mA、VDD_PLL2 120 mA（APLL2 使能时），合计 314 mA；输出部分每通道 65～70 mA（输出 mux 与分频器）外加 11 mA（AC-LVDS 驱动器），四对输出约 312 mA。**单是 U1 就要 620 mA 左右**，加上两颗 LMK1C1102，3.3 V 轨的固有负载已接近 650 mA，本身就让 LDO 耗散 1.1 W、温升 60 ℃。

在这个基础上再叠加 OCXO 的电流，方案 B 在冷启动期间必然过热保护，表现为 3.3 V 轨反复跌落、整板反复复位、OCXO 永远无法完成预热。

**因此方案 B 只适用于低功耗小型 3.3 V OCXO**，且建议给 OCXO 单独配一颗 LDO，而不是共用 U4、U5。这已超出本文"切换"的范围，但如果 3.3 V 是主用方案，应当在下一版布板时考虑。

本节数据已核对 TPS786 数据手册（SLVS389M）：TPS78633 连续输出电流 **1.5 A**，SOT-223（DCQ，6 引脚）的 **RθJA = 54.2 ℃/W**，1.5 A 时压差典型 340 mV、最大 510 mV，负载调整率 7 mV（0～1.5 A），输出限流 2.4～4.2 A。θJA 是 JEDEC 标准板（9 in²）下的值，实际取决于铺铜面积——手册明确指出 SOT-223 的主要散热路径是通过接地散热片到 PCB，因此那片铜箔的面积直接决定上表温升是否成立。

---

## 7. 换电压时必须连带修改的四处

只改一颗 0 Ω 电阻是不够的。OCXO 供电电压变化会牵动周边电路，以下四处必须同步检查：

**7.1 VREF 与 VCTRL 分压电路。** 参见《OCXO 压控端电位器接法》一文，R32 电位器由 U6 的 VREF 引脚供电。3.3 V OCXO 的 VREF 电压与 5 V 型号不同（可能是 2.5 V，也可能根本没有 VREF 引脚）。若目标型号无 VREF，需要把 R32 的上端改接到 VDD_OCXO，并重新核算分压范围；同时 VCTRL 的合法输入范围也会随之改变。

**7.2 输出电平与 LMK5B12204 的输入兼容性。** 这是四项中最危险的一项，而且手册数据出来后可以把话说死了。

LMK5B12204 的绝对最大额定值写明：时钟与逻辑输入的电压范围是 **−0.3 V 到 VDD + 0.3 V**，VDD 最大 3.6 V。推荐工作条件里输入电压范围是 0 ～ 3.465 V。而 XO 单端输入摆幅规格是 **0.4 ～ 2.6 Vpp**。

三条结论：

- **切到 5 V 之后，如果 OCXO 是 HCMOS 方波输出，0～5 V 的摆幅会直接超过绝对最大额定值，U1 会损坏。** 这不是"可能有风险"，是超规格。
- 即使是 3.3 V 输出的 OCXO，3.3 Vpp 也超过了 2.6 Vpp 的输入摆幅上限。手册图 8-8 给出了标准解法：串联 R1 = 125 Ω、对地 R2 = 375 Ω 分压到约 2.5 V（2.5 V 与 1.8 V 驱动则 R1 = 0、R2 不装）。**换句话说，3.3 V 方波输出的 OCXO 也需要这个分压网络，当前电路里没有。**
- 若 OCXO 是正弦输出且幅度在 2.6 Vpp 以内，摆幅这一关能过，但会撞上另一堵墙：XO 输入要求压摆率 ≥ 0.2 V/ns，而 10 MHz 正弦在 2.6 Vpp 下只有 0.082 V/ns，不达标。详见《OCXO 输出分路设计》第 6.4 节。

综合起来：**这颗 OCXO 应当选 3.3 V 或更低电压的方波输出型号，并按手册加分压网络。** 5 V 型号即便解决了供电，也要在信号路径上额外做电平转换，得不偿失——这一条其实反过来影响了本文的方案选择。

**7.3 去耦电容的耐压与直流偏置降额。** C48 标称 10 µF，若其额定耐压为 6.3 V，在 5 V 工作点下 X5R/X7R 陶瓷电容的直流偏置效应会使实际容量下降到标称值的一半甚至更少。切到 5 V 方案时建议把 C48 换成额定 16 V 或 25 V 的型号，容量标称值不变而实际有效容量更高。

**7.4 封装与引脚定义。** 不同电压的 OCXO 未必共用同一 footprint，即使外形相同，引脚定义也可能不同——OCXO 的引脚排列没有统一标准，VCTRL、VREF、GND 的位置各厂家不一。选定两个候选型号后，必须逐一比对引脚定义表，确认它们真的 pin-to-pin 兼容，否则"切换供电电压"这件事本身就不成立。

---

## 8. 布局、丝印与测试

**布局：**

- R34、R35 并排放置，靠近 U6，走线尽量短粗。按 1 A 电流、外层 1 oz 铜、20 ℃ 温升计算，走线宽度不小于 0.5 mm；建议直接给到 1 mm 以降低压降。
- C48、C49、C50 保持紧贴 U6 的 VCC 引脚，顺序为最小容值最靠近引脚。
- 若采用方案 A，建议在 R34 与 VDD_OCXO 之间预留一个磁珠位（例如 FB8）与一个 10 µF 电容位，构成 π 型滤波，抑制 USB VBUS 上的开关噪声。板上已有 7 只磁珠，型号可沿用。VBUS 噪声会通过 VCC 调制 OCXO 的相位噪声，这一项对时钟板不能省。
- TP1 放在方便探针接触的位置，旁边标注网络名。

**丝印：** `R34=5V / R35=3.3V  装其一`，字高不小于 0.8 mm。

**上电测试顺序：**

1. 装配后目视确认 R34、R35 只装了一颗。
2. 万用表测 +5V 与 +3.3V 之间不导通。
3. 接 Type-C 适配器（非电脑 USB 口）上电，立即用 TP1 测 VDD_OCXO，确认电压符合预期。
4. 监测冷启动期间 VDD_OCXO 的跌落幅度，以及（若走方案 B）TPS78633 的表面温度。
5. 预热 30 分钟后再评估频率与相位噪声。

---

## 9. 待确认清单

**已核实**（对照 TPS786 数据手册 SLVS389M 与 LMK5B12204 数据手册 SNAS810C）：

| 项目 | 确认值 |
|---|---|
| TPS78633 最大输出电流 | **1.5 A** |
| SOT-223（DCQ，6 引脚）热阻 RθJA | **54.2 ℃/W**（JEDEC 9 in² 标准板） |
| TPS78633 压差 @1.5 A | 340 mV 典型 / 510 mV 最大 |
| TPS78633 负载调整率 | 7 mV（0～1.5 A） |
| LMK5B12204 核心 + 输出总电流 | 约 620 mA @3.3 V（APLL2 与四对 AC-LVDS 输出全开） |
| LMK5B12204 XO 输入绝对最大值 | **VDD + 0.3 V，约 3.6 V** — 5 V 摆幅直接接会损坏，见 7.2 |
| LMK5B12204 XO 单端输入摆幅上限 | 2.6 Vpp（3.3 V 驱动需按手册图 8-8 分压到 2.5 V） |

**仍待确认**（取决于你选的 OCXO 型号）：

| 项目 | 若不符的影响 |
|---|---|
| 目标 OCXO 稳态与冷启动电流 | 决定 USB 供电是否够用，本文按典型量级估算 |
| OCXO 输出波形与摆幅 | 决定是否需要分压网络（见 7.2） |
| OCXO 是否有 VREF 及其电压 | 决定 R32 分压电路改法（见 7.1） |
| 两个候选型号的引脚定义 | 假设 pin-to-pin 兼容，不兼容则整个方案不成立 |

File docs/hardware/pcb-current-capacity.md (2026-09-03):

# 2.54 mm 焊盘与 PCB 走线载流能力

本文回答两个问题：2.54 mm 间距的直插焊盘能过多大电流，以及走线宽度与电流的对应关系。所有数值给出计算依据，可按自己的板厚、铜厚、温升要求重算。

**适用范围说明：** 文中"2.54 焊盘"指 **2.54 mm 间距（100 mil）的直插排针 / 排母焊盘**，即 PTH 镀通孔加环形焊环。若指其他含义（例如直径 2.54 mm 的贴片焊盘），下文的连接器额定值一节不适用，但走线一节仍然成立。

---

## 1. 先给结论

**2.54 焊盘本身几乎从来不是瓶颈。** 一个 1.0 mm 孔径、25 µm 孔壁铜的镀通孔，其孔壁铜筒截面积约 0.079 mm²，相当于一条 2.3 mm 宽的 1 oz 走线，IPC-2221 在 ΔT = 10 °C 下算出约 4.3 A；插上引脚焊满锡之后实际截面还要大得多。排针引脚本体（0.64 mm 见方黄铜）截面 0.41 mm²，等效 1 oz 铜箔约 11.8 mm 宽。

**真正的限制按严苛程度排序是：**

1. **连接器 / 端子的厂商额定值** —— 通常 2～3 A 每针，这是硬约束，不可用铜箔计算去覆盖
2. **从焊盘引出的走线宽度** —— 本文第 3 节的对照表
3. **在两个焊盘之间穿线时被间距压缩的线宽** —— 2.54 间距下常见只剩 0.4～0.6 mm 可用
4. **压降** —— 低压供电场合它比温升更早成为瓶颈，见第 5 节

---

## 2. 焊盘与端子的载流

### 2.1 镀通孔孔壁

孔壁是一层铜筒，截面积按 `A = π × d × t` 计算，d 为孔径、t 为孔壁镀铜厚度（工艺常规值 20～25 µm）。把这个截面折算成等效的 1 oz 铜箔线宽，再代入 IPC-2221：

| 孔径 | 孔壁铜厚 | 铜筒截面 | 等效 1 oz 线宽 | 载流 (ΔT=10 °C) |
|---|---|---|---|---|
| 0.8 mm | 20 µm | 0.050 mm² | 1.44 mm | 3.1 A |
| 0.8 mm | 25 µm | 0.063 mm² | 1.81 mm | 3.7 A |
| 1.0 mm | 20 µm | 0.063 mm² | 1.81 mm | 3.7 A |
| 1.0 mm | 25 µm | 0.079 mm² | 2.26 mm | 4.3 A |
| 1.1 mm | 25 µm | 0.086 mm² | 2.48 mm | 4.6 A |

这是**空孔**的保守值。插件孔插入引脚并回流 / 波峰焊填锡后，导电截面变成"孔壁铜 + 焊锡 + 引脚"三者并联，实际能力显著高于此表。

### 2.2 端子额定值（这才是上限）

| 器件 | 典型额定电流 | 备注 |
|---|---|---|
| 普通 2.54 排针 / 排母（镀金） | 3 A / 针 | 单针满载；多针同时满载需降额 |
| 廉价镀锡排针 | 2 A / 针 | 接触电阻大，发热明显 |
| 杜邦线（26 AWG 压接） | 1 A | **线和压接点是瓶颈，不是排针** |
| 2.54 弹片式排母 | 2～3 A / 针 | 弹片接触面积小于插孔式 |

**降额规则：** 多针同时载流时，端子间互相加热，一般按 70～80 % 降额；连接器数据手册通常会给"同时通电针数 vs 降额系数"曲线。相邻多针并联供电是常规做法，两针并联按 1.6 倍而非 2 倍估算。

---

## 3. 走线宽度 vs 电流对照表

依据 **IPC-2221B** 经验公式：

```
I = k * dT^0.44 * A^0.725
```

- **I** —— 允许电流 (A)
- **dT** —— 允许温升 (°C)，即导体高出环境的温度
- **A** —— 导体横截面积 (mil²)，等于线宽 × 铜厚
- **k** —— 外层取 0.048（暴露在空气中），内层取 0.024（散热受阻，约为外层一半）

### 3.1 外层走线，1 oz 铜（34.8 µm）

| 线宽 (mm) | 线宽 (mil) | ΔT = 10 °C | ΔT = 20 °C | ΔT = 30 °C |
|---|---|---|---|---|
| 0.20 | 7.9 | 0.74 A | 1.01 A | 1.20 A |
| 0.25 | 9.8 | 0.87 A | 1.18 A | 1.41 A |
| 0.30 | 11.8 | 0.99 A | 1.35 A | 1.61 A |
| 0.40 | 15.7 | 1.23 A | 1.66 A | 1.99 A |
| 0.50 | 19.7 | 1.44 A | 1.95 A | 2.34 A |
| 0.60 | 23.6 | 1.64 A | 2.23 A | 2.67 A |
| 0.80 | 31.5 | 2.03 A | 2.75 A | 3.29 A |
| 1.00 | 39.4 | 2.38 A | 3.23 A | 3.86 A |
| 1.27 | 50.0 | 2.83 A | 3.84 A | 4.59 A |
| 1.50 | 59.1 | 3.20 A | 4.34 A | 5.18 A |
| 2.00 | 78.7 | 3.94 A | 5.34 A | 6.38 A |
| 2.54 | 100.0 | 4.68 A | 6.35 A | 7.59 A |
| 3.00 | 118.1 | 5.28 A | 7.17 A | 8.56 A |

**ΔT 怎么选：** 消费类 / 板内温度裕量充足时用 20 °C；密闭机箱、高环境温度、或走线经过热源附近时用 10 °C。ΔT = 30 °C 只用于短时或明确接受的场合——温升会叠加在环境温度上，FR-4 的 Tg 和阻焊层都有限度。

### 3.2 铜厚的影响（外层，ΔT = 10 °C）

| 线宽 (mm) | 0.5 oz (17.4 µm) | 1 oz (34.8 µm) | 2 oz (69.6 µm) |
|---|---|---|---|
| 0.25 | 0.53 A | 0.87 A | 1.44 A |
| 0.50 | 0.87 A | 1.44 A | 2.38 A |
| 1.00 | 1.44 A | 2.38 A | 3.94 A |
| 1.50 | 1.93 A | 3.20 A | 5.28 A |
| 2.00 | 2.38 A | 3.94 A | 6.51 A |
| 2.54 | 2.83 A | 4.68 A | 7.74 A |

铜厚翻倍，载流约提高 1.65 倍（不是 2 倍，因为指数是 0.725）。**注意成品铜厚 ≠ 基铜厚**：外层的成品铜厚 = 基铜 + 电镀铜，1 oz 外层实际常在 40～45 µm；而内层没有电镀，1 oz 就是 34.8 µm。上表按标称值计算，属保守。

### 3.3 内层走线，1 oz 铜

| 线宽 (mm) | ΔT = 10 °C | ΔT = 20 °C |
|---|---|---|
| 0.25 | 0.44 A | 0.59 A |
| 0.50 | 0.72 A | 0.98 A |
| 1.00 | 1.19 A | 1.62 A |
| 1.50 | 1.60 A | 2.17 A |
| 2.00 | 1.97 A | 2.67 A |
| 2.54 | 2.34 A | 3.18 A |

内层能力约为外层的一半。这是 IPC-2221 的保守假定；实际多层板内层夹在覆铜层之间，横向导热反而不差，IPC-2152 对此有修正。

### 3.4 反查：给定电流需要多宽（外层 1 oz）

| 目标电流 | ΔT = 10 °C | ΔT = 20 °C |
|---|---|---|
| 0.5 A | 0.12 mm | 0.08 mm |
| 1 A | 0.30 mm | 0.20 mm |
| 1.5 A | 0.53 mm | 0.35 mm |
| 2 A | 0.79 mm | 0.52 mm |
| 3 A | 1.37 mm | 0.90 mm |
| 4 A | 2.04 mm | 1.34 mm |
| 5 A | 2.78 mm | 1.83 mm |

**记忆用的粗略口诀：1 oz 外层，1 mm 宽 ≈ 2.4 A（ΔT=10 °C）或 3.2 A（ΔT=20 °C）。** 工程上常说的"1 mm 走 1 A"是带了 2 倍以上裕量的保守习惯，用于电源主干很合适。

---

## 4. 2.54 间距下实际能走多宽

排针焊盘的外径压缩了可用布线空间。设焊盘外径 D，走线从两个相邻焊盘**中间穿过**，两侧各留间隙 c，则可用线宽为 `W = 2.54 − D − 2c`：

| 焊盘外径 D | 焊盘边缘净距 | 间隙要求 c | 可穿线宽 | 载流 (1 oz, ΔT=10 °C) |
|---|---|---|---|---|
| 1.4 mm | 1.14 mm | 0.15 mm | 0.84 mm | 2.10 A |
| 1.4 mm | 1.14 mm | 0.20 mm | 0.74 mm | 1.91 A |
| 1.6 mm | 0.94 mm | 0.15 mm | 0.64 mm | 1.72 A |
| 1.6 mm | 0.94 mm | 0.20 mm | 0.54 mm | 1.52 A |
| 1.8 mm | 0.74 mm | 0.20 mm | 0.34 mm | 1.09 A |
| 1.8 mm | 0.74 mm | 0.25 mm | 0.24 mm | 0.85 A |

**这一节是全文最实用的部分。** 焊盘画大一点看起来更结实，但代价是穿线宽度直接被吃掉，反而降低了整体载流。1.6 mm 是 1.0 mm 孔径下的常用折中。

**如果不需要穿线**（走线直接从焊盘引出、向外扩散），线宽不受 2.54 间距限制，可以立刻放大到 1～2 mm，只要对相邻焊盘保持 0.2 mm 以上间隙即可。**大电流引脚应当排在连接器两端或专门留出扩线空间**，而不是夹在信号针中间。

**间距耐压：** 2.54 间距、焊盘外径 1.6 mm 时边缘净距 0.94 mm，按 IPC-2221 表 6-1 的 B1 类（外层带阻焊）足以支持数百伏；常规 2.54 连接器的厂商额定值多在 250 VAC / DC 量级，通常由塑胶本体而非 PCB 间距决定。

---

## 5. 别只看温升：压降往往先到极限

IPC-2221 只回答"会不会烧"，不回答"电压够不够"。铜箔的方块电阻：

| 铜厚 | 方块电阻 |
|---|---|
| 0.5 oz | 0.99 mΩ/□ |
| 1 oz | 0.49 mΩ/□ |
| 2 oz | 0.25 mΩ/□ |

一段走线的电阻 = 方块电阻 × （长度 ÷ 线宽）。1 oz 铜每 10 mm 长度的电阻：

| 线宽 | 每 10 mm 电阻 | 1 A 时压降 |
|---|---|---|
| 0.25 mm | 19.8 mΩ | 19.8 mV |
| 0.50 mm | 9.9 mΩ | 9.9 mV |
| 1.00 mm | 4.9 mΩ | 4.9 mV |
| 2.00 mm | 2.5 mΩ | 2.5 mV |

**例子：** 3.3 V 供电，允许 1 % 压降即 33 mV。一条 0.5 mm 宽、50 mm 长的 1 oz 走线载 1 A，电阻 49 mΩ，压降 49 mV —— **温升上完全合格（0.5 mm 可过 1.44 A），压降上已经超标。** 此时应加宽到 1 mm 以上或改用覆铜。

低压大电流（1.2 V 内核供电、3.3 V 数字轨）几乎总是压降先受限；12 V 以上的场合才轮到温升说话。

---

## 6. 使用这些数字时的注意事项

**IPC-2221 的局限。** 该公式源自 1950 年代 NBS 的实测数据，样本条件单一，未考虑板材导热率、相邻铜箔面积、板厚、是否有内层铜平面等因素。**IPC-2152（2009）** 是其替代标准，给出按板材和结构分类的曲线，对散热良好的场合（有大面积内层铜、厚板）结果比 2221 宽松 1.5～2 倍，对孤立薄板则更严。做成本敏感的大电流设计时值得查 IPC-2152。IPC-2221 作为保守估算仍然完全可用。

**这些是连续电流。** 短时脉冲（毫秒级）可以远超此值，铜的热容提供缓冲；但若脉冲重复频率高，仍按平均功率折算的等效连续电流处理。

**提高载流的几个手段，按性价比排序：**

1. 加宽走线 —— 最直接，成本为零
2. 大面积覆铜代替线条 —— 电源和地平面本来就该这么做
3. 焊盘 / 走线开阻焊窗后铺锡 —— 可提高 30～50 %，但锡厚不可控、不可靠，仅作补充手段，不应作为设计依据
4. 多层并联 + 密集过孔换层 —— 有效但占空间，注意过孔数量要匹配（每个 0.3 mm 孔约 1 A）
5. 加厚铜箔 (2 oz) —— 有效但抬高板费，且细线工艺能力下降（2 oz 板的最小线宽/间距通常放宽到 0.15 mm 以上）

**装配与工艺的约束往往先于电气约束。** 大电流焊盘连着大面积覆铜会造成焊接吸热、虚焊和立碑，必须使用**热隔离焊盘（thermal relief）**；但热隔离本身会削减载流路径，大电流场合应改为实心连接并在工艺上补偿（提高预热温度、局部加热）。这两者的取舍需要与板厂 / 贴片厂确认。

---

## 7. 快速查表（最常用的几个数）

外层 1 oz 铜，ΔT = 10 °C，工程保守取整：

| 线宽 | 可过电流 | 适用场合 |
|---|---|---|
| 0.25 mm | 0.8 A | 信号线、低功耗支路 |
| 0.50 mm | 1.4 A | 2.54 焊盘间穿线的典型上限 |
| 1.00 mm | 2.4 A | 一般电源支路 |
| 1.50 mm | 3.2 A | 电源主干 |
| 2.54 mm | 4.7 A | 到这个宽度建议直接改用覆铜 |

2.54 排针：单针按 **2 A** 设计（3 A 额定留裕量），需要更大电流就并联多针，两针并联按 3.2 A 而非 4 A 计。

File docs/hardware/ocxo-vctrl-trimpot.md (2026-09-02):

# OCXO 压控端电位器接法

本文说明 U6（OCXO-10M）压控端 VCTRL 的外围电路设计：为什么加电位器、阻值怎么选、引脚怎么分配、以及校准和布局要点。适用于 5 V 供电、带 VREF 输出的压控恒温晶振（VCOCXO）。

---

## 1. 这个电路解决什么问题

OCXO 出厂时的绝对频率总有偏差，典型初始精度在 ±0.1 ppm 到 ±1 ppm 之间；此外晶体存在老化，首年典型 ±1 ppm，之后每年 ±0.2 ppm 到 ±0.5 ppm。这些偏差无法靠恒温槽消除，必须通过压控端 VCTRL 施加一个直流电压把频率拉回标称值。

VCTRL 上的电压决定了内部变容二极管的容值，进而微调晶体的负载电容。典型 5 V OCXO 的压控范围是全程 0 到 5 V 对应 ±0.5 ppm 到 ±2 ppm，也就是说这是一个**极窄、极敏感**的调节口——5 V 的跨度只换来百万分之几的频率变化，因此供给它的电压必须干净且稳定。

电位器方案适用于两种场合：一是产品出厂前手工校准一次，之后不再动；二是 GPSDO 等闭环系统在调试阶段作为 DAC 的临时替代。如果最终要做闭环驯服，VCTRL 应当由 DAC 驱动，电位器只保留为调试备份（见第 9 节）。

---

## 2. 推荐接法

@fig:ocxo_vctrl 图 1　压控端电位器分压 + RC 低通接入 VCTRL

电路由三部分组成：R32 构成分压器产生可调直流；R33 与 C51 构成低通滤波器；U6 的 VREF 引脚为分压器提供基准供电。三者缺一不可，下面逐个说明理由。

| 位号 | 值 | 型号 / 封装 | 作用 |
|---|-----|---|---|
| R32 | 10 kΩ | 3296W-1-103，25 圈顶调 | 分压产生 VCTRL |
| R33 | 1 kΩ | 0603，±1%，厚膜 | RC 低通串联电阻 |
| C51 | 100 nF | 0603，X7R，50 V | RC 低通滤波电容 |

---

## 3. 为什么选 10 kΩ

电位器阻值的选择由三个约束共同决定，10 kΩ 是三者的交集。

**约束一：相对 VCTRL 输入阻抗要足够低。** 这是首要约束。分压器的戴维南等效输出电阻在滑动端位于中点时最大，等于 R32/4 = 2.5 kΩ，再串上 R33 的 1 kΩ，总源阻抗 3.5 kΩ。VCTRL 的输入阻抗 R_in 与之分压，造成的电压压缩误差为 3.5k / (3.5k + R_in)：

| VCTRL 输入阻抗 | 压缩误差 | 评价 |
|---|---|---|
| 1 MΩ | 0.35% | 可忽略 |
| 100 kΩ | 3.4% | 可接受 |
| 10 kΩ | 26% | 不可接受，需改用 1 kΩ 电位器 |

需要说明的是，这个误差在手工闭环校准下**不影响功能**——你是一边看频率计一边拧螺丝，开环精度并不重要。它的真实代价是压缩了可用调节范围、并让中点偏移。只有当 R_in 低到 20 kΩ 以下时，压缩才严重到吃掉老化余量，那时应当把 R32 换成 1 kΩ 到 2 kΩ 的规格。**动手前务必查手册确认这一项。**

**约束二：功耗。** 5 V 下 10 kΩ 分压支路的电流是 0.5 mA，功耗 2.5 mW。若改用 1 kΩ，电流升至 5 mA——OCXO 本身发热就大，没必要再额外增加负担；更关键的是 VREF 供电通常带不动这么大电流（见第 6 节）。

**约束三：噪声与污染敏感度。** 阻值越高，热噪声越大，且对 PCB 表面漏电流（助焊剂残留、潮气）越敏感。100 kΩ 的噪声比 10 kΩ 高 10 dB。不过按第 7 节的核算，即便 100 kΩ 的噪声贡献也远低于 OCXO 自身本底，所以这一条是次要理由，真正卡死上限的是约束一。

**为什么必须是多圈。** 25 圈电位器在 0 到 5 V 全程下每圈对应 200 mV。单圈电位器（3386 之类）一圈走完 5 V，配合 ±1 ppm 的压控范围，等于一圈跨越全部调节量，实际根本无法定位。这一点没有折中余地。

---

## 4. 引脚分配决定旋转方向

R32 的 pin1 与 pin3 是电阻体两端，电气上可互换；pin2 是滑动端。互换与否不影响功能，但决定了螺丝刀的旋转方向对应升频还是降频。

Bourns 3296 系列数据手册的规范是：**顺时针旋转调节螺丝，terminal 1 与 terminal 2 之间的电阻增大**，即滑动端从 pin1 端移向 pin3 端。据此：

- pin1 接 GND、pin3 接 VREF：顺时针 → 滑动端趋向 VREF → VCTRL 升高 → 频率升高
- 反接：顺时针 → 频率降低，与直觉相反

图 1 采用前者。这纯粹是人机工程考量，但校准时手感差别明显，尤其在需要反复微调时容易调错方向。

---

## 5. RC 低通的作用

R33 与 C51 构成一阶低通，截止频率为：

```
fc = 1 / (2π × 1 kΩ × 100 nF) ≈ 1.6 kHz
```

它承担两个职责：

1. **滤除分压网络上的噪声。** 分压器的热噪声、VREF 上残留的纹波、以及经空间耦合进这条走线的干扰，在 1.6 kHz 以上被逐步衰减。
2. **抑制调节过程中的接触抖动。** 拧动电位器时滑动端与电阻体的接触电阻会瞬间跳变，若无滤波，这些毛刺会直接调制到 VCTRL 上，表现为频率跳变，让你误以为调过头了。加上 C51 后调节手感会平滑很多。

C51 必须**紧贴 U6 的 pin3 放置**，让滤波节点位于负载端而不是源端；放在电位器旁边则失去大部分作用，因为从电容到 VCTRL 的那段走线仍在裸露拾取干扰。

R33 不宜取太大：它串在源阻抗上，会加剧第 3 节的压缩误差。1 kΩ 是兼顾滤波效果和源阻抗的合理值；若要更低的截止频率，应加大 C51（例如 1 µF，fc 降至 160 Hz），而不是加大 R33。

---

## 6. 供电来源：VREF 还是 +5V

U6 的 pin4 是 VREF，多数带此引脚的 OCXO 都把它设计成专供外部调频网络使用的内部基准，其温度系数和噪声都优于板上的 5 V 电源轨。**优先使用 VREF。**

用之前查手册确认两项：

- **输出电流能力。** 10 kΩ 分压在 5 V 下需要 0.5 mA，绝大多数型号的 VREF 能提供 1 mA 到 2 mA。但有些手册明确写着「reference output only, do not load」，那就不能用。
- **输出电压值。** 常见为 4.0 V 或 5.0 V，它决定 VCTRL 的实际可达区间是否覆盖手册要求的全压控范围。若 VREF 是 4.0 V 而压控范围标称 0 到 5 V，则调节范围会损失 20%。

若 VREF 不可用，把 R32 的 pin3 改接 +5V，但**不要直接挂在给 VCC 供电的那条 5 V 上**——OCXO 恒温槽的加热电流是断续的大电流，会在电源上产生几十毫伏的波动，直接串进 VCTRL 就是频率抖动。应当单独滤一路：从 +5V 串 100 Ω，再对地接 10 µF，从这个滤波节点取电给电位器。

---

## 7. 噪声与温漂核算

**热噪声。** 分压器中点等效源阻抗 2.5 kΩ，室温下电压噪声密度为：

```
en = √(4kTR) = √(4 × 1.38e-23 × 300 × 2500) ≈ 6.4 nV/√Hz
```

以典型压控灵敏度 ±1 ppm 对应 0 到 5 V 计算，Kv = 2 ppm / 5 V = 0.4 ppm/V，在 10 MHz 上即 4 Hz/V。折算到频率噪声密度约 2.6e-8 Hz/√Hz，在 10 Hz 偏置频率处对应的相位噪声贡献约 −175 dBc/Hz。而 OCXO 自身在 10 Hz 偏置的相位噪声典型值为 −120 dBc/Hz，两者相差 55 dB。**结论：分压网络的热噪声完全被淹没，不构成设计约束。**

**温漂。** 3296 的电阻温度系数是 ±100 ppm/°C，但用作分压器时两段电阻体同步变化，分压比的温漂远小于单个电阻的 TCR，实际在几十 ppm/°C 量级。以 50 ppm/°C、VCTRL = 3 V 计，温漂为 150 µV/°C，折算频率漂移约 0.6 mHz/°C，即 6e-11/°C。而 OCXO 自身的温度稳定性典型为全温区 ±5e-9。**结论：电位器温漂同样不是瓶颈。**

这两项核算的意义在于：不必为这个电路选购高精度低温漂的贵价电位器，普通 3296 足矣。真正需要控制的是机械稳定性（防振动导致滑动端位移）和长期接触可靠性。

---

## 8. 调节分辨率与余量规划

以 ±1 ppm 全范围、25 圈电位器计算：

| 项目 | 数值 |
|---|---|
| 每圈对应电压 | 5 V / 25 = 200 mV |
| 每圈对应频率变化 | 0.08 ppm = 0.8 Hz @ 10 MHz |
| 螺丝刀实际可控（约 1/10 圈） | 0.008 ppm ≈ 0.08 Hz @ 10 MHz |

这个分辨率对手工校准和 GPS 比对完全够用。

**不要压缩调节范围。** 常见的做法是在电位器上下各串一个固定电阻，把输出限制在例如 2 V 到 3 V 以提高分辨率。对本电路不建议这么做：OCXO 每年老化 ±0.2 ppm 到 ±1 ppm，若压控总范围只有 ±1 ppm，压窄之后一两年就会调到头，届时必须返修。25 圈已经解决了分辨率问题，没有理由再牺牲余量。

**初始设定在中点。** 首次校准时，应先把滑动端置于行程中点（VCTRL ≈ VREF/2），再微调至目标频率。这样为后续老化留出了双向余量。若首次校准就把螺丝拧到接近某一端，说明这颗 OCXO 的初始偏差已经吃掉大半调节量，应考虑更换。

---

## 9. PCB 布局与校准

**布局要点：**

- C51 紧贴 U6 的 pin3，滤波节点尽量靠近负载。
- VCTRL 走线尽可能短，远离开关电源电感、晶振输出走线和任何数字信号，必要时两侧包地。
- 电位器摆放在板边或便于伸入螺丝刀的位置，且调节时手和工具不应压到其它元件。
- 电位器下方及 VCTRL 走线下方保持完整地平面，不要走高速信号。
- 该区域焊后彻底清洗助焊剂残留；若工作环境潮湿，可对电位器以外的区域涂三防漆。

**校准步骤：**

1. 上电后**预热至少 30 分钟**。OCXO 达到热平衡需要时间，冷机状态下的读数无意义。
2. 将 R32 拧至行程中点（顺时针拧到底后逆时针回退约 12 圈）。
3. 用频率计或 GPS 参考比对输出频率，记录偏差方向。
4. 顺时针升频、逆时针降频，逐步逼近标称值。每次调节后等待读数稳定再判断。
5. 记录最终的圈数位置和剩余余量，存档以便日后判断老化程度。

---

## 10. 后续演进：换成 DAC

若本项目最终要做 GPSDO（GPS 驯服振荡器），VCTRL 需要由闭环环路驱动，电位器无法胜任。届时的改动方式：

- 用 16 位 DAC（例如 DAC8551）或带缓冲的 12 位 DAC（例如 MCP4922）替代 R32 的滑动端输出。
- 16 位 DAC 在 5 V 满量程下的步进为 76 µV，对应 0.00006 ppm，分辨率远优于手工调节。
- DAC 输出后仍保留 R33 与 C51，滤除 DAC 的开关毛刺和量化噪声。
- 布板时可在滑动端与 R33 之间预留一个 0 Ω 跳线位，方便在电位器与 DAC 之间切换，调试期用电位器，量产版本改贴 DAC 走线。

---

## 附：待确认事项

本文的数值以典型 5 V VCOCXO 为例。定板前需从所选型号的数据手册确认下列参数，若与假设不符需重新核算：

| 参数 | 本文假设 | 影响 |
|---|---|---|
| VCTRL 输入阻抗 | ≥ 100 kΩ | 决定 R32 阻值上限（第 3 节） |
| VCTRL 电压范围 | 0 到 5 V | 决定分压器供电电压 |
| 压控灵敏度 | ±1 ppm 全范围 | 决定调节分辨率（第 8 节） |
| VREF 电压与带载能力 | 5.0 V，≥ 1 mA | 决定能否用 VREF 供电（第 6 节） |
| 压控极性 | 正斜率（电压升、频率升） | 决定 pin1/pin3 分配（第 4 节） |

另外，当前原理图上 U6 的 pin5（VCC）所在网络同时标注了 +3.3V 与 +5V 两个电源符号，需要确认是否为绘图笔误——若两者被短接将导致电源短路。

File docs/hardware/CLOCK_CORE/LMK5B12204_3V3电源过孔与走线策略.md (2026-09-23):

# LMK5B12204 — 3.3V 电源过孔位置与走线层策略（rev2）

本文回答三个问题：3.3V 进磁珠之前是不是先经过电容？3.3V 电源过孔打在哪里？3.3V 走哪一层？

> rev2 更正：rev1 漏掉了磁珠输入侧的电容，并沿用了旧板的位号。本版位号全部取自当前 `CLOCK_CORE.kicad_pcb` 的焊盘网络。

---

## 1. 结论

| 问题 | 答案 |
|---|---|
| 是否先经过电容再到磁珠 | **是。** 每一路都是 π 型：`+3.3V → 输入电容 → 磁珠 → 10 µF → VDDxx → 引脚 100 nF` |
| 过孔打在哪里 | **打在输入电容的 +3.3V 焊盘外侧**，电流先经过输入电容焊盘，再进磁珠 pad1 |
| 3.3V 走哪一层 | 推荐 **L3 (In2.Cu) 整面 +3.3V**；当前 In2.Cu 是空的，+3.3V 铺在 F.Cu 上 |
| 磁珠之后怎么走 | 域内电源不再打回 L3，在元件所在面用短线连 10 µF 和引脚电容 |

---

## 2. 当前板的实际拓扑

从 PCB 焊盘网络提取：

| 电源域 | 输入电容（+3.3V 侧） | 磁珠 | 输出电容（域侧） | 引脚电容 | 元件面 |
|---|---|---|---|---|---|
| VDDIN | C32 100 nF | FB1 | C33 10 µF | C52 100 nF | F |
| VDDXO | C35 100 nF | FB2 | C36 10 µF | C59 100 nF | B |
| VDDPLL1 | C38 100 nF | FB3 | C39 10 µF | C53 100 nF | B |
| VDDPLL2 | C41 1 µF | FB4 | C42 10 µF | C54 100 nF | B |
| VDDDIG | C44 1 µF | FB5 | **无** | C51 100 nF | F |
| VDDO0_1 | C46 100 nF | FB6 | C47 10 µF | C34、C37 100 nF | F（引脚电容在 B） |
| VDDO2_3 | C49 100 nF | FB7 | C50 10 µF | C40、C43、C48、C55 100 nF | F（部分引脚电容在 B） |

注意 VDDDIG 磁珠后面没有 10 µF，只有引脚上的 C51。是否需要补，取决于原理图的设计意图，这里只指出。

---

## 3. 为什么输入电容要排在磁珠前面、过孔要先到电容

π 型滤波 C–FB–C 里，输入电容有两个作用：

1. **挡住来自 3.3V 母线的高频噪声**：噪声在进磁珠之前就被旁路到地。
2. **挡住本域漏回母线的噪声**：VDDO 输出级的开关电流会穿过磁珠反向漏回 +3.3V，输入电容把它就地吸收，不让它通过公共母线串到 VDDXO、VDDPLL 这些敏感域。

输入电容和磁珠 pad1 在电气上是同一个节点，但在 PCB 上每毫米走线约 1 nH。100 MHz 时 1 nH 的感抗是 0.63 Ω，已经和 100 nF 电容的阻抗在同一量级。所以**电流路径上的先后顺序是有意义的**：

```
推荐：   过孔 ─→ [C_in +3.3V 焊盘] ─→ [FB pad1] ─磁珠─ [FB pad2] ─→ 10µF ─→ 引脚
                     │
                  GND过孔

不推荐： 过孔 ─→ [FB pad1] ─磁珠─ ...
                   │
              (一段支线) ─→ [C_in]        ← 电容挂在支线末端，高频旁路打折
```

**具体尺寸：**

| 项 | 要求 |
|----|---|
| 电源过孔位置 | C_in 的 +3.3V 焊盘外侧（背向磁珠一侧），间距 ≤ 0.3 mm |
| C_in 与 FB pad1 | 焊盘紧挨，间隙 ≤ 0.5 mm，可直接用铜皮连成一块 |
| C_in 的 GND | 焊盘外 0.4 mm 内打 GND 过孔，落 L2 |
| 过孔规格 | 0.6/0.3 mm，嘉立创常规工艺；不用盘中孔 |

若空间实在不够，过孔可以打在 C_in 焊盘和 FB pad1 之间的连接铜上，仍然是可接受的；要避免的只是"过孔直接落在磁珠 pad1，电容挂在另一头"。

---

## 4. 3.3V 走哪一层

### 4.1 当前状态

| 层 | 当前铜 |
|----|---|
| F.Cu | 信号 + +3.3V / +5V / OCXO_VCC 等多块铺铜 |
| In1.Cu | GND 整面 |
| In2.Cu | **空，没有任何铜** |
| B.Cu | 部分磁珠和去耦电容 |

### 4.2 推荐：+3.3V 整面放到 In2.Cu

- **F.Cu 空间让给信号**：8 对差分输出、XO_P、PRIREF 都在 F.Cu，+3.3V 铺铜会把它们挤得绕行。
- **B.Cu 的磁珠也能就近取电**：FB2、FB3、FB4 在背面。+3.3V 在 In2.Cu 时，背面输入电容旁打一个过孔即可；现在 +3.3V 在 F.Cu，背面元件要从正面过孔穿过来。
- **In2.Cu 可以分割**：F.Cu 的信号参考的是 In1.Cu 的 GND，In2.Cu 上把 +3.3V、+5V、OCXO_VCC 分块不影响信号回流。

### 4.3 磁珠之后不要回 In2.Cu

磁珠 pad2 之后的 VDDxx 是本域专用网络。在元件所在的那一面用 ≥ 0.3 mm 的短线连到 10 µF 和引脚电容；引脚电容在另一面时，用一个过孔穿过去，这个过孔穿 In2.Cu 时要开 antipad，不能碰 +3.3V。

---

## 5. 完整路径（以 VDDPLL1 为例，元件在 B.Cu）

```
LDO 输出 ─(F.Cu)─ 过孔 ─ In2.Cu +3.3V 整面 ─ 过孔(C38 外侧) ─→ C38 焊盘 ─→ FB3 pad1
   ─磁珠─ FB3 pad2 ─(B.Cu 短线)─ C39 10µF ─ C53 100nF ─ 过孔 ─→ U5 pin27 VDD_PLL1

回流：U5 E-PAD ─ 过孔阵列 ─ In1.Cu GND 整面 ─ 各电容 GND 过孔
```

---

## 6. 检查清单

| 项 | 判据 |
|----|---|
| 七路电源 | 过孔 → 输入电容 → 磁珠 → 输出电容 → 引脚电容，顺序不颠倒 |
| 电源过孔 | 在输入电容 +3.3V 焊盘外侧 ≤ 0.3 mm |
| 输入电容与磁珠 | 焊盘间隙 ≤ 0.5 mm |
| 每颗电容 GND | 焊盘外 0.4 mm 内有 GND 过孔 |
| +3.3V | 在 In2.Cu 整面铺铜，U5 散热过孔阵列区域避开 |
| VDDxx 过孔穿 In2.Cu | 开 antipad，不连 +3.3V |
| In1.Cu | GND 整面，不分割 |
| VDDDIG | 确认是否需要补磁珠后的 10 µF |

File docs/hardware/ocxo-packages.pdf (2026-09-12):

CLOCK 项目 · 硬件设计文档 | 第 1 页

# 常见方形 OCXO 封装

CLOCK 项目 · OCXO 封装选型

本文整理方形 OCXO 的工业标准平台尺寸、引脚栅格与选型影响，并给出一块 PCB 兼容多种尺寸的画法。尺寸数据取自厂商手册与本项目现用封装库，具体型号仍须以其自身手册为准。

摘要

一、方形 OCXO 只有五个工业标准平台尺寸：50 × 50、36 × 27、25.4 × 25.4、20 × 20、20 × 13 mm，加上后来的 SMD 小型化系列（14 × 9、9.7 × 7.5、7 × 5）。不是厂家想做多大就多大——这几个尺寸是 历史形成的，同尺寸不同厂家的产品外形和引脚栅格基本可以互换。

二、但引脚功能分配没有标准。 同样是 25.4 mm 五脚封装，A 家的 1 脚是输出、B 家的 1 脚可能是压控。换型号必须重查手册，这是这类器件最容易翻车的地方。

三、尺寸直接决定性能和功耗。
罐子越大、晶体越大、恒温槽热容越大，相噪和老化越好，但预热越慢、功耗越高。50 × 50 那一档是双恒温槽，7 × 5 那一档的稳定度已经接近好一点的 TCXO。

四、供电电压不改变恒温槽功率，只改变电流。 同一颗 OCXO 的 3.3 V 版本电流是 5 V 版本的 1.5 倍。这一条直接决定你的供电架构能不能用 LDO。

## 1. 工业标准平台尺寸

同一角对齐 · 按实际比例

50 × 50 mm | 2 × 2 in，双恒温槽 / 最高性能
36 × 27 mm | Eurocase，也写作 25 × 37
25.4 × 25.4 mm | 1 × 1 in　★ 本项目在用
20 × 20 mm | 0.8 × 0.8 in
20 × 13 mm | 4 脚 DIP
14 × 9 mm | SMD，小型化主力
9.7 × 7.5 mm | SMD 迷你
7 × 5 mm | SMD 极小，性能受限

尺寸越大 → 晶体越大、恒温槽热容越大
→ 相噪与老化更好，但预热更慢、功耗更高

图 1 常见方形 OCXO 平台尺寸对比（同一角对齐，按实际比例）

尺寸 (mm) | 英寸 | 引脚 | 典型定位
50 × 50 | 2 × 2 | 多脚 | 双恒温槽 OCXO，最高稳定度，铷钟以下最好的一档
36 × 27 | — | 5 / 7 / 8 | Eurocase，也写作 25 × 37。电信与测量仪器的主力
25.4 × 25.4 | 1 × 1 | 5 | 最通用的一档，选择面最广 ★ 本项目在用

CLOCK 项目 · 硬件设计文档 | 第 2 页
尺寸 (mm) | 英寸 | 引脚 | 典型定位
20 × 20 | 0.8 × 0.8 | 5 | 小型化通孔
20 × 13 | — | 4 | 4 脚 DIP
14 × 9 | — | 4 SMD | SMD 小型化主力
9.7 × 7.5 | — | 4 SMD | 迷你 SMD
7 × 5 | — | 4 SMD | 极小，性能接近高端 TCXO

前五种是通孔金属罐，后三种是 SMD。通孔与 SMD 之间没有兼容性，选型时这是第一个分岔口。

厂商的评估板通常按这几个尺寸做成一块通用夹具——Microchip/Vectron 的 OCXO 评估板就是一块板同时兼容 13 × 20、20 × 20、25 × 25、25 × 37、50 × 50 五种，这从侧面证明了这几个尺寸的标准化程度。

## 2. 25.4 × 25.4 mm：本项目在用的封装

1 | 2 | 3

5 4

25.4

19.05 引脚栅格 | 引脚定义（本项目所用型号）
1 | RF OUT | 时钟输出，正弦或方波
2 | GND | 电路地，通常与外壳相连
3 | VCTRL | 压控调频，不用时可悬空
4 | VREF | 基准电压输出，部分型号为 N/C
5 | VCC | 供电，3.3 / 5 / 12 V 按型号

引脚定义没有行业标准

同样是 25.4 mm 五脚，各厂家分配可能完全不同，换型号必须重查手册

图 2 25.4 mm 封装的焊盘布置与引脚定义

这是最通用的一档，也是本项目 JLCImport:DOPFITKR2-10M 用的封装：

项目 | 数值
外形 | 25.4 × 25.4 mm
引脚栅格 | 19.05 × 19.05 mm（0.75 英寸）
引脚数 | 5
引脚排布 | 一条边三个（两角 + 中点），对边两个角
引脚孔径 | 1.6 mm（本项目封装）

引脚栅格 19.05 mm 是关键尺寸，不是外形 25.4 mm。 换同尺寸的其它型号时，先核对栅格——绝大多数是 19.05，但不能想当然。

本项目所用型号的引脚功能：

CLOCK 项目 · 硬件设计文档 | 第 3 页
脚 | 功能 | 说明
1 | RF OUT | 时钟输出，正弦或方波
2 | GND | 电路地，通常与外壳相连
3 | VCTRL | 压控调频（EFC），不用时按手册处理
4 | VREF | 基准电压输出，部分型号为 N/C
5 | VCC | 供电，3.3 / 5 / 12 V 按型号

## 3. 36 × 27 mm：性能上一档

以 CTS Model 196 为例，这一档相对 25.4 mm 的差别在指标而不只是体积：

项目 | CTS 196（36 × 27）
外形 | 36.068 × 27.178 mm（最大值）
高度 | 13.462 mm（最大值）
引脚栅格 | 手册标注 12.70 / 15.24 / 17.78 / 25.40 mm 等多个基准尺寸
供电选项 | 3.3 V / 5 V / 12 V
预热功耗 | 4 W
稳态功耗 | 1.5 W @ 25 °C
预热时间 | 4 分钟到 50 ppb 以内
温度稳定度 | ±5 ppb（−10~70 °C）/ ±10 ppb（−40~85 °C）
电源牵引 | ±5 ppb（电源 ±5%）
老化 | ±1 ppb/天，±100 ppb/年
相噪 @10 MHz | −90 / −125 / −140 / −150 / −155 dBc/Hz（1 Hz / 10 Hz / 100 Hz / 1 kHz / 10 kHz）

注意那个电源牵引数字：±5 ppb 对应电源变化 ±5%。 这比常见的经验值（±0.01 ~ 0.1 ppm）好一个数量级。换算过来，电源稳到 ±1% 时牵引只有 ±1 ppb——远小于温度稳定度。这条数据支持一个结论：只要外部电源本身是稳压的，OCXO 供电没必要追求极低噪声，把电压稳住就够了。

引脚栅格这一项我没有从手册里可靠地还原出每个引脚的坐标，画封装前必须对着厂家的机械图逐个核。

## 4. 小型化方向：SMD 封装

14 × 9 mm 是目前小型化的主力，再往下有 9.7 × 7.5 和 7 × 5。代价很直接：

- 热容小 → 温度稳定度差。7 × 5 那一档的稳定度已经接近高端 TCXO，OCXO 的优势被压缩
- 预热快但保持能力弱。恒温槽小意味着对环境温度突变的抵抗力弱
- 相噪抬高。晶体小、Q 值低，近端相噪明显不如大罐子

小型化 OCXO 适合"体积优先、稳定度够用"的场合。如果这块板的定位是频率基准，不建议为了小型化牺牲到 9.7 × 7.5 以下。

CLOCK 项目 · 硬件设计文档 | 第 4 页

## 5. 引脚定义没有标准，这是最大的坑

平台尺寸是标准化的，引脚功能分配不是。

同样是 25.4 mm 五脚封装，不同厂家的 1 脚可能是输出、压控或基准电压。CTS 196 的手册里五个引脚是 Output / GND / VDD / Vref-or-NC / VC-or-NC，但编号顺序和本项目所用型号并不相同。

后果很严重：外形和栅格完全一致，插上去严丝合缝，但 VCC 和 RF 输出对调了。 这类错误在装配前看不出来，上电就烧。

三条防范措施：

1. 每换一个型号，重新对一遍机械图的引脚编号与功能表，不要复用旧封装
2. 在原理图符号和封装的注释里写死型号，比如 OCXO-10M (DOPFITKR2-10M only)
3. 第一次打样留 0Ω 跳线的余地，或者至少把 VCC 和 GND 的走线画成可切割的形式

## 6. 一块板兼容两种尺寸

25.4 × 25.4 外形

20 × 20 外形

两套焊盘
同时存在

做法要点

两套通孔焊盘按各自栅格并存

19.05 与 12.7 相差 3.175 mm，互不重叠

同功能引脚连到同一网络

铜箔在内层或元件面短接即可

丝印画两个外形框

标注清楚哪个框对应哪个型号

禁布区按大的那个算

25.4 的外形决定周围留空

只焊其中一套

另一套空着，不影响电气

前提：两种型号的引脚功能顺序一致

不一致时只能各画各的，或用 0Ω 跳接改线

图 3 25.4 mm 与 20 × 20 mm 焊盘叠放

19.05 mm 和 12.7 mm 两套栅格相差 3.175 mm，焊盘互不重叠，可以并存在同一块板上。做法要点：

- 两套通孔焊盘按各自栅格并排画，同功能引脚连到同一网络
- 丝印画两个外形框，标清楚哪个框对应哪个型号
- 禁布区按大的那个算，25.4 的外形决定周围留空
- 装配时只焊其中一套，另一套空着

前提是两种型号的引脚功能顺序一致。 不一致时，要么各画各的、用 0Ω 跳接改线，要么放弃兼容。

这个做法的代价是焊盘密度变高、内层被打断的过孔变多，对 4 层板的地平面完整性有影响。只在确实需要选型灵活性时才做。

## 7. 供电电压怎么选

CLOCK 项目 · 硬件设计文档 | 第 5 页

1212 mA

455

### 3.3 V

800 mA

300

### 5 V

333 mA

125

### 12 V

电流

供电电压

预热 4 W | 稳态 1.5 W | 恒温槽要的是功率，不是电压

同一颗 OCXO 换供电电压，功率不变、电流按反比变

供电 | 预热电流 | 5V→该轨 LDO 损耗
3.3 V | 1212 mA | 1.7 V × 1.21 A = 2.06 W
5 V | 800 mA | 直供，0 W
12 V | 333 mA | 需升压，5 V 输入做不到

数据取自 CTS 196（36 × 27 mm）

预热 4 W、稳态 1.5 W @25 °C，
预热 4 min 到 50 ppb 以内

图 4 同一颗 OCXO 在不同供电电压下的电流

恒温槽维持晶体温度需要的是功率，这个功率由物理决定，与供电电压无关。所以换电压只改变电流：

供电 | 预热电流（4 W） | 稳态电流（1.5 W） | 从 5 V 输入做这一轨
3.3 V | 1212 mA | 455 mA | LDO 损耗 1.7 V × 1.21 A = 2.06 W，太热
5 V | 800 mA | 300 mA | 直供或小压差稳压，0 ~ 0.4 W
12 V | 333 mA | 125 mA | 5 V 输入做不到，需升压

三条结论：

一、5 V 是甜点。 电流适中，可以直接从 5 V 输入供电，也可以把输入抬到 5.4 V 后用超低压差 LDO 稳出 5.0 V，损耗只有 0.4 W。

二、3.3 V 版本对线性供电不友好。 同样的热量要用 1.5 倍的电流搬运，从 5 V 降下来的 LDO 损耗超过 2 W——只能上 DC-DC，或者选功率更小的型号。

三、12 V 版本电流最小、走线压降最小，是高性能 OCXO 的常见选择，但需要 12 V 输入。 如果你的板子固定 5 V 输入，这一档就被排除了——这是定输入电压时就要想清楚的边界。

## 8. 选型建议

对本项目（10 MHz 频率基准、5 V 外部输入、追求小型化）：

优先级 | 建议
尺寸 | 25.4 × 25.4 mm 起步，选择面最广、性能与体积平衡最好
供电 | 优先 5 V 版本，避开 3.3 V 的电流放大和 12 V 的输入限制
引脚 | 定型后把型号写进符号和封装的注释，禁止"同尺寸随便换"
兼容 | 除非确有需要，不做多尺寸兼容焊盘——密度和地平面的代价不划算
功耗 | 按预热 4 W / 稳态 1.5 W 这一档做电源和热设计，选定型号后用实测值修正

如果后续要把板子做得更小，14 × 9 SMD 是下一个合理的台阶，再往下性能损失开始明显。

CLOCK 项目 · 硬件设计文档 | 第 6 页

## 9. 数据来源

- 平台尺寸清单：Microchip（Vectron）OCXO Evaluation Board 说明，明确列出 13 × 20（4 脚 DIP）、20 × 20（0.8 × 0.8 in）、25 × 25（1 × 1 in）、25 × 37（Eurocase）、50 × 50（2 × 2
in）五种工业标准平台
- 36 × 27 mm 的机械与电气数据：CTS Model 196 数据手册 Rev C，第 1、2、4 页
- SMD 尺寸档位：Abracon、Kyocera-AVX 的 OCXO 产品线，最小到 7 × 5 mm
- 25.4 mm 的焊盘与引脚：本项目封装库 JLCImport:DOPFITKR2-10M（外形 25.40 × 25.40、焊盘位于

±9.52）与符号 Counter:OCXO-10M

图 4 的电流值按 CTS 196 的 4 W / 1.5 W
换算得到，用于说明电压与电流的反比关系；实际选型后须以该型号手册的电流规格为准。

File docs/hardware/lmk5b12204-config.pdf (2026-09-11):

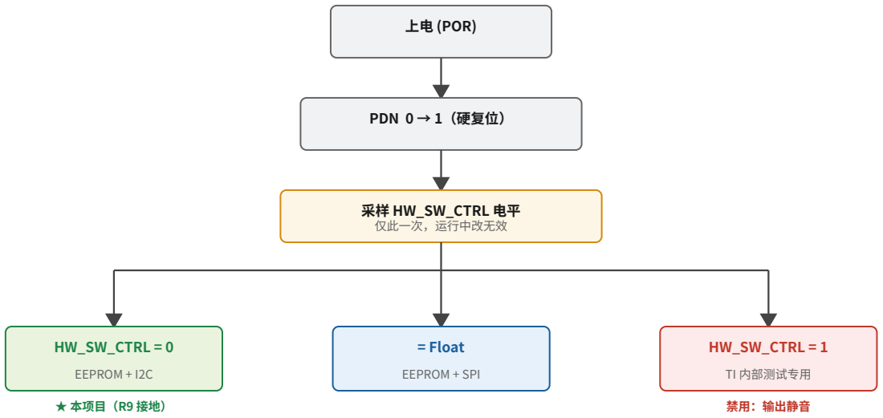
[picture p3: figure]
上电 (POR); PDN 0 → 1（硬复位）; 采样 HW_SW_CTRL 电平 仅此一次，运行中改无效; HW_SW_CTRL = 0; EEPROM + I2C; ★ 本项目（R9 接地）; = Float; EEPROM + SPI; HW_SW_CTRL = 1; TI 内部测试专用; 禁用：输出静音

CLOCK 项目 · 硬件设计文档 | 第 1 页

# LMK5B12204 配置指南

CLOCK 项目 · LMK5B12204 配置

本文说明 LMK5B12204 的启动模式、寄存器与 EEPROM 的关系、以及上电时序上的一条硬约束。适用于本项目 U1 + U8（STM32F103）的组合。

摘要

一、配置写入 EEPROM 后，每次上电自动加载，不需要外部干预。 本项目 HW_SW_CTRL 经 R9（0 Ω）接地，工作在 EEPROM + I2C 模式。

二、EEPROM 只能烧 100 次。 手册推荐工作条件中 nEEcyc = 100 cycles。调试阶段应当走 MCU 写寄存器的路径，不消耗这个配额。

三、VCO 校准要求外部 XO 在校准开始前就已稳定，否则 PLL 和所有输出都起不来。 OCXO 冷启动需要数分钟，因此必须用 PDN 把器件启动推迟到 OCXO 预热完成之后。这一条最容易被忽略，也最容易表现为"板子有时能起、有时不能起"。

## 1. 启动模式

寄存器从 EEPROM 初始化，串口激活

此后可通过 I2C/SPI 读写寄存器，也可烧录 EEPROM

图 1 POR 配置序列与三种启动模式

HW_SW_CTRL（引脚 9）是三电平输入，只在上电复位那一刻被采样，之后改变电平无效。手册 Table 8-11 给出三种模式：

CLOCK 项目 · 硬件设计文档 | 第 2 页
HW_SW_CTR L | 模式 | 说明
0（接地） | EEPROM + I2C | 寄存器从 EEPROM 初始化，I2C 使能。GPIO1 选 I2C 地址低两位
Float | EEPROM + SPI | 寄存器从 EEPROM 初始化，SPI 使能
1（接高） | TI 内部测试专用 | 输出静音，禁止在产品中使用

第三行值得单独强调：接高不是"另一种可用模式"，而是会让所有输出静音的测试状态。 这个引脚不能悬空不管，也不能随手上拉。

本项目的接法是 U1 pin9 ── R9 (0 Ω) ── GND，对应 EEPROM + I2C 模式，与 SDA/SCL 上的 4.7 kΩ 上拉（R1/R2）一致，配置正确。

POR 之后的顺序是：采样 HW_SW_CTRL → 从 EEPROM 初始化寄存器 → 串口激活 → 此后可读写寄存器、也可烧录 EEPROM。控制与状态引脚只在硬复位后才激活。

## 2. 出厂默认配置与本项目需求的差距

通用型号出厂时 EEPROM 里已有一份默认配置（手册 Table 8-13），但它和本项目完全对不上：

项目 | 出厂默认 | 本项目
XO | 48.0048 MHz，AC-DIFF | 10 MHz OCXO
PRIREF / SECREF | 均 25 MHz | 待定
OUT0 / OUT1 / OUT2 | 156.25 MHz | 312.5 MHz ~ 1 GHz
OUT3 | 25 MHz | 同上
全部输出使能 | Disabled | 需全部启用
DPLL 环路带宽 | 100 Hz | 按 OCXO 保持需求设定
APLL2 | Disabled | 视输出分配而定

四路输出出厂默认全是关闭的。 新芯片焊上去直接上电不会有任何输出——这是正常现象，不是坏件。

## 3. 两条配置路径

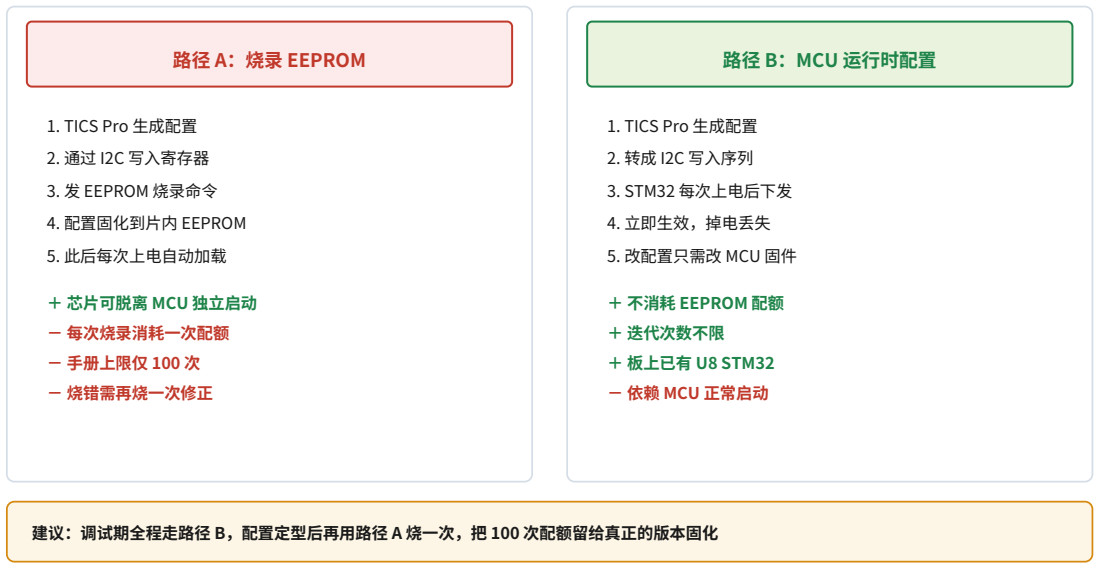
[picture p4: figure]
路径 A：烧录 EEPROM; 1. TICS Pro 生成配置; 2. 通过 I2C 写入寄存器; 3. 发 EEPROM 烧录命令; 4. 配置固化到片内 EEPROM; 5. 此后每次上电自动加载; ＋ 芯片可脱离 MCU 独立启动; － 每次烧录消耗一次配额; － 手册上限仅 100 次; － 烧错需再烧一次修正; 路径 B：MCU 运行时配置; 2. 转成 I2C 写入序列; 3. STM32 每次上电后下发; 4. 立即生效，掉电丢失; 5. 改配置只需改 MCU 固件; ＋ 不消耗 EEPROM 配额; ＋ 迭代次数不限; ＋ 板上已有 U8 STM32; － 依赖 MCU 正常启动

CLOCK 项目 · 硬件设计文档 | 第 3 页

建议：调试期全程走路径 B，配置定型后再用路径 A 烧一次，把 100 次配额留给真正的版本固化

图 2 烧录 EEPROM 与 MCU 运行时配置的取舍

路径 A（烧 EEPROM）：TICS Pro 生成配置 → I2C 写入寄存器 → 发烧录命令 → 固化。此后芯片可脱离 MCU 独立启动。代价是每烧一次消耗一次配额，而配额只有 100 次。

路径 B（MCU 运行时配置）：TICS Pro 生成配置 → 转成 I2C 写入序列 → STM32 每次上电后下发。手册明确写 着启动后寄存器可通过串口访问用于监控和编程，写进去立即生效、掉电丢失、不消耗 EEPROM 配额。改配置只需改 MCU 固件。

建议：调试期全程走路径 B，配置定型后再用路径 A 烧一次。 板上已经有 U8（STM32F103CBTx）通过 I2C 连到 U1，这条路径不需要额外硬件。两条路径用的是同一份 TICS Pro 配置数据，切换成本很低。

如果一开始就靠烧 EEPROM 迭代，100 次配额很容易在调通之前耗尽——而这颗芯片不便宜。

## 4. 上电时序：VCO 校准的硬约束

VDD 3.3 V
上电即有效

OCXO 输出
冷启动数分钟才稳定

PDN（STM32 控制）
等 XO 稳定后再拉高

寄存器配置
EEPROM 加载或 MCU 下发

VCO 校准
★ 此刻 XO 必须已稳定

输出时钟
APLL 锁定 1~2.5 ms

OCXO 稳定点

时间 →

VCO 校准若在 XO 稳定之前启动会失败，PLL 与所有输出都起不来——必须用 PDN 把启动推迟到 OCXO 预热完成之后

CLOCK 项目 · 硬件设计文档 | 第 4 页

图 3 OCXO 预热与器件启动的时序关系

手册第 8.4.1.2 节写得很直白：

正确的 VCO 校准要求外部 XO 时钟在校准开始之前，其幅度和频率都已稳定。否则 VCO 校准会失败，导致 PLL 和输出时钟无法启动。

把这句话和 OCXO 的特性放在一起看，问题就出来了：OCXO 冷启动需要数分钟才能稳定，而 VDD 一上电、PDN 一释放，LMK5B12204 立刻就会开始配置和 VCO 校准。两者的时间尺度差了几个数量级。

后果不是"精度差一点"，而是PLL 根本锁不上、四路输出全无。而且这种故障有随机性——环境温度高的时候 OCXO 稳定得快，可能就起来了；冷机开机就起不来。这类"有时好有时坏"的现象最难查。

解决办法：用 PDN 引脚推迟启动。 PDN（引脚 13）拉低时器件处于硬复位、所有模块断电；拉高后才按 HW_SW_CTRL 选定的模式启动。本项目的 PDN 已经接到 U8 的 GPIO 和 J13 调试口，STM32 完全可以控制。

## 5. 推荐的 STM32 启动流程

1. 上电，STM32 把 PDN 拉低并保持
2. 等待 OCXO 预热
- 若 OCXO 有 ready / lock 输出，用它触发
- 否则按其手册的 warm-up time 延时（通常 ≥30 s，保守取 3 min）
3. PDN 拉高，器件开始启动
4. 器件从 EEPROM 加载配置（或由 STM32 通过 I2C 下发完整配置）
5. 等待 APLL 锁定：APLL1 约 1.0 ms、APLL2 约 2.5 ms
6. 读 STATUS 引脚或状态寄存器确认无 LOL
7. 使能输出

第 2 步的等待时间是这套流程里唯一需要按实际 OCXO 型号确定的参数。如果所选 OCXO 带 ready 信号，优先用它——比固定延时可靠得多，也不用为了保险而无谓地拖长开机时间。

板上 D1、D2 两颗 LED 接在 STATUS0/STATUS1 上，可以配置成 LOL 指示，调试时一眼就能看出锁没锁上。

## 6. 检查清单

项目 | 要求
HW_SW_CTRL | 接地（EEPROM + I2C）；绝不可接高
SDA / SCL | 4.7 kΩ 上拉至 3.3 V（R1/R2 已有）
PDN | 由 STM32 控制，上电先拉低
OCXO 预热 | 等待稳定后再释放 PDN
调试期配置 | 走 MCU 写寄存器，不烧 EEPROM
EEPROM 烧录 | 配置定型后一次完成，注意 100 次上限
输出使能 | 出厂默认全关，配置里需显式启用
STATUS0/1 | 配置为 LOL 指示，接 D1/D2

## 7. 数据来源

均取自 LMK5B12204 数据手册 SNAS810C（2026 年 5 月修订版）：

CLOCK 项目 · 硬件设计文档 | 第 5 页
- 第 5 节 Pin Functions：HW_SW_CTRL、PDN 引脚定义
- 第 6.3 节 Recommended Operating Conditions：nEEcyc = 100 cycles
- 第 8.4.1 节 Figure 8-31：Device POR Configuration Sequence
- 第 8.4.1.2 节：PLL Start-Up Sequence 与 VCO 校准对 XO 的要求
- 第 8.5.9 节 Table 8-13：EEPROM 出厂默认配置
- Table 8-11：HW_SW_CTRL 启动模式定义

OCXO 的预热时间需按最终选型的型号手册确定。

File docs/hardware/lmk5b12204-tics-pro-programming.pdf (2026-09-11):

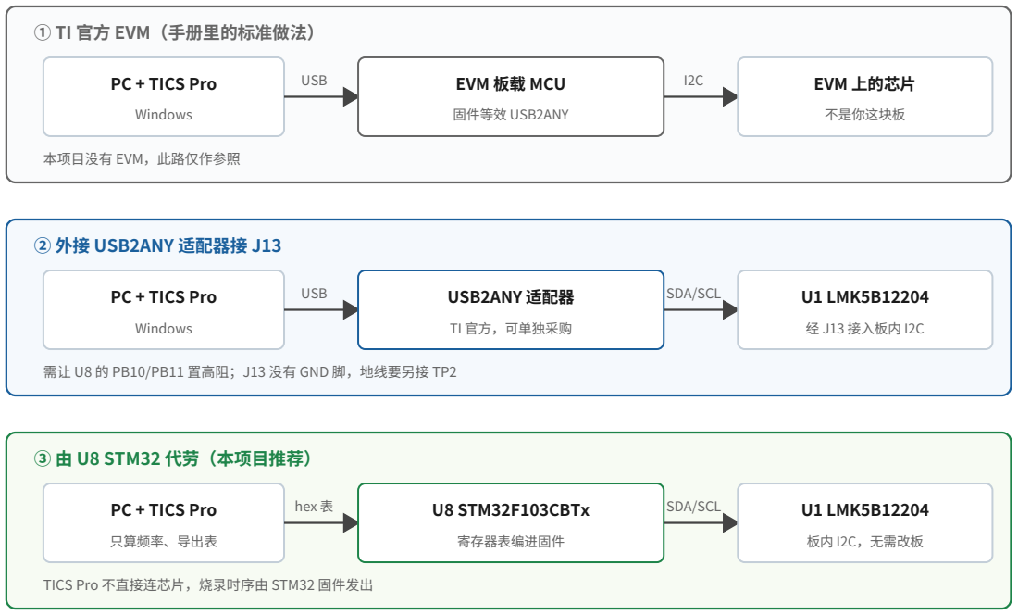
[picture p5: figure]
① TI 官方 EVM（手册里的标准做法）; PC + TICS Pro; Windows; USB; EVM 板载 MCU; 固件等效 USB2ANY; EVM 上的芯片; 不是你这块板; 本项目没有 EVM，此路仅作参照; ② 外接 USB2ANY 适配器接 J13; USB2ANY 适配器; TI 官方，可单独采购; SDA/SCL; U1 LMK5B12204; 经 J13 接入板内 I2C; ③ 由 U8 STM32 代劳（本项目推荐）; 只算频率、导出表; hex 表; U8 STM32F103CBTx; 寄存器表编进固件; 板内 I2C，无需改板; TICS Pro 不直接连芯片，烧录时序由 STM32 固件发出

CLOCK 项目 · 硬件设计文档 | 第 1 页

# LMK5B12204 TICS Pro 烧录指南

CLOCK 项目 · TICS Pro 烧录指南

本文说明如何用 TI 的 TICS Pro 生成 LMK5B12204 的配置，以及如何把这份配置写进片内寄存器和 EEPROM。寄存器级的时序全部取自数据手册第 9.5 节与《LMK5B12204 Register Maps》（SNAU256），这部分是权威且不随软件版本变化的；TICS Pro 的菜单名称随版本有差异，以实际界面为准。

摘要

一、TICS Pro 本身不能直接烧你这块板。 它的通信通道是 USB2ANY（EVM 上是板载 MCU 跑的等效固件）。本项目没有 EVM，要么外接一个 USB2ANY 适配器到 J13，要么让 TICS Pro 只负责算频率、导出寄存器表，由板上的 U8（STM32F103CBTx）发 I2C 完成实际写入。推荐后者——不用买硬件，也不用改板。

二、烧录 EEPROM 的核心只有四条寄存器写。 依次是 R157 = 40h（把活动寄存器提交到 SRAM）、R164 = EAh（解锁）、R157 = 03h（擦除并烧写）、然后等约 230 ms。其中第二、三条必须紧邻，中间不能插入任何其他寄存器事务，否则擦写命令根本不会执行。

三、写寄存器时有三个字节必须跳过。 R12、R157、R164 带掩码，R353~R435 是 TI 内部测试寄存器，一律不要碰。把导出的寄存器表原封不动地从 R0 刷到 R435，是最容易踩的坑。

四、本板有两处需要留意：J13 没有 GND 引脚，GPIO1 没有上下拉。 前者影响外接适配器时的地线，后者影响上电时采样到的 I2C 从机地址。详见第 6 节。

## 1. 硬件通路：配置怎么进到芯片里

需让 U8 的 PB10/PB11 置高阻；J13 没有 GND 脚，地线要另接 TP2

图 1 三条把配置送进 LMK5B12204 的通路

CLOCK 项目 · 硬件设计文档 | 第 2 页

TICS Pro 是一个 EVM GUI 框架，它和器件之间的物理通道只有一条：USB2ANY。EVM 上那颗"板载 MCU"跑的就是 USB2ANY 固件，所以在 GUI 看来两者没有区别。理解这一点，三条通路的差别就清楚了：

通路 ①（TI 官方 EVM） 是手册和 EVM 用户指南默认的做法。本项目没有 EVM，此路仅作参照。

通路 ②（外接 USB2ANY 接 J13） 让 TICS Pro 真正在线操作你的芯片：GUI 里改一个参数就立刻写进器件，调试体验最好。J13 是 1×6 排针座，引脚定义为 SDA / SCL / PDN / GPIO0 / GPIO1 / GPIO2，I2C 和复位控制都齐了。两个前提：U8 的 PB10/PB11 必须配置成高阻输入（否则两个主机抢总线），地线要另外从 TP2 引过来（J13 上没有 GND 脚）。

通路 ③（U8 STM32 代劳） 是本项目推荐的做法。TICS Pro
退化成一个纯粹的"频率规划计算器"：算完配置，导出 R0~Rn 的十六进制表，把这张表编进 STM32 固件，由 STM32 通过板内 I2C 写进
U1。不用买适配器、不用改板、不用担心总线争用，缺点是每改一次配置要重新编译烧录 MCU 固件。

## 2. TICS Pro 操作流程

1

安装 TICS Pro

ti.com 搜索 TICSPRO-SW 申请下载；依赖 .NET Framework 4.5 与 IronPython 2.7

2

选择器件

菜单 Select Device → 时钟发生器分组 → LMK5B12204；列表里没有时用 Import User Device 导入 zip

3

填写频率规划

EVM Quick Start 页按引导走，或 Wizard 页新建设计：XO = 10 MHz OCXO、参考输入、OUT0~OUT3 频率与格式

4

核对寄存器

Raw Registers 页可逐条查看 R0 ~ R352 的最终取值，与第 3 节的写入范围对照

5

连接硬件（有适配器时）

USB Communications → Interface 选 I2C，用 Identify 确认连上；无硬件时 GUI 停在 Simulation 模式

6

写入器件

USB Communications → Program All Register，等同 Raw Registers 页的 Write All

7

导出配置数据

File → Export Hex Register Values 得 R0~Rn 十六进制表；EEPROM 页 Export GUI Map 得 SRAM/EEPROM 映射

8

保存工程

File → Save 存下设置文件留档，需要时可发给 TI 复核或申请工厂预编程样片

图 2 从安装到导出配置的八步

几处容易卡住的地方：

器件列表里找不到 LMK5B12204。 TICS Pro 支持 Select Device → Import User Device，导入 TI 提供的器件 zip 包即可。较老的版本可能完全不支持这颗芯片，需要升级——EEPROM/SRAM 映射的生成能力也是在较新版本里才补齐的，如果 EEPROM 页没有导出选项，先确认版本。

Simulation 模式。 没接硬件时 GUI 仍可正常使用，所有计算和导出功能都在，只是写不进器件。通路 ③ 全程就工作在这个模式下。

AutoUpdate 选项。 打开时，界面上任何改动会立刻写进器件；关闭时改动只留在 GUI 里，需要显式 Write All。在线调试时建议先关掉，改完一组参数再整体写入，避免中间态让 PLL 反复失锁。

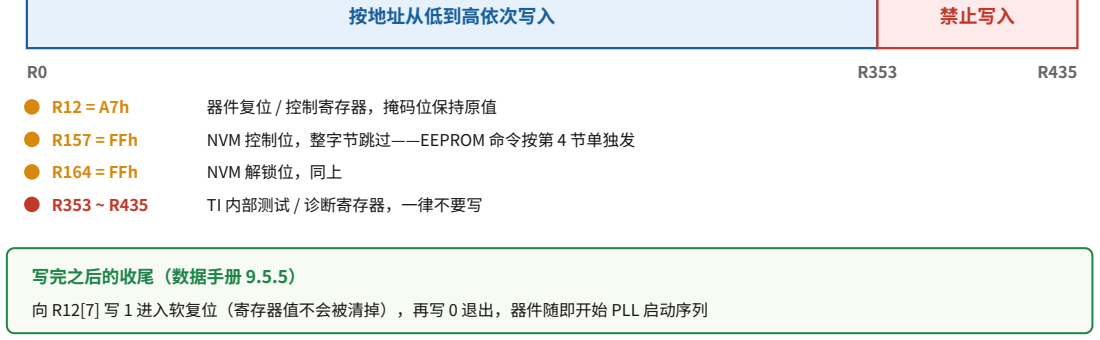
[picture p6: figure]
按地址从低到高依次写入; 禁止写入; 器件复位 / 控制寄存器，掩码位保持原值; R157 = FFh; NVM 控制位，整字节跳过——EEPROM 命令按第 4 节单独发; R164 = FFh; NVM 解锁位，同上; TI 内部测试 / 诊断寄存器，一律不要写; 写完之后的收尾（数据手册 9.5.5）

CLOCK 项目 · 硬件设计文档 | 第 3 页

导出的两种数据不是一回事。 Export Hex Register Values
导出的是活动寄存器表（R0~Rn），用于运行时配置；EEPROM 页的 Export GUI Map 导出的是 SRAM/EEPROM 映射（第 0~252 字节），只有走第 4 节的"方法 #2 直接写
SRAM"时才用得上。绝大多数情况下，你需要的是前者。

## 3. 把配置写进活动寄存器

R12 掩码 A7h | R157 / R164 掩码 FFh

向 R12[7] 写 1 进入软复位（寄存器值不会被清掉），再写 0 退出，器件随即开始 PLL 启动序列

图 3 寄存器写入范围、掩码与收尾动作

手册 9.5.5 节给出的通用主机编程序列：

1. 上电，PDN 已拉高，器件进入 I2C 模式
2. 从低地址到高地址依次写 R0 ~ R352，跳过掩码位
3. 向 R12[7] 写 1，进入软复位（寄存器值不会被清掉）
4. 向 R12[7] 写 0，退出软复位，器件开始 PLL 启动序列
5. 如需开机自启动，再按第 4 节烧 EEPROM

掩码的含义是"这些位保持原值，不要用导出表里的值覆盖"：

地址 | 掩码 | 为什么
R12 | A7h | 器件复位/控制寄存器，软复位要在第 3、4 步单独操作
R157 | FFh | NVM 控制位，整字节跳过——EEPROM 命令必须按第 4 节的时序单独发
R164 | FFh | NVM 解锁位，同上
R353 ~ R435 | FFh | TI 内部测试/诊断寄存器，一律不要写

R157 尤其要注意：它同时含 REGCOMMIT、NVMERASE、NVMPROG 三个自清位。如果批量写寄存器时把它一 起刷了，轻则什么都不发生，重则在你没打算烧录的时候触发一次擦写，白白消耗 100 次配额里的一次。

这一步写完，配置就已经生效了。 掉电会丢，但足以完成全部功能验证。建议先在这个状态下把四路输出、PLL 锁定、相噪抖动全部测完，确认配置无误再考虑烧 EEPROM。

## 4. 烧录 EEPROM

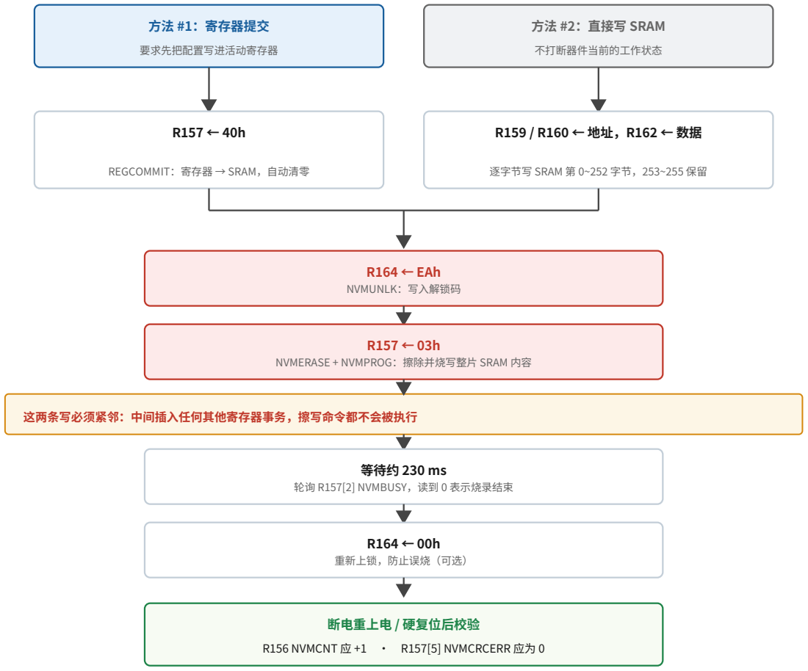
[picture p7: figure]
方法 #1：寄存器提交; 要求先把配置写进活动寄存器; 方法 #2：直接写 SRAM; 不打断器件当前的工作状态; REGCOMMIT：寄存器 → SRAM，自动清零; 逐字节写 SRAM 第 0~252 字节，253~255 保留; R164 ← EAh; NVMUNLK：写入解锁码; NVMERASE + NVMPROG：擦除并烧写整片 SRAM 内容; 这两条写必须紧邻：中间插入任何其他寄存器事务，擦写命令都不会被执行; 等待约 230 ms; 轮询 R157[2] NVMBUSY，读到 0 表示烧录结束; 重新上锁，防止误烧（可选）; 断电重上电 / 硬复位后校验

CLOCK 项目 · 硬件设计文档 | 第 4 页

R156 NVMCNT 应 +1 · R157[5] NVMCRCERR 应为 0

图 4 EEPROM 烧录的寄存器级操作顺序

EEPROM 不能直接写，它是从片内 SRAM 阵列整片烧过去的。所以烧录分两段：先把配置送进 SRAM，再发擦写命令。送进 SRAM 有两种方法。

### 4.1 方法 #1：寄存器提交（推荐）

前提是活动寄存器已按第 3 节配置好。然后只需一条写：

R157 ← 40h | # REGCOMMIT，把当前寄存器内容提交到 SRAM，该位自动清零

优点是不需要知道 SRAM/EEPROM 映射长什么样，导出一份寄存器表就够了。缺点是提交的内容就是器件当前 的工作配置，没法在不打断运行的前提下烧另一份配置。

### 4.2 方法 #2：直接写 SRAM

绕过活动寄存器，器件继续正常输出时钟的同时把另一份配置写进 SRAM：

R159 ← SRAM 地址高 5 位
R160 ← SRAM 地址低 8 位
R162 ← 数据字节 | # 同一次事务内连续写会自动地址递增

只需要写第 0~252 字节，253~255 是 TI 保留字节，不得改写。这条路径需要 EEPROM 页导出的 SRAM/EEPROM 映射文件。

用户可编程字段也在这一步顺带写入：字节 5 是 I2C 从机地址高 5 位（默认 C8h，对应 7 位地址 0x64），字节 11 是 EEPROM 镜像版本号 EEREV，字节 249~252
是四个备用字节，可以写产品序列号之类的追溯信息。这几个字节只能用方法 #2 写。

CLOCK 项目 · 硬件设计文档 | 第 5 页

### 4.3 发擦写命令

两种方法殊途同归，SRAM 准备好之后：

R164 ← EAh | # NVMUNLK 解锁码
R157 ← 03h | # NVMERASE + NVMPROG，整片擦除并烧写
| # 等待约 230 ms，轮询 R157[2] NVMBUSY 直到读回 0
R164 ← 00h | # 重新上锁（可选，防误烧）

R164 ← EAh 和 R157 ← 03h 必须是紧邻的两次寄存器事务。 手册原文是"Steps 1 and 2 must be atomic writes without any other register transactions in-between"。中间只要插进去任何一次读或写——包括一次状态轮询 、一次调试打印触发的寄存器读——解锁就失效，擦写命令被静默忽略，而且没有任何报错。这是这套流程里最 隐蔽的失败点。

擦除 115 ms、编程 115 ms，合计约 230 ms。这段时间内绝对不能断电，否则 EEPROM 内容不完整，下次上电 CRC 校验失败。

### 4.4 校验

烧录完成后必须断电重上电或硬复位，然后读两个寄存器：

寄存器 | 期望值 | 含义
R156 NVMCNT | 比烧录前 +1 | 累计烧录次数，上限 100 次
R157[5] NVMCRCERR | 0 | 为 1 表示 EEPROM 数据 CRC 不匹配，配置无效
R11 EEREV | 你写入的版本号 | 仅方法 #2 写过时有意义

NVMCNT 出厂就是非零的（工厂预编程消耗了若干次），所以第一次上电就该把它读出来记下，之后每烧一次核 对一次增量。100 次配额没有任何办法恢复。

CRC 机制值得解释一下：烧录时器件自动算一个 CRC 存进 EEPROM（NVMSCRC，R155）；每次上电从 EEPROM 读回数据时再实时算一遍（NVMLCRC，R158）。两者不匹配就置 NVMCRCERR，并且在寄存器加载后就停住，不继续 PLL 锁定流程。所以一块烧坏了 EEPROM 的板子表现是"没有任何输出"，而不是"输出频率不对"。

## 5. 用 U8 STM32 完成烧录

通路 ③ 的完整顺序，以及和第 3、4 节的对应关系：

1. STM32 上电，先把 PB15(PDN) 驱动为低，PB13(GPIO1) 驱动为低
2. 等待 OCXO 预热稳定（见《LMK5B12204 配置指南》第 4 节）
3. PB15 拉高，U1 开始 POR，采样 HW_SW_CTRL=0 与 GPIO1=0
4. I2C 从机地址 = 0x64，按第 3 节写 R0 ~ R352（跳过 R12/R157/R164）
5. R12[7] 写 1 再写 0，触发 PLL 启动
6. 读状态寄存器确认 APLL 已锁定、无 LOL
7. —— 以上是每次上电都做的事，到此为止就能正常工作 ——
8. 只在需要固化配置时：R157←40h，R164←EAh，R157←03h，轮询 NVMBUSY
9. 复位后读 NVMCNT 与 NVMCRCERR 校验

第 8 步应当做成一条需要显式触发的调试命令（通过 J16 的串口发一条指令，或按住某个条件上电），绝不能放在正常启动流程里。否则每次上电烧一次，100 次配额一周就没了。

I2C 写事务本身是标准的：从机地址 0x64（7 位）+ 16 位寄存器地址 + 数据字节。第 4.3 节那两条相邻写，在 STM32 固件里要写成两次独立的 HAL_I2C_Mem_Write，中间不插任何别的 I2C 操作——不要在中间加日志打印，如果打印函数里有读寄存器的动作就会破坏原子性。

CLOCK 项目 · 硬件设计文档 | 第 6 页
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

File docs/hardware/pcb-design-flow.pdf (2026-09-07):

CLOCK 项目 · 硬件设计文档 | 第 1 页

# CLOCK PCB 设计流程

CLOCK 项目 · 硬件设计文档 · v1.0

本文按时间顺序给出 CLOCK 板从原理图收尾到 Gerber 出厂的完整操作流程，说明每个阶段做什么、依据是什么、以及做完怎么验证。

与 pcb-layout.md 的分工： 那篇讲设计成什么样（叠层参数、分区结论、阻抗数值），本篇讲按什么顺序做。 遇到具体数值请回查那篇，本文只在流程需要时引用结论。

原理图结构： 工程已从单页平坦图拆成层次结构——顶层 CLOCK.kicad_sch 挂两张子图：CLOCK_GEN.kicad_sch（OCXO、LMK5B12204、时钟分配与电源，141 个器件）和 MAIN_CTRL.kicad_sch（STM32F103CBT6 主控，12 个器件）。这次拆分改变了元件的层次路径，直接影响阶段四的操作方式，见第 5 节。
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

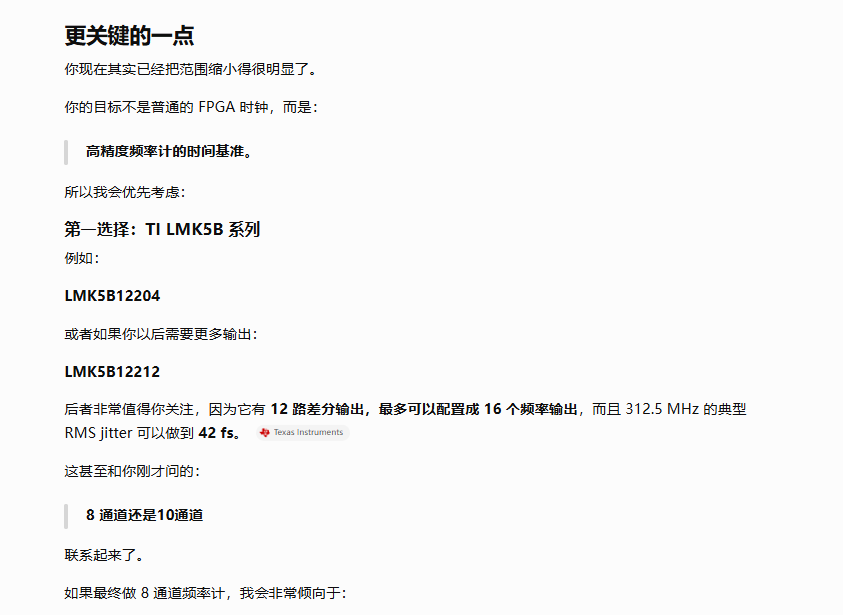
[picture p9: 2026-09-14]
docs/references/时钟产生芯片/LMK系列抖动更强.png

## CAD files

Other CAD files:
tools/LC_3D_Module_Download-master/step/ANT-SMD_KH-IPEX-K501-29.step

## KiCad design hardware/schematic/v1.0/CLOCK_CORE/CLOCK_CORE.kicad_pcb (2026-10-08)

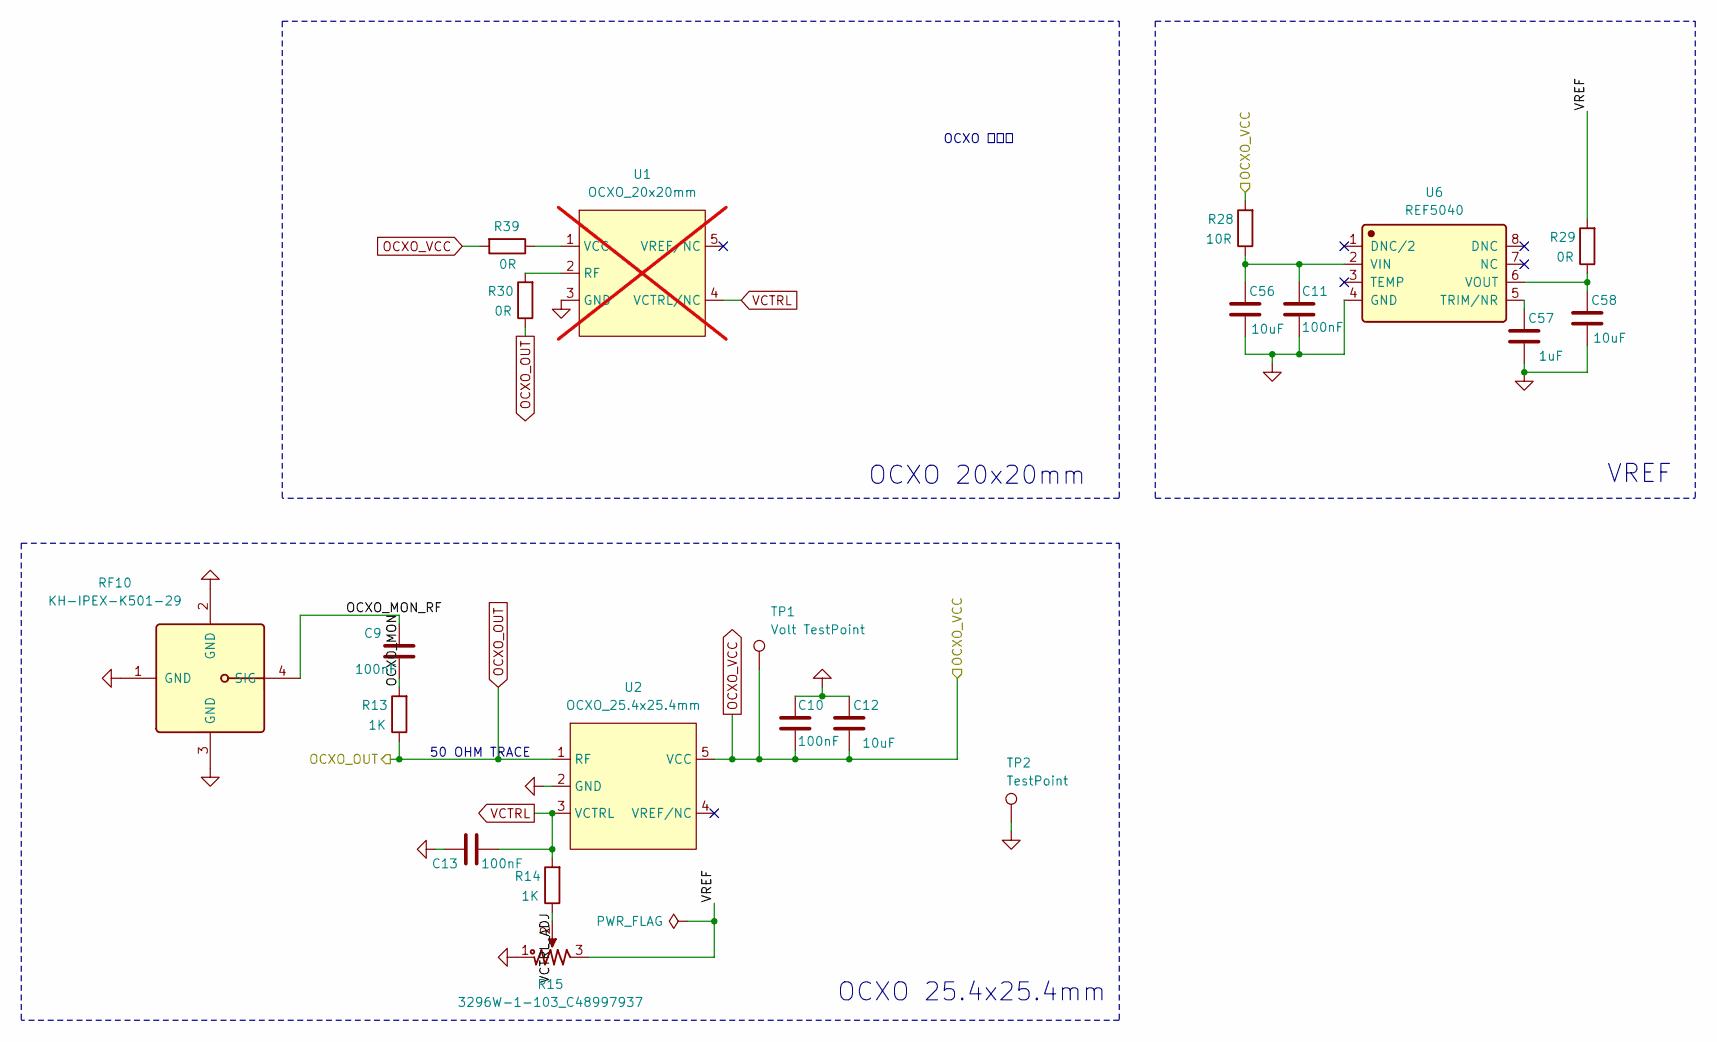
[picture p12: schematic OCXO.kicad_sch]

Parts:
C9, C10, C11, C13: 100nF; C_0402_1005Metric
C12, C56, C58: 10uF; C_0603_1608Metric
C57: 1uF; C_0603_1608Metric
R13, R14: 1K; R_0402_1005Metric
R15: 3296W-1-103_C48997937; Manufacturer Part 3296W-1-103; LCSC C48997937
R28: 10R; R_0603_1608Metric
R29: 0R; R_0603_1608Metric
R30: 0R; R_0402_1005Metric
R39: 0R; R_0805_2012Metric
RF10: KH-IPEX-K501-29; Manufacturer Part KH-IPEX-K501-29; LCSC C411563
TP1: Volt TestPoint; TestPoint_Pad_D1.0mm
TP2: TestPoint; TestPoint_Pad_D1.0mm
U1: OCXO_20x20mm; not fitted
U2: OCXO_25.4x25.4mm; DOPFITKR2-10M
U6: REF5040; Manufacturer Part REF5040AIDR; LCSC C46274

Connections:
/OCXO/OCXO_MON: C9.2, R13.2
/OCXO/OCXO_MON_RF: C9.1, RF10.4 (SIG)
/OCXO/VCTRL_ADJ: R14.1, R15.2
/OCXO/VREF: R15.3, R29.2
GND: C10.2, C11.1, C12.1, C13.2, C56.2, C57.2, C58.2, R15.1, RF10.1 (GND), RF10.2 (GND), RF10.3 (GND), TP2.1 (1_1), U1.3 (GND), U2.2 (GND), U6.4 (GND); also elsewhere on the board
unnamed: R30.2, U1.2 (RF)
unnamed: R39.1, U1.1 (VCC)
unnamed: C57.1, U6.5 (TRIM/NR)
unnamed: C11.2, C56.1, R28.1, U6.2 (VIN)
unnamed: C58.1, R29.1, U6.6 (VOUT)
OCXO_OUT: R13.1, R30.1, U2.1 (RF); also elsewhere on the board
OCXO_VCC: C10.1, C12.2, R28.2, R39.2, TP1.1 (1_1), U2.5 (VCC); also elsewhere on the board
VCTRL: C13.1, R14.2, U1.4 (VCTRL/NC), U2.3 (VCTRL)

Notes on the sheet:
OCXO 20x20mm
VREF
OCXO 二选一
OCXO 25.4x25.4mm
50 OHM TRACE

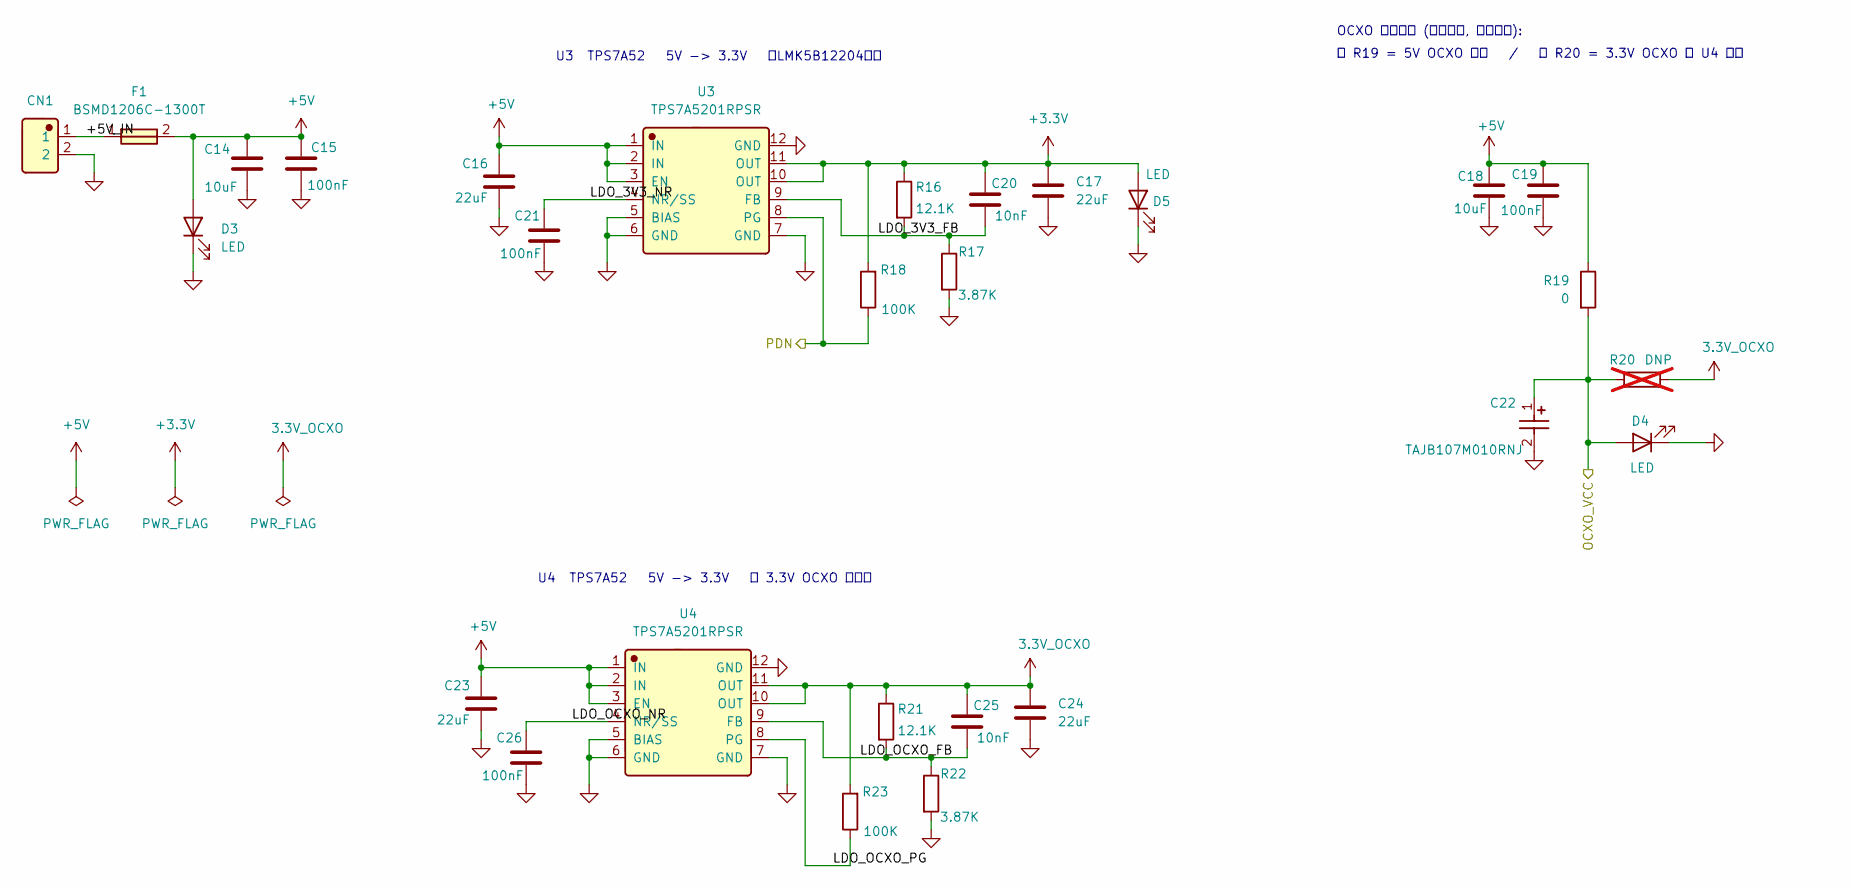
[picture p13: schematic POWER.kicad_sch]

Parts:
C14, C18: 10uF; C_0603_1608Metric
C15, C19, C21, C26: 100nF; C_0402_1005Metric
C16, C17, C23, C24: 22uF; C_0805_2012Metric
C20, C25: 10nF; C_0402_1005Metric
C22: TAJB107M010RNJ; Manufacturer Part TAJB107M010RNJ; LCSC C7196
CN1: LAIL-PHC2_54-2P-01-XH-L; Manufacturer Part LAIL-PHC2.54-2P-01-XH-L; LCSC C54905973
D3, D4, D5: LED; LED_0603_1608Metric
F1: BSMD1206C-1300T; Manufacturer Part BSMD1206C-1300T; LCSC C41367225
R16, R21: 12.1K; R_0402_1005Metric
R17, R22: 3.87K; R_0402_1005Metric
R18, R23: 100K; R_0402_1005Metric
R19: 0; R_0805_2012Metric
R20: DNP; R_0805_2012Metric; not fitted
U3, U4: TPS7A5201RPSR; Manufacturer Part TPS7A5201RPSR; LCSC C2876777

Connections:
/LMK5B12204/PDN: R18.1, U3.8 (PG); also elsewhere on the board
/POWER/+5V_IN: CN1.1, F1.1
/POWER/LDO_3V3_FB: C20.2, R16.2, R17.1, U3.9 (FB)
/POWER/LDO_3V3_NR: C21.1, U3.4 (NR/SS)
/POWER/LDO_OCXO_FB: C25.2, R21.2, R22.1, U4.9 (FB)
/POWER/LDO_OCXO_NR: C26.1, U4.4 (NR/SS)
/POWER/LDO_OCXO_PG: R23.1, U4.8 (PG)
GND: C14.2, C15.2, C16.2, C17.2, C18.2, C19.2, C21.2, C22.2, C23.2, C24.2, C26.2, CN1.2, D3.1 (K), D4.1 (K), D5.1 (K), R17.2, R22.2, U3.5 (BIAS), U3.6 (GND), U3.7 (GND), U3.12 (GND), U4.5 (BIAS), U4.6 (GND), U4.7 (GND), U4.12 (GND); also elsewhere on the board
OCXO_VCC: C22.1, D4.2 (A), R19.2, R20.1; also elsewhere on the board

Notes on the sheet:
U3 TPS7A52 5V -> 3.3V 给LMK5B12204供电
OCXO 供电选配 (二者互斥, 严禁同装):
装 R19 = 5V OCXO 直供 / 装 R20 = 3.3V OCXO 经 U4 稳压
U4 TPS7A52 5V -> 3.3V 仅 3.3V OCXO 时装配

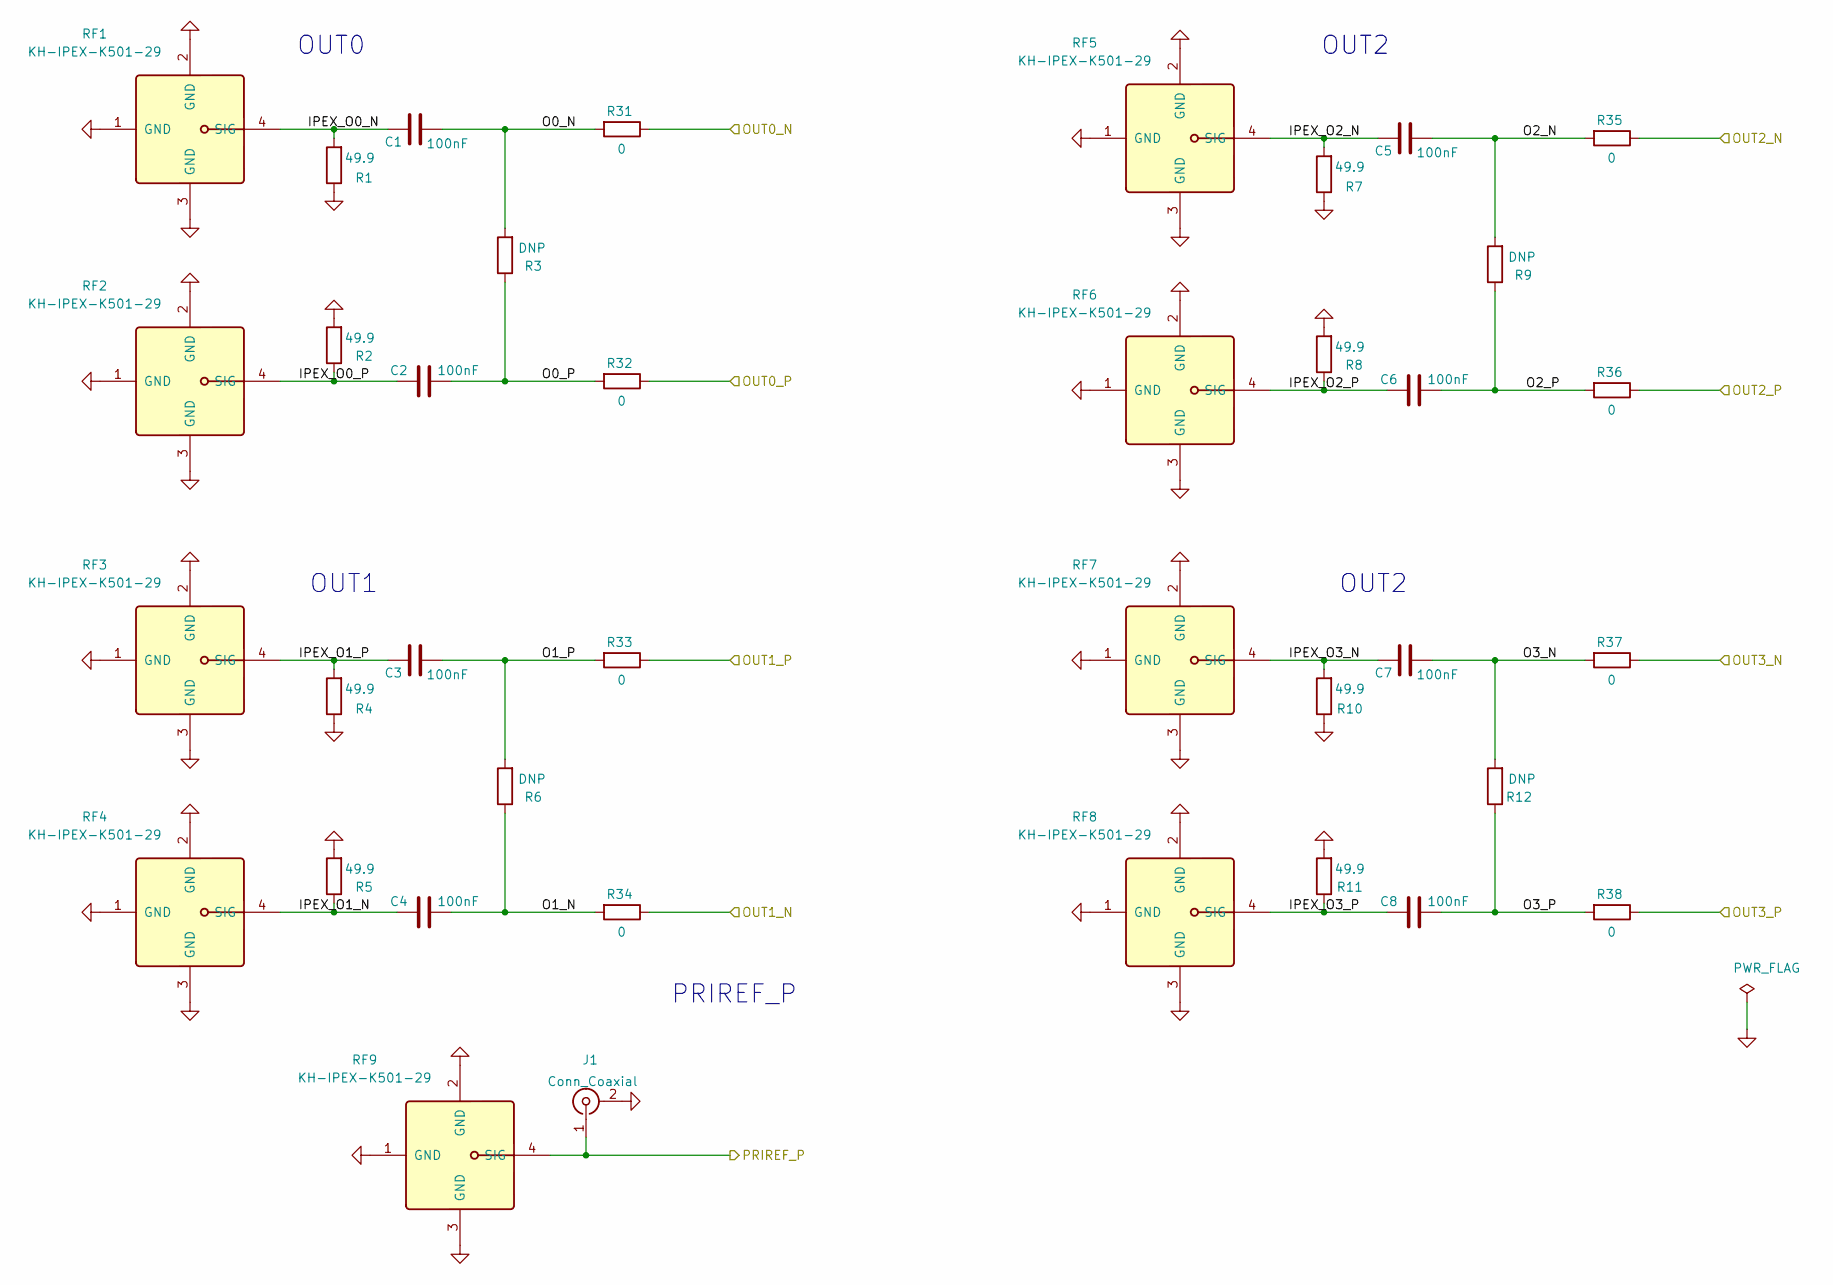
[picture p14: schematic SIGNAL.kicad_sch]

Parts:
C1, C2, C3, C4, C5, C6, C7, C8: 100nF; C_0402_1005Metric
J1: Conn_Coaxial; SMA_Amphenol_132134-11_Vertical
R1, R2, R4, R5, R7, R8, R10, R11: 49.9; R_0402_1005Metric
R3, R6, R9, R12: DNP; R_0402_1005Metric
R31, R32, R33, R34, R35, R36, R37, R38: 0; R_0402_1005Metric
RF1, RF2, RF3, RF4, RF5, RF6, RF7, RF8, RF9: KH-IPEX-K501-29; Manufacturer Part KH-IPEX-K501-29; LCSC C411563

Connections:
/LMK5B12204/OUT0_N: R31.1; also elsewhere on the board
/LMK5B12204/OUT0_P: R32.1; also elsewhere on the board
/LMK5B12204/OUT1_N: R34.1; also elsewhere on the board
/LMK5B12204/OUT1_P: R33.1; also elsewhere on the board
/LMK5B12204/OUT2_N: R35.1; also elsewhere on the board
/LMK5B12204/OUT2_P: R36.1; also elsewhere on the board
/LMK5B12204/OUT3_N: R37.1; also elsewhere on the board
/LMK5B12204/OUT3_P: R38.1; also elsewhere on the board
/LMK5B12204/PRIREF_P: J1.1 (In), RF9.4 (SIG); also elsewhere on the board
/SIGNAL/IPEX_O0_N: C1.1, R1.2, RF1.4 (SIG)
/SIGNAL/IPEX_O0_P: C2.2, R2.1, RF2.4 (SIG)
/SIGNAL/IPEX_O1_N: C4.2, R5.1, RF4.4 (SIG)
/SIGNAL/IPEX_O1_P: C3.1, R4.2, RF3.4 (SIG)
/SIGNAL/IPEX_O2_N: C5.1, R7.2, RF5.4 (SIG)
/SIGNAL/IPEX_O2_P: C6.2, R8.1, RF6.4 (SIG)
/SIGNAL/IPEX_O3_N: C7.1, R10.2, RF7.4 (SIG)
/SIGNAL/IPEX_O3_P: C8.2, R11.1, RF8.4 (SIG)
/SIGNAL/O0_N: C1.2, R3.2, R31.2
/SIGNAL/O0_P: C2.1, R3.1, R32.2
/SIGNAL/O1_N: C4.1, R6.1, R34.2
/SIGNAL/O1_P: C3.2, R6.2, R33.2
/SIGNAL/O2_N: C5.2, R9.2, R35.2
/SIGNAL/O2_P: C6.1, R9.1, R36.2
/SIGNAL/O3_N: C7.2, R12.2, R37.2
/SIGNAL/O3_P: C8.1, R12.1, R38.2
GND: J1.2 (Ext), R1.1, R2.2, R4.1, R5.2, R7.1, R8.2, R10.1, R11.2, RF1.1 (GND), RF1.2 (GND), RF1.3 (GND), RF2.1 (GND), RF2.2 (GND), RF2.3 (GND), RF3.1 (GND), RF3.2 (GND), RF3.3 (GND), RF4.1 (GND), RF4.2 (GND), RF4.3 (GND), RF5.1 (GND), RF5.2 (GND), RF5.3 (GND), RF6.1 (GND), RF6.2 (GND), RF6.3 (GND), RF7.1 (GND), RF7.2 (GND), RF7.3 (GND), RF8.1 (GND), RF8.2 (GND), RF8.3 (GND), RF9.1 (GND), RF9.2 (GND), RF9.3 (GND); also elsewhere on the board

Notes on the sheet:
PRIREF_P
OUT0
OUT2
OUT1

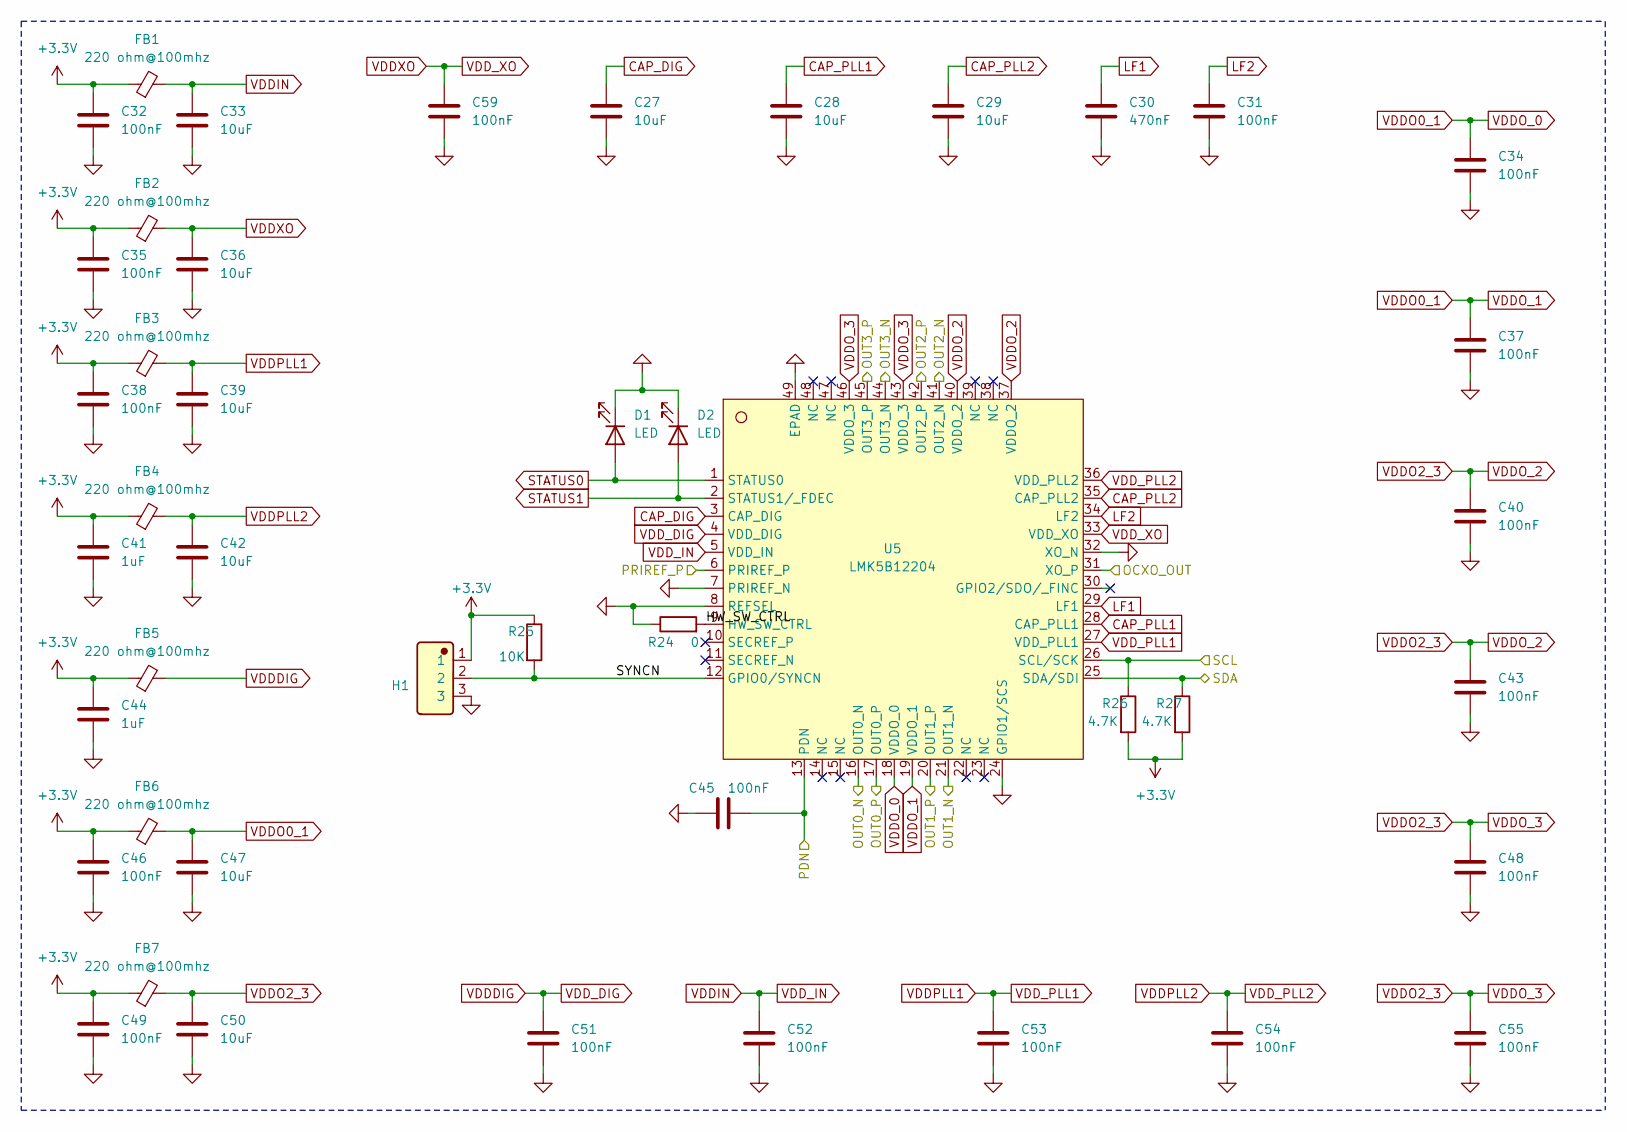
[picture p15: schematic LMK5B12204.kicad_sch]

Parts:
C27, C28, C29, C33, C36, C39, C42, C47, C50: 10uF; C_0402_1005Metric
C30: 470nF; C_0402_1005Metric
C31, C32, C34, C35, C37, C38, C40, C43, C45, C46, C48, C49, C51, C52, C53, C54, C55, C59: 100nF; C_0402_1005Metric
C41, C44: 1uF; C_0402_1005Metric
D1, D2: LED; LED_0603_1608Metric
FB1, FB2, FB3, FB4, FB5, FB6, FB7: 220 ohm@100mhz; L_0603_1608Metric
H1: HX_PH254-01-03-Z-L11_5_PCB_PIN_HEADER; Manufacturer Part HX PH254-01-03-Z-L11.5 pcb pin header; LCSC C52016391
R24: 0; R_0402_1005Metric
R25: 10K; R_0603_1608Metric
R26, R27: 4.7K; R_0603_1608Metric
U5: LMK5B12204; VQFN-48-1EP_7x7mm_P0.5mm_EP5.15x5.15mm_ThermalVias

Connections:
/DEBUG/SCL: R26.1, U5.26 (SCL/SCK); also elsewhere on the board
/DEBUG/SDA: R27.1, U5.25 (SDA/SDI); also elsewhere on the board
/LMK5B12204/HW_SW_CTRL: R24.2, U5.9 (HW_SW_CTRL)
/LMK5B12204/OUT0_N: U5.16 (OUT0_N); also elsewhere on the board
/LMK5B12204/OUT0_P: U5.17 (OUT0_P); also elsewhere on the board
/LMK5B12204/OUT1_N: U5.21 (OUT1_N); also elsewhere on the board
/LMK5B12204/OUT1_P: U5.20 (OUT1_P); also elsewhere on the board
/LMK5B12204/OUT2_N: U5.41 (OUT2_N); also elsewhere on the board
/LMK5B12204/OUT2_P: U5.42 (OUT2_P); also elsewhere on the board
/LMK5B12204/OUT3_N: U5.44 (OUT3_N); also elsewhere on the board
/LMK5B12204/OUT3_P: U5.45 (OUT3_P); also elsewhere on the board
/LMK5B12204/PDN: C45.2, U5.13 (PDN); also elsewhere on the board
/LMK5B12204/PRIREF_P: U5.6 (PRIREF_P); also elsewhere on the board
/LMK5B12204/SYNCN: H1.2, R25.2, U5.12 (GPIO0/SYNCN)
CAP_DIG: C27.2, U5.3 (CAP_DIG)
CAP_PLL1: C28.2, U5.28 (CAP_PLL1)
CAP_PLL2: C29.2, U5.35 (CAP_PLL2)
GND: C27.1, C28.1, C29.1, C30.1, C31.1, C32.1, C33.1, C34.1, C35.1, C36.1, C37.1, C38.1, C39.1, C40.1, C41.1, C42.1, C43.1, C44.1, C45.1, C46.1, C47.1, C48.1, C49.1, C50.1, C51.1, C52.1, C53.1, C54.1, C55.1, C59.1, D1.1 (K), D2.1 (K), H1.3, R24.1, U5.7 (PRIREF_N), U5.8 (REFSEL), U5.24 (GPIO1/SCS), U5.32 (XO_N), U5.49 (EPAD); also elsewhere on the board
LF1: C30.2, U5.29 (LF1)
LF2: C31.2, U5.34 (LF2)
OCXO_OUT: U5.31 (XO_P); also elsewhere on the board
STATUS0: D1.2 (A), U5.1 (STATUS0)
STATUS1: D2.2 (A), U5.2 (STATUS1/_FDEC)
VDDDIG: C51.2, FB5.2, U5.4 (VDD_DIG)
VDDIN: C33.2, C52.2, FB1.2, U5.5 (VDD_IN)
VDDO0_1: C34.2, C37.2, C47.2, FB6.2, U5.18 (VDDO_0), U5.19 (VDDO_1)
VDDO2_3: C40.2, C43.2, C48.2, C50.2, C55.2, FB7.2, U5.37 (VDDO_2), U5.40 (VDDO_2), U5.43 (VDDO_3), U5.46 (VDDO_3)
VDDPLL1: C39.2, C53.2, FB3.2, U5.27 (VDD_PLL1)
VDDPLL2: C42.2, C54.2, FB4.2, U5.36 (VDD_PLL2)
VDDXO: C36.2, C59.2, FB2.2, U5.33 (VDD_XO)

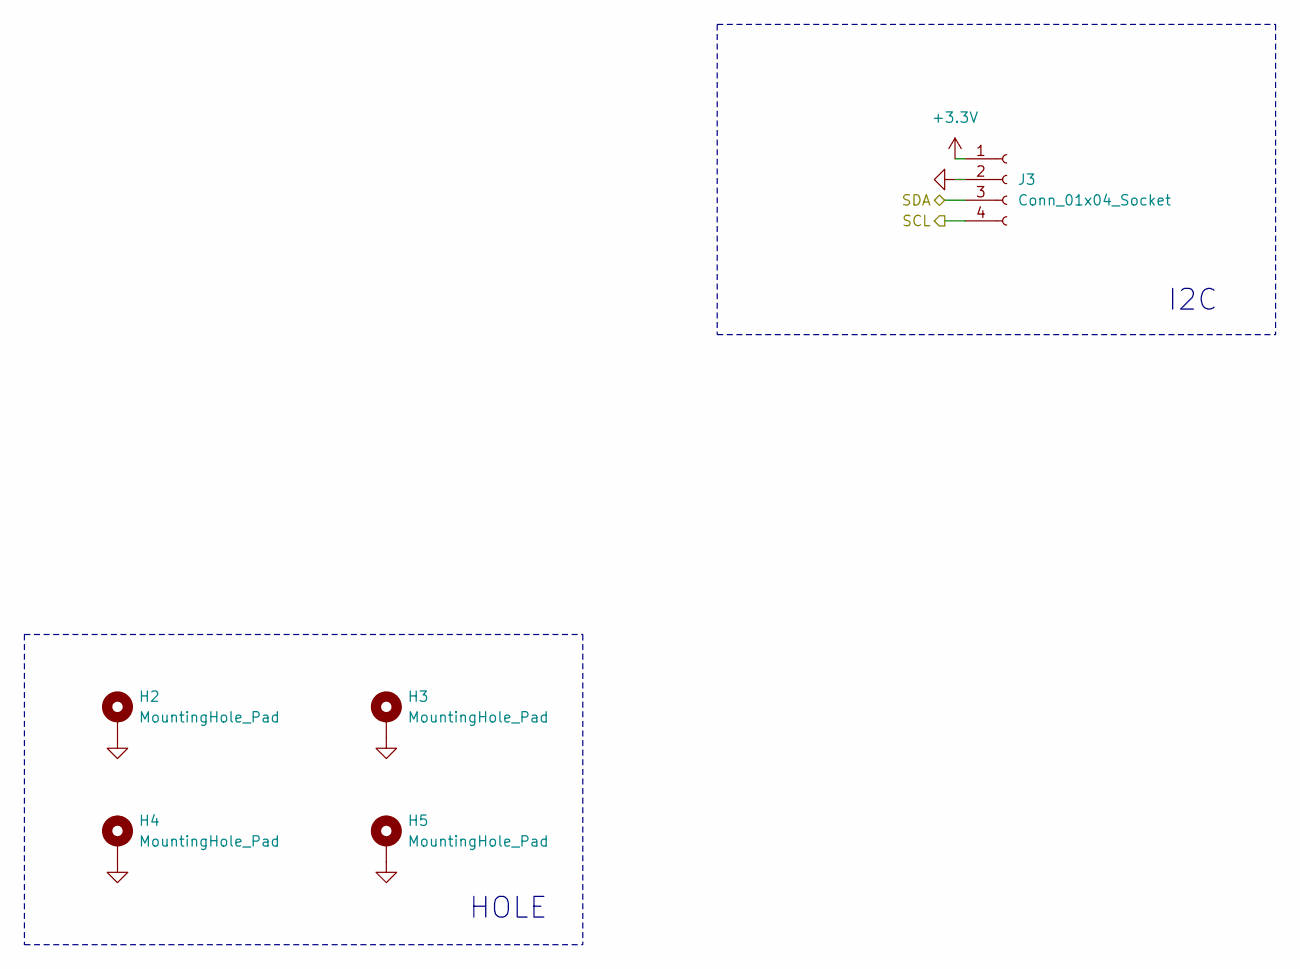
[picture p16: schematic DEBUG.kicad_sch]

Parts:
H2, H3, H4, H5: MountingHole_Pad; MountingHole_3.2mm_M3_Pad
J3: Conn_01x04_Socket; PinHeader_1x04_P2.54mm_Vertical

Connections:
/DEBUG/SCL: J3.4; also elsewhere on the board
/DEBUG/SDA: J3.3; also elsewhere on the board
GND: H2.1 (1_1), H3.1 (1_1), H4.1 (1_1), H5.1 (1_1), J3.2; also elsewhere on the board

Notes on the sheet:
I2C
HOLE

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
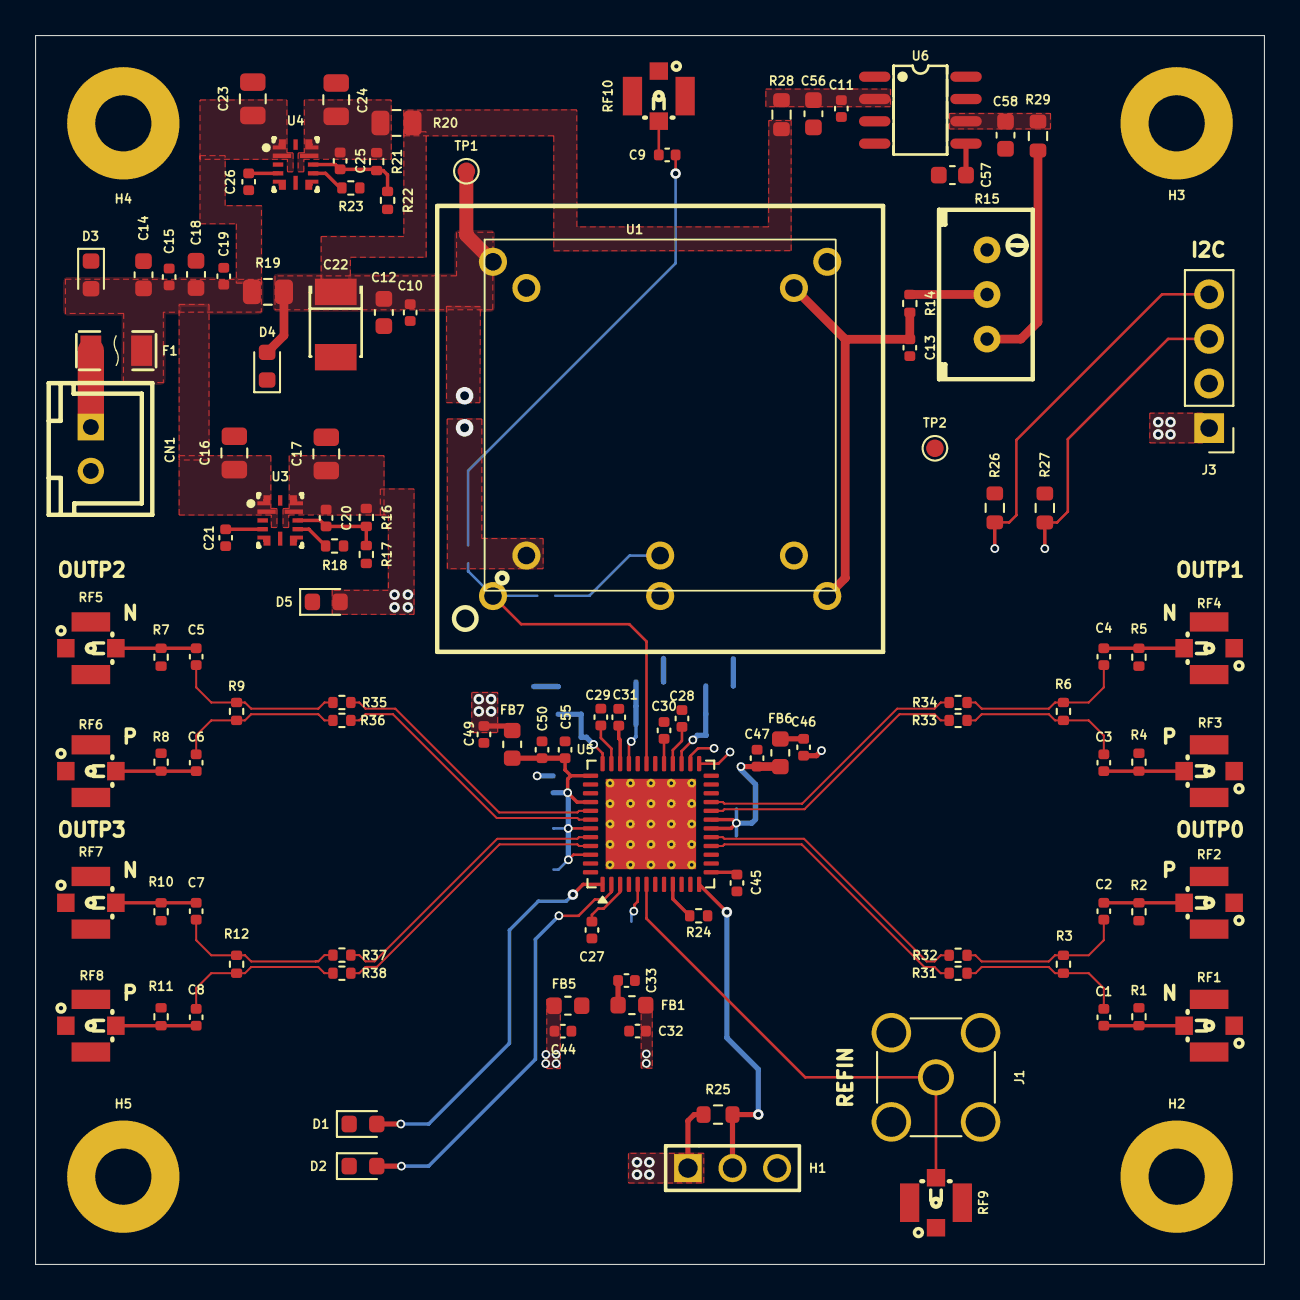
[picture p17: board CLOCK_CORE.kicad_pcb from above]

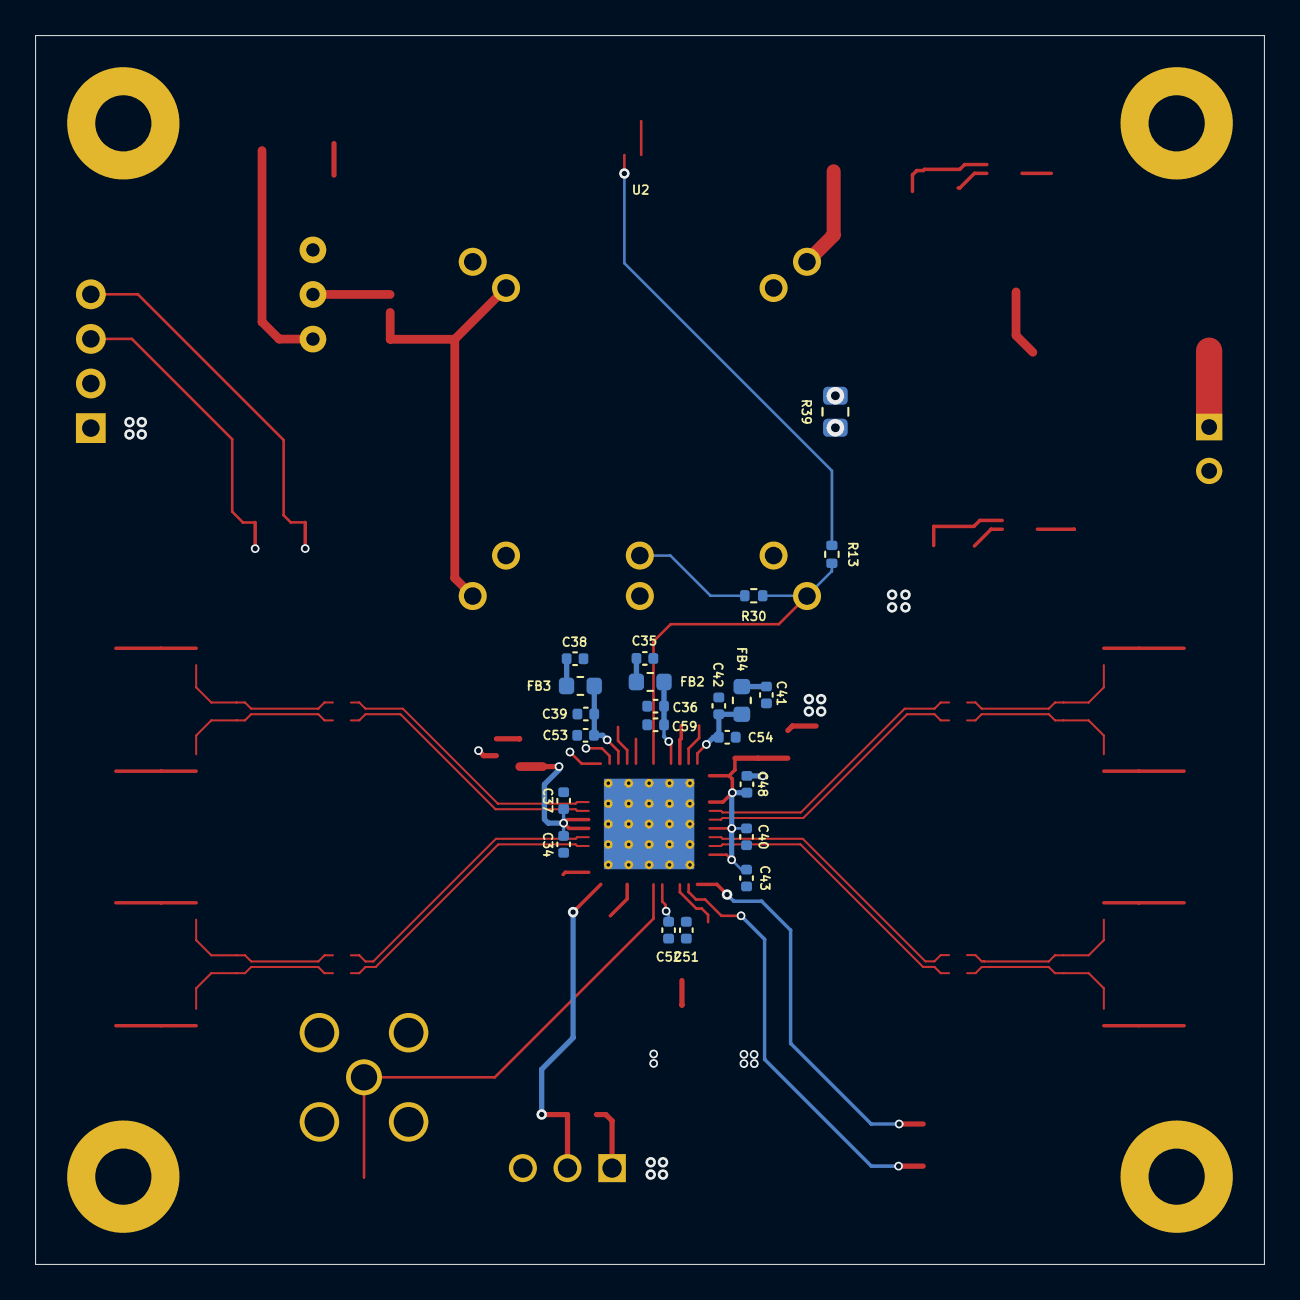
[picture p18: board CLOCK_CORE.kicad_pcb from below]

Board: 4 copper layers, 70.0 x 70.0 mm, 137 parts (22 on the bottom side), 66 nets.

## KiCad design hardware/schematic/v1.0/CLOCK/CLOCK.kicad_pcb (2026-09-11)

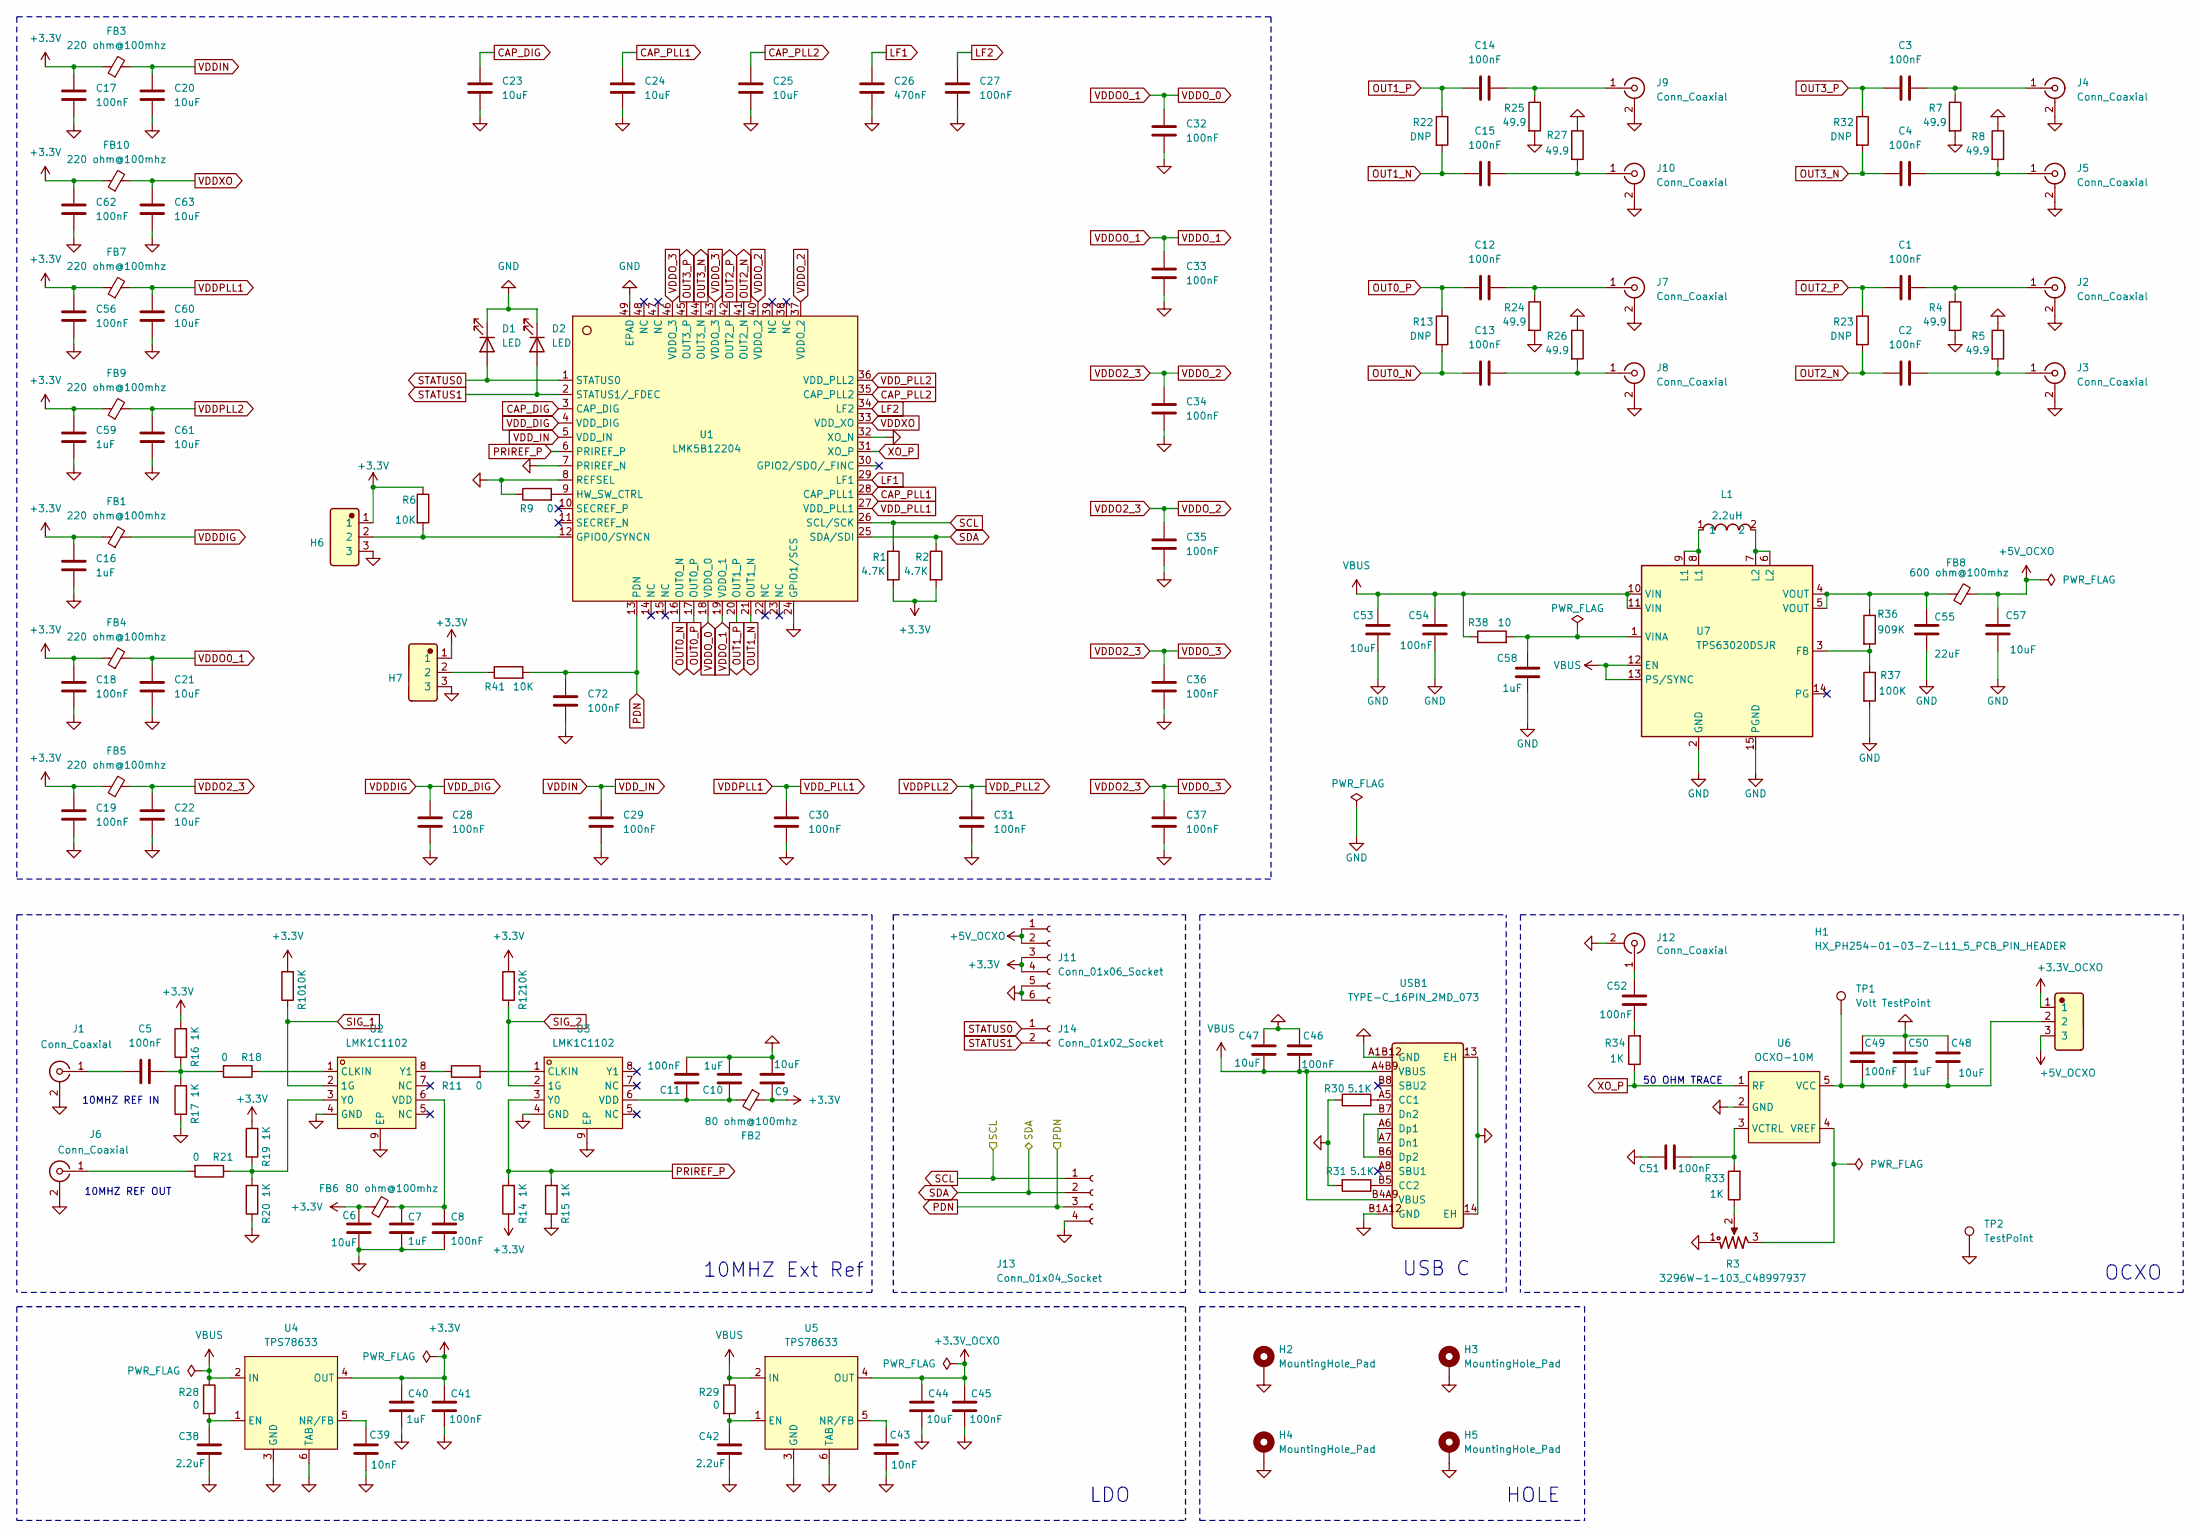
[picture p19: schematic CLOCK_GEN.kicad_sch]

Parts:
C1, C2, C3, C4, C5, C8, C11, C12, C13, C14, C15, C17, C18, C19, C27, C28, C29, C30, C31, C32, C33, C34, C35, C36, C37, C41, C45, C46, C49, C51, C52, C54, C56, C62, C72: 100nF; C_0402_1005Metric
C6, C9, C20, C21, C22, C23, C24, C25, C47, C60, C61, C63: 10uF; C_0402_1005Metric
C7, C10, C16, C40, C50, C59: 1uF; C_0402_1005Metric
C26: 470nF; C_0402_1005Metric
C38, C42: 2.2uF; C_0603_1608Metric
C39, C43: 10nF; C_0402_1005Metric
C44: 10uF; C_0805_2012Metric
C48, C53, C57: 10uF; C_0603_1608Metric
C55: 22uF; C_0805_2012Metric
C58: 1uF; C_0603_1608Metric
D1, D2: LED; LED_0603_1608Metric
FB1, FB3, FB4, FB5, FB7, FB9, FB10: 220 ohm@100mhz; L_0603_1608Metric
FB2, FB6: 80 ohm@100mhz; L_0603_1608Metric
FB8: 600 ohm@100mhz; L_0603_1608Metric
H1, H6, H7: HX_PH254-01-03-Z-L11_5_PCB_PIN_HEADER; Manufacturer Part HX PH254-01-03-Z-L11.5 pcb pin header; LCSC C52016391
H2, H3, H4, H5: MountingHole_Pad; MountingHole_3.2mm_M3_Pad
J1, J2, J3, J4, J5, J6, J7, J8, J9, J10, J12: Conn_Coaxial; SMA_Amphenol_132289_EdgeMount
J11: Conn_01x06_Socket; PinSocket_1x06_P2.54mm_Vertical
J13: Conn_01x04_Socket; PinHeader_1x04_P2.54mm_Vertical
J14: Conn_01x02_Socket; PinSocket_1x02_P2.54mm_Vertical
L1: 2.2uH; FNR4030S2R2MT; Manufacturer Part FNR4030S2R2MT; LCSC C167869
R1, R2: 4.7K; R_0603_1608Metric
R3: 3296W-1-103_C48997937; Manufacturer Part 3296W-1-103; LCSC C48997937
R4, R5, R7, R8, R24, R25, R26, R27: 49.9; R_0402_1005Metric
R6: 10K; R_0603_1608Metric
R9, R11, R18, R21, R28, R29: 0; R_0402_1005Metric
R10, R12, R41: 10K; R_0402_1005Metric
R13, R22, R23, R32: DNP; R_0402_1005Metric
R14, R15, R16, R17, R19, R20, R33, R34: 1K; R_0402_1005Metric
R30, R31: 5.1K; R_0402_1005Metric
R36: 909K; R_0603_1608Metric
R37: 100K; R_0603_1608Metric
R38: 10; R_0402_1005Metric
TP1: Volt TestPoint; TestPoint_Pad_D1.0mm
TP2: TestPoint; TestPoint_Loop_D1.80mm_Drill1.0mm_Beaded
U1: LMK5B12204; VQFN-48-1EP_7x7mm_P0.5mm_EP5.15x5.15mm_ThermalVias
U2, U3: LMK1C1102; WSON-8-1EP_2x2mm_P0.5mm_EP0.9x1.6mm
U4, U5: TPS78633; TPS78633DCQR
U6: OCXO-10M; DOPFITKR2-10M
U7: TPS63020DSJR
USB1: TYPE-C_16PIN_2MD_073; Manufacturer Part TYPE-C 16PIN 2MD(073); LCSC C2765186

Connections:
+3.3V: C6.2, C9.2, C16.2, C17.2, C18.2, C19.2, C40.1, C41.1, C56.2, C59.2, C62.2, FB1.1, FB2.1, FB3.1, FB4.1, FB5.1, FB6.1, FB7.1, FB9.1, FB10.1, H6.1, H7.1, J11.3, J11.4, R1.2, R2.2, R6.1, R10.2, R12.2, R14.1, R16.2, R19.2, U4.4 (OUT); also elsewhere on the board
+3.3V_OCXO: C44.1, C45.1, H1.1, U5.4 (OUT)
+5V_OCXO: C57.1, FB8.2, H1.3, J11.1, J11.2
CAP_DIG: C23.2, U1.3 (CAP_DIG)
CAP_PLL1: C24.2, U1.28 (CAP_PLL1)
CAP_PLL2: C25.2, U1.35 (CAP_PLL2)
GND: C6.1, C7.1, C8.1, C9.1, C10.1, C11.1, C16.1, C17.1, C18.1, C19.1, C20.1, C21.1, C22.1, C23.1, C24.1, C25.1, C26.1, C27.1, C28.1, C29.1, C30.1, C31.1, C32.1, C33.1, C34.1, C35.1, C36.1, C37.1, C38.1, C39.2, C40.2, C41.2, C42.1, C43.2, C44.2, C45.2, C46.2, C47.1, C48.1, C49.2, C50.1, C51.2, C53.2, C54.2, C55.2, C56.1, C57.2, C58.2, C59.1, C60.1, C61.1, C62.1, C63.1, C72.1, D1.1 (K), D2.1 (K), H2.1 (1_1), H3.1 (1_1), H4.1 (1_1), H5.1 (1_1), H6.3, H7.3, J1.2 (Ext), J2.2 (Ext), J3.2 (Ext), J4.2 (Ext), J5.2 (Ext), J6.2 (Ext), J7.2 (Ext), J8.2 (Ext), J9.2 (Ext), J10.2 (Ext), J11.5, J11.6, J12.2 (Ext), J13.4, R3.1, R4.2, R5.1, R7.2, R8.1, R9.1, R15.1, R17.1, R20.1, R24.2, R25.2, R26.1, R27.1, R30.1, R31.2, R37.2, TP2.1 (1_1), U1.7 (PRIREF_N), U1.8 (REFSEL), U1.24 (GPIO1/SCS), U1.32 (XO_N), U1.49 (EPAD), U2.4 (GND), U2.9 (EP), U3.4 (GND), U3.9 (EP), U4.3 (GND), U4.6 (TAB), U5.3 (GND), U5.6 (TAB), U6.2 (GND), U7.2 (GND), U7.15 (PGND), USB1.13 (EH), USB1.14 (EH), USB1.A1B12 (GND), USB1.B1A12 (GND); also elsewhere on the board
LF1: C26.2, U1.29 (LF1)
LF2: C27.2, U1.34 (LF2)
unnamed: C5.2, R16.1, R17.2, R18.2
unnamed: C52.2, R34.2
unnamed: C55.1, FB8.1, R36.1, U7.4 (VOUT), U7.5 (VOUT)
unnamed: H7.2, R41.1
unnamed: C5.1, J1.1 (In)
unnamed: C1.2, J2.1 (In), R4.1
unnamed: C2.2, J3.1 (In), R5.2
unnamed: C3.2, J4.1 (In), R7.1
unnamed: C4.1, J5.1 (In), R8.2
unnamed: J6.1 (In), R21.2
unnamed: C12.2, J7.1 (In), R24.1
unnamed: C13.2, J8.1 (In), R26.2
unnamed: C14.2, J9.1 (In), R25.1
unnamed: C15.1, J10.1 (In), R27.2
unnamed: C52.1, J12.1 (In)
unnamed: L1.1, U7.8 (L1), U7.9 (L1)
unnamed: L1.2, U7.6 (L2), U7.7 (L2)
unnamed: R3.2, R33.1
unnamed: H6.2, R6.2, U1.12 (GPIO0/SYNCN)
unnamed: R9.2, U1.9 (HW_SW_CTRL)
unnamed: R18.1, U2.1 (CLKIN)
unnamed: C7.2, C8.2, FB6.2, U2.6 (VDD)
unnamed: R19.1, R20.2, R21.1, U2.3 (Y0)
unnamed: R11.1, U2.8 (Y1)
unnamed: R11.2, U3.1 (CLKIN)
unnamed: C10.2, C11.2, FB2.2, U3.6 (VDD)
unnamed: C38.2, R28.2, U4.1 (EN)
unnamed: C39.1, U4.5 (NR/FB)
unnamed: C42.2, R29.2, U5.1 (EN)
unnamed: C43.1, U5.5 (NR/FB)
unnamed: C48.2, C49.1, C50.2, H1.2, TP1.1 (1_1), U6.5 (VCC)
unnamed: C51.1, R33.2, U6.3 (VCTRL)
unnamed: R3.3, U6.4 (VREF)
unnamed: R36.2, R37.1, U7.3 (FB)
unnamed: C58.1, R38.2, U7.1 (VINA)
unnamed: R30.2, USB1.A5 (CC1)
unnamed: R31.1, USB1.B5 (CC2)
unnamed: USB1.A6 (Dp1), USB1.A7 (Dn1)
unnamed: USB1.B6 (Dp2), USB1.B7 (Dn2)
OUT0_N: C13.1, R13.2, U1.16 (OUT0_N)
OUT0_P: C12.1, R13.1, U1.17 (OUT0_P)
OUT1_N: C15.2, R22.2, U1.21 (OUT1_N)
OUT1_P: C14.1, R22.1, U1.20 (OUT1_P)
OUT2_N: C2.1, R23.2, U1.41 (OUT2_N)
OUT2_P: C1.1, R23.1, U1.42 (OUT2_P)
OUT3_N: C4.2, R32.2, U1.44 (OUT3_N)
OUT3_P: C3.1, R32.1, U1.45 (OUT3_P)
PDN: C72.2, J13.3, R41.2, U1.13 (PDN); also elsewhere on the board
PRIREF_P: R14.2, R15.2, U1.6 (PRIREF_P), U3.3 (Y0)
SCL: J13.1, R1.1, U1.26 (SCL/SCK); also elsewhere on the board
SDA: J13.2, R2.1, U1.25 (SDA/SDI); also elsewhere on the board
SIG_1: R10.1, U2.2 (1G)
SIG_2: R12.1, U3.2 (1G)
STATUS0: D1.2 (A), J14.1, U1.1 (STATUS0)
STATUS1: D2.2 (A), J14.2, U1.2 (STATUS1/_FDEC)
VBUS: C46.1, C47.2, C53.1, C54.1, R28.1, R29.1, R38.1, U4.2 (IN), U5.2 (IN), U7.10 (VIN), U7.11 (VIN), U7.12 (EN), U7.13 (PS/SYNC), USB1.A4B9 (VBUS), USB1.B4A9 (VBUS)
VDDDIG: C28.2, FB1.2, U1.4 (VDD_DIG)
VDDIN: C20.2, C29.2, FB3.2, U1.5 (VDD_IN)
VDDO0_1: C21.2, C32.2, C33.2, FB4.2, U1.18 (VDDO_0), U1.19 (VDDO_1)
VDDO2_3: C22.2, C34.2, C35.2, C36.2, C37.2, FB5.2, U1.37 (VDDO_2), U1.40 (VDDO_2), U1.43 (VDDO_3), U1.46 (VDDO_3)
VDDPLL1: C30.2, C60.2, FB7.2, U1.27 (VDD_PLL1)
VDDPLL2: C31.2, C61.2, FB9.2, U1.36 (VDD_PLL2)
VDDXO: C63.2, FB10.2, U1.33 (VDD_XO)
XO_P: R34.1, U1.31 (XO_P), U6.1 (RF)

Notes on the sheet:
10MHZ REF IN
USB C
LDO
50 OHM TRACE
10MHZ Ext Ref
10MHZ REF OUT
HOLE
OCXO

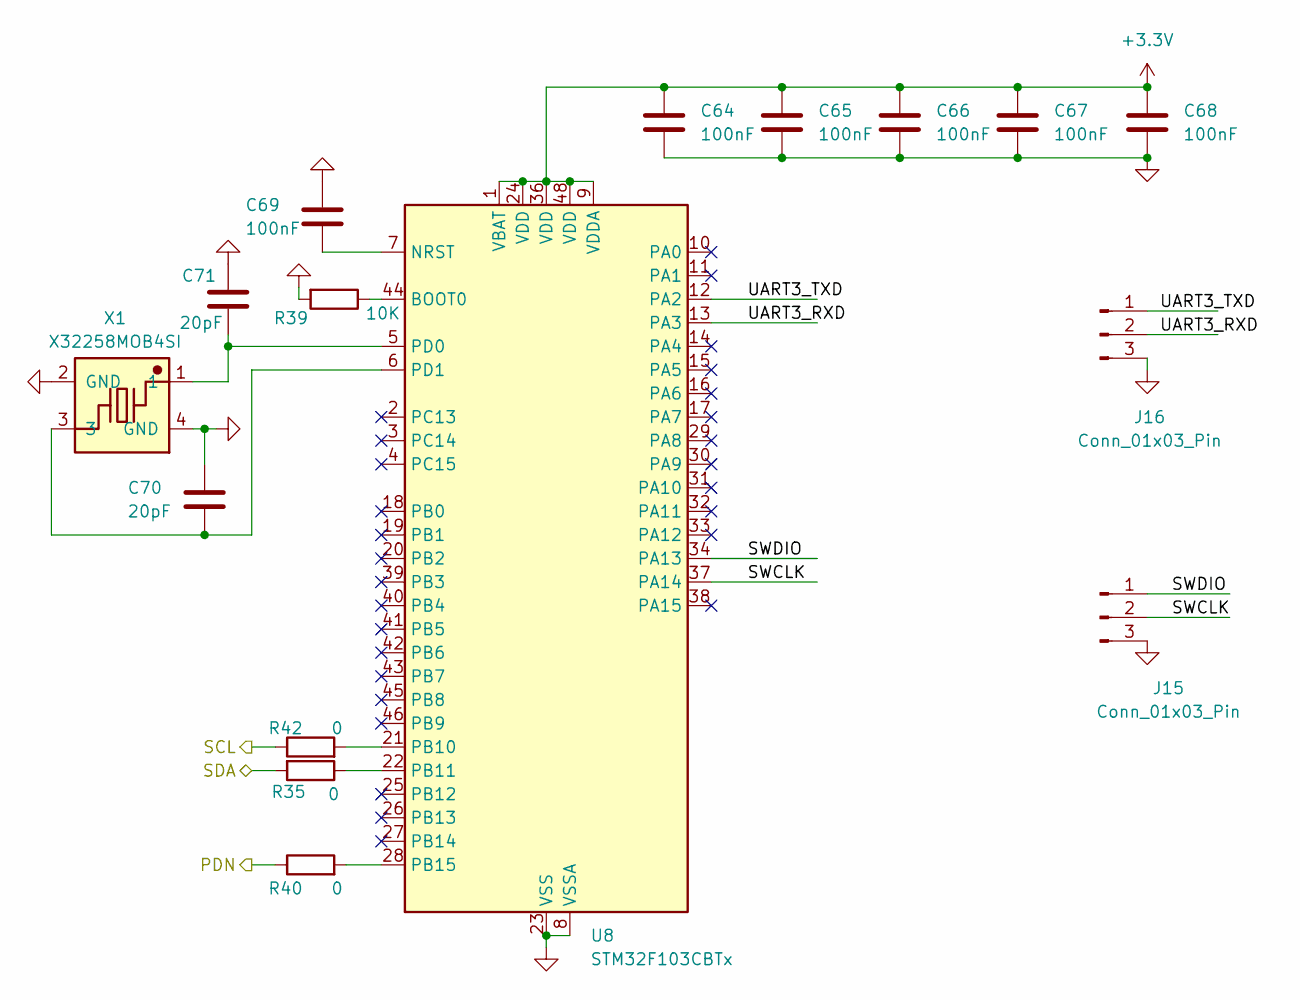
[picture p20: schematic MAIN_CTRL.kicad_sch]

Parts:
C64, C65, C66, C67, C68, C69: 100nF; C_0402_1005Metric
C70, C71: 20pF; C_0402_1005Metric
J15, J16: Conn_01x03_Pin; PinHeader_1x03_P2.54mm_Vertical
R35, R40, R42: 0; R_0402_1005Metric
R39: 10K; R_0603_1608Metric
U8: STM32F103CBTx; LQFP-48_7x7mm_P0.5mm
X1: X32258MOB4SI; Manufacturer Part X32258MOB4SI; LCSC C2682775

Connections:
+3.3V: C64.2, C65.2, C66.2, C67.2, C68.2, U8.1 (VBAT), U8.9 (VDDA), U8.24 (VDD), U8.36 (VDD), U8.48 (VDD); also elsewhere on the board
/MAIN_CTRL/SWCLK: J15.2, U8.37 (PA14)
/MAIN_CTRL/SWDIO: J15.1, U8.34 (PA13)
/MAIN_CTRL/UART3_RXD: J16.2, U8.13 (PA3)
/MAIN_CTRL/UART3_TXD: J16.1, U8.12 (PA2)
GND: C64.1, C65.1, C66.1, C67.1, C68.1, C69.2, C70.2, C71.2, J15.3, J16.3, R39.2, U8.8 (VSSA), U8.23 (VSS), U8.35 (VSS), U8.47 (VSS), X1.2 (GND), X1.4 (GND); also elsewhere on the board
unnamed: R39.1, U8.44 (BOOT0)
unnamed: C69.1, U8.7 (NRST)
unnamed: R42.2, U8.21 (PB10)
unnamed: R35.1, U8.22 (PB11)
unnamed: R40.2, U8.28 (PB15)
unnamed: C71.1, U8.5 (PD0), X1.1
unnamed: C70.1, U8.6 (PD1), X1.3
PDN: R40.1; also elsewhere on the board
SCL: R42.1; also elsewhere on the board
SDA: R35.2; also elsewhere on the board

Board: 4 copper layers, 162 parts (14 on the bottom side), 84 nets, no tracks yet.

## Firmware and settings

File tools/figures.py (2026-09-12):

#!/usr/bin/env python3
"""
md2pdf.py 的配套绘图模块：为硬件文档生成矢量示意图。

在 Markdown 中用 `@fig:名称 图题` 单独一行引用，例如:
    @fig:stackup 图 2　四层板叠层剖面（1.6 mm）

纯 reportlab.graphics 矢量绘制，不依赖外部图片文件。
"""

from reportlab.graphics.shapes import Circle, Drawing, Line, PolyLine, Polygon, Rect, String
from reportlab.lib import colors
from reportlab.lib.styles import ParagraphStyle
from reportlab.lib.units import mm
from reportlab.platypus import Paragraph, Spacer

W = 170 * mm  # 与正文同宽

FONT, BOLD = 'NotoSC', 'NotoSC-Bold'
ACCENT = colors.HexColor('#1a5f9c')
DARK = colors.HexColor('#1a1a1a')
GREY = colors.HexColor('#666666')
COPPER = colors.HexColor('#c8801f')
DIEL = colors.HexColor('#d9e6c9')
CORE_C = colors.HexColor('#c3d6ae')
MASK = colors.HexColor('#2f7a4f')
RED = colors.HexColor('#c0392b')
AMBER = colors.HexColor('#d68910')
GREEN = colors.HexColor('#1e8449')

CAP = ParagraphStyle('cap', fontName=FONT, fontSize=8.5, leading=12.5,
                     textColor=GREY, alignment=1, spaceBefore=3, spaceAfter=10)


def _txt(d, x, y, s, size=8, font=FONT, fill=DARK, anchor='start'):
    d.add(String(x, y, s, fontName=font, fontSize=size,
                 fillColor=fill, textAnchor=anchor))


def _box(d, x, y, w, h, fill, stroke=None, sw=0.6, r=None):
    kw = dict(fillColor=fill, strokeColor=stroke or colors.HexColor('#94a7b8'),
              strokeWidth=sw)
    if r:
        kw['rx'] = kw['ry'] = r
    d.add(Rect(x, y, w, h, **kw))


def _arrow(d, x1, y1, x2, y2, color=ACCENT, sw=1.0, head=4):
    """带箭头的直线（仅支持水平/垂直方向的箭头）。"""
    d.add(Line(x1, y1, x2, y2, strokeColor=color, strokeWidth=sw))
    if abs(x2 - x1) < 0.01:                       # 垂直
        s = -head if y2 < y1 else head
        d.add(Polygon([x2, y2, x2 - head * 0.6, y2 - s, x2 + head * 0.6, y2 - s],
                      fillColor=color, strokeColor=color))
    else:                                          # 水平
        s = -head if x2 < x1 else head
        d.add(Polygon([x2, y2, x2 - s, y2 - head * 0.6, x2 - s, y2 + head * 0.6],
                      fillColor=color, strokeColor=color))


# ---------------------------------------------------------------- 图：流程总览

def flow():
    """十阶段流程总览，边框颜色表示返工代价。"""
    d = Drawing(W, 268)
    stages = [
        ('一', '开工前决策', '层数 / 板厂 / 板框', RED),
        ('二', '原理图收尾', '批注 / 封装 / ERC', AMBER),
        ('三', '电路板配置', '叠层 / 规则 / 网络类', RED),
        ('四', '更新 PCB', '从原理图导入', GREEN),
        ('五', '板框与结构', 'Edge.Cuts / 安装孔', AMBER),
        ('六', '布局', '摆放 / 分区 / 锁定', RED),
        ('七', '布线', '优先级 / 阻抗 / 等长', AMBER),
        ('八', '铺铜与回流', '平面 / 缝合过孔', GREEN),
        ('九', '检查', 'DRC / 目视 / 3D', ACCENT),
        ('十', '制造输出', 'Gerber / 钻孔 / BOM', GREEN),
    ]
    bw, bh, gx, gy = 218, 38, 24, 8
    x0, y0 = 4, 268 - bh - 16
    for i, (num, name, sub, col) in enumerate(stages):
        cx = x0 + (i % 2) * (bw + gx)
        cy = y0 - (i // 2) * (bh + gy)
        _box(d, cx, cy, bw, bh, colors.white, col, 1.1, r=4)
        d.add(Rect(cx, cy, 4, bh, fillColor=col, strokeColor=col))
        _txt(d, cx + 12, cy + bh - 15, '阶段' + num, 8.5, BOLD, col)
        _txt(d, cx + 52, cy + bh - 15, name, 9.5, BOLD, DARK)
        _txt(d, cx + 12, cy + 8, sub, 7.5, FONT, GREY)
        if i % 2 == 0:                              # 左 -> 右
            _arrow(d, cx + bw + 3, cy + bh / 2, cx + bw + gx - 3, cy + bh / 2, GREY, .8)
        elif i < len(stages) - 1:                   # 右 -> 下一行左
            _arrow(d, cx + bw / 2, cy - 1, cx + bw / 2, cy - gy + 1, GREY, .8)

    ly = 12
    _txt(d, 4, ly, '返工代价：', 8, BOLD, DARK)
    for i, (c, t) in enumerate(((RED, '极高 / 高'), (AMBER, '高 / 中'),
                                (GREEN, '低'), (ACCENT, '检查环节'))):
        bx = 52 + i * 96
        d.add(Rect(bx, ly - 1, 16, 7, fillColor=colors.white, strokeColor=c, strokeWidth=1.1))
        _txt(d, bx + 21, ly, t, 8, FONT, GREY)
    return d


# ---------------------------------------------------------------- 图：叠层剖面

def stackup():
    """四层板 1.6 mm 叠层剖面（嘉立创 JLC04161H-7628）。"""
    d = Drawing(W, 232)
    layers = [
        ('阻焊 / Solder Mask', '0.01 mm', MASK, 7, ''),
        ('F.Cu  (1 oz)', '0.035 mm', COPPER, 11, '信号层：射频、差分时钟'),
        ('Prepreg 7628', '0.2104 mm', DIEL, 26, 'Dk 4.4　← 决定 F.Cu 阻抗'),
        ('In1.Cu  (0.5 oz)', '0.0152 mm', COPPER, 9, 'GND 完整平面（不可分割）'),
        ('Core', '1.065 mm', CORE_C, 52, 'Dk 4.2'),
        ('In2.Cu  (0.5 oz)', '0.0152 mm', COPPER, 9, 'PWR 电源平面'),
        ('Prepreg 7628', '0.2104 mm', DIEL, 26, 'Dk 4.4'),
        ('B.Cu  (1 oz)', '0.035 mm', COPPER, 11, '次信号层'),
        ('阻焊 / Solder Mask', '0.01 mm', MASK, 7, ''),
    ]
    lx, lw = 92, 210
    y = 232 - 26
    for name, th, col, h, note in layers:
        y -= h
        _box(d, lx, y, lw, h, col, colors.HexColor('#7d8f9e'), 0.5)
        _txt(d, lx - 6, y + h / 2 - 3, name, 7.5, FONT, DARK, 'end')
        _txt(d, lx + lw + 8, y + h / 2 - 3, th, 7.5, BOLD, ACCENT)
        if note:
            _txt(d, lx + lw + 62, y + h / 2 - 3, note, 7.5, FONT, GREY)

    top, bot = 232 - 26, y
    d.add(Line(lx - 76, top, lx - 76, bot, strokeColor=ACCENT, strokeWidth=0.8))
    for yy in (top, bot):
        d.add(Line(lx - 80, yy, lx - 72, yy, strokeColor=ACCENT, strokeWidth=0.8))
    _txt(d, lx - 84, (top + bot) / 2 - 3, '1.6 mm', 8, BOLD, ACCENT, 'end')

    # 高亮 F.Cu 与 In1.Cu 之间的关键间距
    ky1 = top - 7 - 11
    ky2 = ky1 - 26
    d.add(Line(lx + lw + 168, ky1, lx + lw + 168, ky2, strokeColor=RED, strokeWidth=0.9))
    for yy in (ky1, ky2):
        d.add(Line(lx + lw + 164, yy, lx + lw + 172, yy, strokeColor=RED, strokeWidth=0.9))
    _txt(d, lx + lw + 176, (ky1 + ky2) / 2 - 3, 'H', 8.5, BOLD, RED)

    _txt(d, 4, 8, '计算阻抗时 H 填这一段（0.2104 mm），不是板厚 1.6 mm', 8, BOLD, RED)
    return d


# ---------------------------------------------------------------- 图：微带线截面
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

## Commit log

2026-08-10 Initial commit: CLOCK 高精度频率计后端标准时钟产生模块
    [CLOCK.kicad_pcb, CLOCK.kicad_sch]
2026-08-10 Update schematic and configuration files
    [CLOCK.kicad_sch]
2026-08-10 Update schematic files and remove lock file
    [CLOCK.kicad_sch]
2026-08-10 Add new CLOCK_INT_N schematic and PCB design
    [CLOCK_INT_N.kicad_pcb, CLOCK_INT_N.kicad_sch]
2026-08-10 sch commit
    [CLOCK.kicad_sch, CLOCK_INT_N.kicad_sch]
2026-08-10 sch update commit
    [CLOCK.kicad_sch]
2026-08-20 sch update
    [CLOCK.kicad_sch]
2026-09-04 CLOCK update
    [CLOCK.kicad_pcb, CLOCK.kicad_sch]
2026-09-04 pcb update
    [CLOCK.kicad_pcb]
2026-09-05 sch and pcb update
    [CLOCK.kicad_sch]
2026-09-06 add main ctrl
    [CLOCK.kicad_sch, CLOCK_GEN.kicad_sch, MAIN_CTRL.kicad_sch]
2026-09-11 add pdf
    [CLOCK_GEN.kicad_sch]
2026-09-23 add pdf and sch update
    [CLOCK_CORE.kicad_pcb]
2026-09-24 pcb updaate
    [CLOCK_CORE.kicad_pcb]
2026-10-19 Add a current-limiting resistor, sch and pcb update
2026-11-02 gerber and bom update
2026-11-02 gerber update
2026-11-03 pcb and sch update

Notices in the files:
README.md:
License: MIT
